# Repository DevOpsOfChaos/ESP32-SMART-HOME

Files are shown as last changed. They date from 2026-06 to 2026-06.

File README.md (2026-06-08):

# ESP32 Smart Home

An open, English-language release of my ESP32-based smart home project.

This repository packages the hardware, firmware, enclosure work, local server stack, and a separate ESPHome track in a way that can be used piece by piece.

What this is not: a polished consumer product or a cloud platform. It is a local-first, technically honest system that can be reused by builders who only want one part of it.

## What is included

- custom ESP32-C3 hardware
- modular PCB designs and production artifacts
- C++ firmware built with PlatformIO
- separate ESPHome device configs for Home Assistant users
- a local MQTT server and Node-RED dashboard
- 3D-printed enclosure designs
- test scripts and verification notes

## System overview

```text
Custom firmware path
  ESP32 devices
    -> ESP-NOW
    -> Master bridge
    -> MQTT
    -> Local server
         -> Mosquitto
         -> Node-RED dashboard and logic
         -> SQLite snapshots

Separate ESPHome path
  ESPHome devices
    -> Home Assistant
    -> Optional local integrations, depending on the device config
```

## Device families

| Family | Purpose | Typical modules |
|---|---|---|
| `net_erl` | mains-powered relay node | hall light, room light, sensor extensions |
| `net_zrl` | shutter / blind controller | two relays, calibration, local buttons |
| `net_sen` | mains-powered sensor node | environmental sensing, rain input |
| `bat_sen` | battery-powered sensor node | reed contact, rain sensor, deep sleep |
| `master` | bridge node | ESP-NOW to MQTT gateway |

## Use each part independently

- Hardware only: build the PCB and enclosure files without using my firmware.
- Firmware only: reuse the PlatformIO project for your own ESP32-C3 builds.
- ESPHome only: flash the Home Assistant-friendly YAMLs and ignore the custom firmware completely.
- Server only: run the local MQTT, Node-RED, and SQLite stack as a standalone dashboard backend.

## Repository map

| Path | Purpose |
|---|---|
| `hardware/` | source boards, shared circuits, enclosures, and manufacturing exports |
| `firmware/` | PlatformIO firmware, device families, shared protocol code |
| `esphome/` | separate Home Assistant-oriented ESPHome configs and migration references |
| `server/` | local Mosquitto, Node-RED, and SQLite stack |
| `docs/` | English overview and legacy reference material |
| `tests/` | smoke tests and contract checks |

Start here if you want the shortest onboarding path:

- [Getting Started](docs/GETTING_STARTED.md)

## Quick start

Run the local dashboard stack:

```powershell
cd server
docker compose up -d
```

Open the dashboard:

```text
http://localhost:1880/ui
```

Build a firmware target:

```powershell
cd firmware
pio run -e <environment-name>
```

Validate the ESPHome configs from the repository root:

```powershell
.\scripts\check_esphome.ps1 -Device <device-name>
```

## ESPHome boundary

The `esphome/` area is not a firmware port of the custom stack. The supported public direction is simpler than that: easy-to-adopt ESPHome devices for people who want straightforward Home Assistant integration without the custom ESP-NOW or master architecture.

Some legacy MQTT-contract ESPHome files still remain in the repository as migration references. They are not the recommended public story.

## Design principle

Every major block is intentionally usable on its own. The full system is the reference implementation, not a mandatory bundle.

## Public release note

This repository is a cleaned public release. Secrets, runtime caches, and internal-only working artifacts are intentionally excluded.

## License

All rights reserved for now. The project is public for review and reuse, but no permissive license has been attached yet.

## Author

Manuel Ries

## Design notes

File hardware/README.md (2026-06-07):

# Hardware

This folder contains the physical side of the project:

- shared reference hardware
- device-specific PCB designs
- manufacturing exports
- enclosure and 3D-print models

## Start here

- [Hardware overview](00_hardwareueberblick.md)

## Main areas

- `shared/` holds reusable circuit blocks and reference components
- `bat_sen/`, `net_sen/`, `net_erl/`, and `net_zrl/` hold device families
- `3d_models/` holds enclosure work, renders, and printable models
- `fabrication/` holds production-ready exports brought in from the final project state

## How to read it

Start with the shared hardware, then move into the relevant device family. Do not assume the whole system is required. Each family is meant to stand on its own.

## Fabrication exports

The `fabrication/` folder is the handoff layer:

- `gerbers/` for PCB production
- `kicad/` for board source files and exports
- `schematics/` for PDFs and schematic handoff material
- `bom/` for bill-of-materials CSV files

## 3D printing

The enclosure work under `3d_models/` is intentionally separate from the PCB source. You can use the boards without the enclosures, or the enclosures without the full software stack.

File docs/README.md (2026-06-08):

# Documentation

This is the English documentation entry point for the public release.

## Start here

1. [Root README](../README.md)
2. [Getting Started](GETTING_STARTED.md)
3. [Hardware overview](../hardware/README.md)
4. [Firmware overview](../firmware/README.md)
5. [Server overview](../server/README.md)
6. [ESPHome overview](../esphome/README.md)

## What is in here

- public overview material
- subsystem reference pages
- a clear split between the custom firmware track and the separate ESPHome track
- an archive area for the original German reference material

## Archive

The old German notes were moved into [`archive/german-reference/`](archive/german-reference/). They are kept for historical reference only. New readers should start with the English landing pages above.

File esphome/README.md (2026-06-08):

# ESPHome

This folder is the separate ESPHome track for people who want simple Home Assistant devices.

The supported public direction is not "the same firmware architecture in YAML." It is the opposite: independent ESPHome devices that do not depend on the custom ESP-NOW transport, the master bridge, or the firmware-side MQTT contract.

## What this folder is for

- straightforward Home Assistant adoption
- device-local logic where it makes sense
- easier reuse of the hardware without adopting the custom firmware stack
- clearer separation from the custom `firmware/` architecture

## What is currently in here

Supported public direction:

- `net_erl_hall_module.yaml`
- `net_erl_hall_module_led_ring.yaml`
- `net_sen_weather_station.yaml`
- `net_zrl_shutter_module.yaml`

These configs are Home Assistant-oriented ESPHome devices using the native ESPHome API.

Legacy migration references still kept in the repo:

- `bat_sen_window_contact.yaml`
- `bat_sen_rain_sensor.yaml`
- `packages/`

Those files still use the older MQTT-contract helper packages. They remain valid, but they are not the simplified public direction anymore.

## Use

Typical workflow:

1. copy the device YAML you actually want into your ESPHome workspace
2. provide your local secrets
3. validate the config
4. flash once by cable, then use OTA
5. adopt the device in Home Assistant

## Validation

Use the Windows helper scripts to validate configuration or compile a device target.

```powershell
.\scripts\check_esphome.ps1
```

Or only validate a specific device:

```powershell
.\scripts\check_esphome.ps1 -Device net_erl_hall_module
```

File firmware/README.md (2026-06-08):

# Firmware

This folder contains the PlatformIO firmware for the custom ESP32-C3 line.

It is the main code path for the project when you want the full custom stack:

- ESP-NOW device communication
- a master bridge to MQTT
- shared protocol and provisioning helpers
- concrete device targets for each hardware family

## Layout

- `src/basetypes/` contains reusable runtime bases for each device family
- `src/devices/` contains concrete device builds
- `include/` contains shared headers and local secret templates
- `lib/` contains protocol, provisioning, and storage helpers
- `scripts/` contains build helpers

## Use this track when

Use `firmware/` if you want full control over timing, provisioning, transport, and the device model.

If you mainly want simpler Home Assistant devices, use the separate `esphome/` folder instead. That is not another variant of this firmware stack. It is its own track.

## Build

Build a target with PlatformIO:

```powershell
cd firmware
pio run -e <environment-name>
```

Upload follows the same pattern once the target is selected.

## Secrets

Do not commit `include/Secrets.h`. Keep the example file as the template and copy it locally when needed.

## What matters here

This is not a generic firmware dump. The useful parts are the reusable protocol layer, the base types, and the concrete device implementations that prove the system works end to end.

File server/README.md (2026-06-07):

# Server

This folder contains the local backend stack for the project.

It is intentionally narrow: MQTT broker, Node-RED logic, and SQLite snapshots. No cloud layer, no remote account system, no unnecessary platform dependencies.

## Role

- Mosquitto as the local MQTT broker
- Node-RED for data ingestion, dashboard logic, and automation flows
- SQLite for lightweight persistence and snapshots

## What the server does

- accepts MQTT traffic from devices and ESPHome nodes
- routes device and master topics
- stores the latest device state
- provides a dashboard for overview and device detail views
- supports limited automations and actuator commands
- keeps the runtime local and inspectable

## What it deliberately does not try to be

- a full home automation platform
- a time-series database
- a generic message archive
- a cloud-controlled remote service
- a giant configuration product

## Start

From the repository root:

```powershell
cd server
Copy-Item .env.example .env
docker compose up -d
```

Open the dashboard:

```text
http://localhost:1880/ui
```

## Local broker warning

If you already use a separate MQTT broker, make sure `server/.env` and the ESPHome secrets point to the same broker. A broker split is the most common reason for a setup that looks correct but appears dead in the dashboard.

## Contract test

Run the smoke test from the repository root:

```powershell
.\tests\server\server_contract_smoke.ps1
```

If the stack is already running:

```powershell
.\tests\server\server_contract_smoke.ps1 -SkipStart
```

The test checks the current server contract, including the latest snapshot fields, ACK-related data, and startup/migration errors.

## Main files

- `docker-compose.yml`
- `.env.example`
- `sqlite/00_schema_phase1.sql`
- `nodered/settings.js`
- `nodered/flows/*.json`
- `nodered/lib/*.js`

## Local-only files

- `.env`
- runtime JSON state under `nodered/`
- local broker authentication data under `config/mosquitto/`
- temporary databases and caches

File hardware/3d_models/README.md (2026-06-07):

# 3D Models

STEP files for the boards and enclosures of the smart home system.

## Overview

| File | Device | Description |
|---|---|---|
| *(to be filled in after import)* | | |

The models can be opened in FreeCAD (free) or Fusion 360.

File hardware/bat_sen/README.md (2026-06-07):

# BAT-SEN Battery Sensor Base Type

> `device_class: bat_sen` | `SH_CLASS_BAT_SEN (0x04)`

## Overview

BAT-SEN is the base type for battery-powered sensor nodes with deep sleep. It is optimized for low standby current.

## KiCad sources

👉 **[kicad/](kicad/)** - full KiCad project

| File | Description |
|---|---|
| `bat_sen.kicad_pro` | project file |
| `bat_sen.kicad_sch` | hierarchical root schematic |
| `Leistungskreis.kicad_sch` | sub-sheet: power gating, battery |
| `Steuerstromkreis.kicad_sch` | sub-sheet: ESP32 + I2C |
| `bat_sen.kicad_pcb` | 2-layer PCB layout |
| `Pinbelegung/Pinbelegung.txt` | GPIO map |
| `Code/SamplecodeBasis.txt` | ESP-NOW deep-sleep example |
| `production/` | BOM, placement, netlist |

### SVG schematics

- [schematics/bat_sen.svg](schematics/bat_sen.svg) - root
- [schematics/bat_sen-Leistungskreis.svg](schematics/bat_sen-Leistungskreis.svg) - power gating
- [schematics/bat_sen-Steuerstromkreis.svg](schematics/bat_sen-Steuerstromkreis.svg) - ESP32

## Power-saving design

- **Power gating:** P-MOSFET (IRF9530, SOT-23) disconnects sensors during deep sleep
- **Zener diode:** BZX55C3V3 (DO-35) - overvoltage protection
- **Voltage divider:** R2+R5 (100k+100k) on GPIO4 - battery monitoring
- **Deep sleep:** about 0.5-0.8 mA board current
- **Wake-up:** timer (RTC) or external interrupt

## Pin map

| GPIO | Function | Note |
|---|---|---|
| GPIO0 | I2C SDA | Optional |
| GPIO1 | I2C SCL | Optional |
| GPIO2 | Setup button | Local bring-up button |
| GPIO4 | Voltage measurement (ADC) | Battery voltage via divider |
| GPIO3-10 | free | header pins |
| GPIO20/21 | UART | debug |

## Battery profiles

| Profile | Type | Voltage | Capacity |
|---|---|---|---|
| `BAT_PROFILE_CR2032` | CR2032 | 3.0V | ~225 mAh |
| `BAT_PROFILE_2X_AA` | 2x AA | 3.0V | ~2500 mAh |
| `BAT_PROFILE_2X_AAA` | 2x AAA | 3.0V | ~1000 mAh |

## Devices

| Device | ID | Sensors | Battery |
|---|---|---|---|
| 👉 [bat_sen_01](devices/bat_sen_01_window_contact/) | window contact | reed switch | 2x AAA in series |
| 👉 [bat_sen_02](devices/bat_sen_02_rain_sensor/) | rain sensor | ADC rain sensor | 2x AA |

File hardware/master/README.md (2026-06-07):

# Master Bridge Base Type

> ESP-NOW ↔ MQTT bridge | `device_class: master` | `SH_CLASS_MASTER (0xFE)`

## Overview

The master is the central bridge between the ESP-NOW mesh network and the MQTT server (Node-RED on a Raspberry Pi).

> **No dedicated PCB design.** The master uses the ESP32-C3 SuperMini Plus V2.0 directly, with no carrier board.

## Hardware

| Property | Value |
|---|---|
| Board | TENSTAR ESP32-C3 SuperMini Plus V2.0 |
| MCU | Espressif ESP32-C3 (RISC-V, 160 MHz) |
| Flash / SRAM | 4 MB / 400 KB |
| Power | 5V DC via USB-C |
| Mode | always on (no sleep) |
| Wi-Fi | 2.4 GHz, connected to the local network |
| MQTT broker | mosquitto on Raspberry Pi |

## Layout

```text
ESP32-C3 SuperMini Plus V2.0
  USB-C -> 5V power
  ESP32-C3 RISC-V MCU
  PCB antenna + U.FL
  WS2812 status LED on GPIO8
  no external circuitry
  no carrier board
  no sensors
```

## Pin usage

| GPIO | Function | Note |
|---|---|---|
| GPIO8 | WS2812 RGB LED | onboard status indicator |
| GPIO20 | UART RX | internal debug |
| GPIO21 | UART TX | internal debug |

All other GPIOs are unused. The master has no sensors, no relays, and no buttons.

## ESP-NOW ↔ MQTT flow

```text
BAT-SEN -> 
NET-SEN -> ESP-NOW -> Master -> MQTT -> Node-RED
NET-ERL ->                 ->           -> SQLite
NET-ZRL ->                             -> Dashboard
```

## Firmware

- **Path:** `firmware/src/basetypes/master_firmware/`
- **main.cpp:** about 2700 lines
- **Platform:** PlatformIO, `espressif32`, Arduino framework

### Core functions

- ESP-NOW peer management and dynamic registry
- MQTT ingest pipeline (`smarthome/device/+/state`)
- JSON serialization of device states
- hello / heartbeat tracking
- diagnostics endpoints

## Device IDs

- **Primary:** `MASTER-001`
- **Fallback:** `MASTER-002`

## Differences vs. other base types

| Property | Master | net_erl / net_zrl | net_sen / bat_sen |
|---|---|---|---|
| Own PCB | no | yes (modular) | yes (single-board) |
| KiCad project | no | yes | yes |
| Sensors | no | optional (I2C) | yes |
| Actuators | no | yes (relays) | no |
| Sleep | no | no | bat_sen: yes |
| Wi-Fi | yes (always on) | no (ESP-NOW only) | no (ESP-NOW only) |
| MQTT | yes | no | no |

## Board reference

👉 [../shared/esp32-c3-supermini.md](../shared/esp32-c3-supermini.md) - technical data for the ESP32-C3 SuperMini Plus

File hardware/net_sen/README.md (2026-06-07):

# NET-SEN - Mains-Powered Sensor Base Type

> `device_class: net_sen` | `SH_CLASS_NET_SEN (0x03)`

## Overview

NET-SEN is the base type for **always-on mains-powered sensor nodes**. No sleep, always online.

## KiCad sources

👉 **[kicad/](kicad/)** - full KiCad project

| File | Description |
|---|---|
| `net_sen.kicad_pro` | project file |
| `net_sen.kicad_sch` | hierarchical root schematic |
| `Leistungskreis.kicad_sch` | sub-sheet: 230V power supply |
| `Steuerstromkreis.kicad_sch` | sub-sheet: ESP32 + I2C |
| `net_sen.kicad_pcb` | 2-layer PCB layout |
| `Bilder/` | layout views (PNG exports) |
| `production/` | BOM, placement, netlist |

### SVG schematics

- [schematics/net_sen.svg](schematics/net_sen.svg) - root
- [schematics/net_sen-Leistungskreis.svg](schematics/net_sen-Leistungskreis.svg) - power supply
- [schematics/net_sen-Steuerstromkreis.svg](schematics/net_sen-Steuerstromkreis.svg) - ESP32

## Board design

Single-board design, not modular:

- **HLK-PM03:** 230V AC -> 3.3V DC
- **Fuse:** 5x20mm
- **I2C:** GPIO0/1 with 4k7 pullups via solder bridges
- **230V input:** Phoenix MKDS 1.5/3

## Pin map

| GPIO | Function |
|---|---|
| GPIO0 | I2C SDA |
| GPIO1 | I2C SCL |
| GPIO2-10 | free (header) |
| GPIO20/21 | UART |

## Versions

1. **Standard version** (active) - in [kicad/](kicad/)
2. **TCA9548APWR version** - with I2C multiplexer (separate KiCad folder)

## Devices

| Device | ID | Sensors |
|---|---|---|
| 👉 [NET-SEN-002](devices/NET-SEN-002_weather_station/) | weather station | BME280, VEML7700, rain sensor |

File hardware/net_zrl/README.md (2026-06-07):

# NET-ZRL - 2-Relay Shutter Base Type

> `device_class: net_zrl` | `SH_CLASS_NET_ZRL (0x02)`

## Overview

NET-ZRL is the base type for **mains-powered two-relay nodes** with shutter / cover control. Safety comes from the serial relay wiring.

## KiCad sources

| Board | Path | Type |
|---|---|---|
| 🔑 Modular control board | [../shared/modularer_steuerkreis/](../shared/modularer_steuerkreis/) | **identical to net_erl** |
| ⚡ Power board (230V) | [leistungskreis/](leistungskreis/) | NET-ZRL specific (2 relays) |

### 2-relay power board

👉 **[leistungskreis_2relais.md](leistungskreis_2relais.md)** - full documentation with BOM

-> KiCad: `Leistungskreis_korrektur.{kicad_pro,sch,pcb}` in [leistungskreis/](leistungskreis/)

-> SVG schematic: [schematics/leistungskreis.svg](schematics/leistungskreis.svg)

-> **Important:** N-channel MOSFETs (IRLZ34N), 2x optocouplers, serial safety circuit

### Control board

👉 **[../shared/modularer_steuerkreis.md](../shared/modularer_steuerkreis.md)** - the same board as net_erl

-> KiCad: [../shared/modularer_steuerkreis/](../shared/modularer_steuerkreis/)

-> SVG: [../shared/schematics/steuerkreis.svg](../shared/schematics/steuerkreis.svg)

## Pin map

| GPIO | Function | Note |
|---|---|---|
| GPIO0 | I2C SDA | Optional |
| GPIO1 | I2C SCL | Optional |
| GPIO5 | Trigger_PIN2 | Relay 2 / Down (via PC817) |
| GPIO10 | Trigger_PIN1 | Relay 1 / Up (via PC817) |
| GPIO20 | RX | UART debug |
| GPIO21 | TX | UART debug |

## Devices

| Device | ID | Special behavior |
|---|---|---|
| 👉 [NET-ZRL-002](devices/NET-ZRL-002_shutter_module/) | shutter control | 2 relays, 3 buttons, calibration |

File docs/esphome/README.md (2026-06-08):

# ESPHome Devices

## Overview

The ESPHome area is the separate Home Assistant-oriented device track in this repository.

The supported public direction is simple:

- Home Assistant-native ESPHome devices
- local device logic where needed
- no dependency on the custom ESP-NOW transport
- no dependency on the master bridge
- no requirement to mirror the firmware-side MQTT contract

That is the whole point. If someone wants simple devices that are easy to adopt in Home Assistant, this is the path.

## Supported current configs

| Device | ESPHome ID | Type | Main role | Notes |
|---|---|---|---|---|
| [NET-ERL-010](devices/NET-ERL-010_hall_module.md) | `net-erl-010` | mains | hall light | local motion + lux automation |
| [NET-ERL-020](devices/NET-ERL-020_hall_module_led_ring.md) | `net-erl-020` | mains | hall light + LED ring | configurable motion hold and ring display |
| [NET-SEN-020](devices/NET-SEN-020_weather_station.md) | `net-sen-020` | mains | weather station | BME280 + VEML7700 + rain input |
| [NET-ZRL-020](devices/NET-ZRL-020_shutter_module.md) | `net-zrl-020` | mains | shutter controller | native HA cover entity with local calibration |

These four files are the public direction that matches the current repo messaging.

## Legacy migration references

| Device | Status | Why it is different |
|---|---|---|
| [bat_sen_010](devices/bat_sen_010_window_contact.md) | legacy / transitional | still uses the older MQTT-contract helper packages |
| [bat_sen_020](devices/bat_sen_020_rain_sensor.md) | legacy / transitional | still uses the older MQTT-contract helper packages |

Those files are still valid ESPHome configs, but they belong to the older migration path. They are not the clean "simple Home Assistant device" story anymore.

## Shared usage pattern

1. Copy the target YAML into your ESPHome workspace.
2. Provide the required secrets.
3. Validate the config.
4. Flash the device once by cable.
5. Use OTA and Home Assistant adoption after that.

## Validation

From the repository root:

```powershell
.\scripts\check_esphome.ps1
```

Or validate one target:

```powershell
.\scripts\check_esphome.ps1 -Device net_zrl_shutter_module
```

## Important boundary

Do not promise more uniformity than the repo actually has.

`firmware/` is the full custom architecture.

`esphome/` is the easier Home Assistant track.

Some legacy MQTT-oriented ESPHome files still exist during the transition, and the docs now call that out explicitly instead of pretending everything is one unified stack.

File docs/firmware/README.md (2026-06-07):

# Firmware Documentation

This folder contains the technical reference for the ESP32-C3 firmware line, the ESP-NOW binary protocol, the MQTT contract, and the device type model.

## Structure

| File | Description |
|---|---|
| `01_espnow_protokoll_referenz.md` | ESP-NOW binary protocol: header, payloads, CRC, event system |
| `02_devicetypes_capabilities.md` | device classes, power types, control modes, profiles, capability bitmask |
| `03_mqtt_contract_referenz.md` | MQTT topics, JSON schemas, ACK mechanism, cover contract |
| `devices/NET-ERL-001_hall_module.md` | hall module (PIR + BME280 + VEML7700 + relay) |
| `devices/NET-ERL-002_hall_module_led_ring.md` | extended hall module (radar + BME680 + ENS160 + NeoPixel + relay) |
| `devices/NET-ZRL-002_shutter_module.md` | shutter module (2 relays, 3 buttons, calibration, position estimate) |
| `devices/NET-SEN-002_weather_station.md` | weather sensor (BME280 + VEML7700 + digital rain input) |
| `devices/bat_sen_01_window_contact.md` | battery window contact (reed, CR2032, GPIO wake) |
| `devices/bat_sen_02_rain_sensor.md` | battery rain sensor (ADC, hysteresis, timer wake) |

## Device comparison

| Feature | NET-ERL-001 | NET-ERL-002 | NET-ZRL-002 | NET-SEN-002 | bat_sen_01 | bat_sen_02 |
|---|---|---|---|---|---|---|
| Class | NET_ERL (0x01) | NET_ERL (0x01) | NET_ZRL (0x02) | NET_SEN (0x03) | BAT_SEN (0x04) | BAT_SEN (0x04) |
| Power | mains | mains | mains | mains | CR2032 | 2x AA |
| Control | relay_light | relay_light | cover | none | none | none |
| Profile | hall_light | hall_module_led_ring | cover_basic | none | none | none |
| Reporting | hybrid | hybrid | hybrid | hybrid | sleep_event | sleep_event |
| Sensors | BME280, VEML7700, PIR | BME680, VEML7700, ENS160, LD2410 | - | BME280, VEML7700, rain | reed (GPIO) | ADC rain |
| Actuators | 1 relay | 1 relay + NeoPixel | 2 relays (cover) | - | - | - |
| Buttons | - | 1 (GPIO6, active-low) | 3 (GPIO20/4/3) | - | - | - |
| Status LEDs | - | - | 2 (up=GPIO7, down=GPIO6, active-high) | - | - | - |
| ESP-NOW payload | 31B (config) | 45B (gas + config) | 25B (config) | 24-36B (ext) | 24B | 24B |
| Wake | n/a | n/a | n/a | n/a | GPIO + timer | timer (900s) |
| Setup portal | yes | yes | yes | yes | yes | yes |

## Design principles

- base type architecture (`NetErlRuntime`, `NetSenRuntime`, `BatSenRuntime`)
- device-specific hooks (`on_config`, `on_sensor`, `on_control`)
- ESP-NOW retry mechanism with 2 retries at 50 ms
- sensor recovery with damped error logging and automatic re-init
- late-lux principle for auto-light behavior after a PIR trigger
- calibration with rollback on write failure

## Quick links

- ESP-NOW protocol: [01_espnow_protokoll_referenz.md](01_espnow_protokoll_referenz.md)
- device types: [02_devicetypes_capabilities.md](02_devicetypes_capabilities.md)
- MQTT contract: [03_mqtt_contract_referenz.md](03_mqtt_contract_referenz.md)
- all devices: [devices/](devices/)

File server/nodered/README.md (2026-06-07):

# Node-RED

This folder contains the Node-RED runtime for the local server and dashboard path.

## Purpose

- `flows/active/` holds the production flow fragments
- `lib/` contains helper modules for routing, handlers, and SQL helpers
- `settings.js` is the base Node-RED settings file
- the real startup path is in `../docker-compose.yml`, where SQLite, schema preparation, `flows.json`, and runtime settings are assembled during container startup

## Active features

- MQTT ingestion
- device and master state storage
- overview and detail dashboard views
- automation persistence and runner logic

## Not part of this layer

- weather aggregation
- charts and historical analytics
- broad command-console features
- large generator or editor tooling

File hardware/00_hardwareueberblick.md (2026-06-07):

# Hardware Overview

> Status: May 2026 | Platform: ESP32-C3 (RISC-V) | Design tool: KiCad 9.0

## Architecture

All devices in this project are based on the **TENSTAR ESP32-C3 SuperMini Plus V2.0** (ESP32-C3, RISC-V 32-bit, 160 MHz, 4 MB flash, 400 KB SRAM, Wi-Fi b/g/n, BLE 5.0). The microcontroller is mounted on the carrier boards through a through-hole adapter board (`ESP32-C3_SUPERMINI_TH`).

Communication uses **ESP-NOW** for node-to-master traffic and **MQTT** for master-to-server traffic.

## Device families

| Family | Type | PCB design | Power | Quantity |
|---|---|---|---|---|
| `net_erl` | 1-relay node | Modular relay board | 230 V AC via HLK-5M05 | 2 devices |
| `net_zrl` | 2-relay blind controller | Modular relay board | 230 V AC via HLK-5M05 | 1 device |
| `net_sen` | Mains-powered sensor node | Mains sensor board | 230 V AC via HLK-PM03 | 1 device |
| `bat_sen` | Battery-powered sensor node | Battery sensor board | Battery / accumulator | 2 devices |
| `master` | Bridge node | ESP-NOW to MQTT bridge | 230 V AC | 1 device |

## Modular relay board design

All relay nodes (`net_erl`, `net_zrl`) use a **two-part modular design**:

1. **Control board** (`mod_Steuerkreis_ESP32`) - identical for all relay variants
   - ESP32-C3 SuperMini on a through-hole adapter
   - I2C pull-ups (4.7 kOhm, switchable by solder bridge)
   - GPIO pin headers for sensors
   - 5 test points for debugging
   - 2x M3 mounting holes

2. **Power board** - varies by relay type
   - `net_erl`: 1x relay (HF46F), 1x P-channel MOSFET (FQP27P06), 1x optocoupler (PC817)
   - `net_zrl`: 2x relays (HF46F), 2x N-channel MOSFETs (IRLZ34N), 2x optocouplers (PC817)
   - Both: Hi-Link AC/DC converter (230 V -> 5 V), resettable fuse (5x20 mm), 230 V terminals

The two boards are connected through a 5-pin JST-PH cable (5 V, GND, GPIO10, GPIO5, 3V3).

## Pin map matrix

| GPIO | BAT-SEN | NET-SEN | NET-ERL | NET-ZRL | Function |
|---|---|---|---|---|---|
| 0 | I2C SDA | I2C SDA | I2C SDA | I2C SDA | I2C data |
| 1 | I2C SCL | I2C SCL | I2C SCL | I2C SCL | I2C clock |
| 2 | Battery voltage sense | free | NC | NC | Battery ADC |
| 3 | free | free | NC | NC | - |
| 4 | free | free | LED ring (NET-ERL-002) | NC | WS2812 data pin for LED-ring module |
| 5 | free | free | Trigger_PIN2 | Trigger_PIN2 (down) | Relay 2 |
| 6 | free | free | free | free | - |
| 7 | free | free | free | free | - |
| 8 | free | free | free | free | Onboard LED |
| 9 | free | free | NC | NC | - |
| 10 | free | free | Trigger_PIN1 | Trigger_PIN1 (up) | Relay 1 |
| 20 | RX | RX | RX | RX | UART RX |
| 21 | TX | TX | TX | TX | UART TX |

## Power designs

| Type | Input | Converter | Output | Special note |
|---|---|---|---|---|
| BAT-SEN | Battery (3.0-4.2 V) | None (P-MOSFET gate, Zener protection) | 3.3 V (LDO on ESP board) | Deep-sleep optimized |
| NET-SEN | 230 V AC | HLK-PM03 | 3.3 V DC | Resettable fuse |
| NET-ERL power board | 230 V AC | HLK-5M05 | 5 V DC | Powers relay coil and ESP |
| NET-ZRL power board | 230 V AC | HLK-5M05 | 5 V DC | Powers 2 relay coils and ESP |

## Core design patterns

1. **I2C solder bridges (JP1/JP2):** the 4.7 kOhm I2C pull-ups can be enabled or disabled on every board by solder bridge
2. **Optocoupler isolation (PC817):** galvanic separation between the ESP GPIOs and the relay MOSFET drivers
3. **Flyback diodes (1N4007):** protection against inductive spikes from relay coils
4. **Test points (TP1-TP5):** debugging access on the modular control board
5. **Sensor pin headers:** all boards break out GPIOs, GND, and VCC on headers for external sensors

## Directory structure

```text
hardware/
├── 00_hardwareueberblick.md              ← this file
│
├── shared/                               ← shared design blocks
│   ├── esp32-c3-supermini.md             ← ESP32-C3 platform reference
│   ├── modularer_steuerkreis.md          ← control-board documentation (BOM, pins)
│   ├── komponenten.md                    ← component catalog
│   ├── esp32-c3-supermini/               ← KiCad: through-hole adapter
│   ├── modularer_steuerkreis/            ← KiCad: control board (shared by all relay nodes)
│   └── schematics/                       ← SVG schematics
│
├── master/                               ← master bridge
│   └── README.md
│
├── net_erl/                              ← base type: 1 relay
│   ├── README.md                         ← overview + pin map
│   ├── leistungskreis_1relais.md         ← power-board documentation
│   ├── leistungskreis/                   ← KiCad: power board
│   ├── simulation/                       ← LTSpice
│   ├── schematics/                       ← SVG schematics
│   └── devices/                          ← concrete device variants
│       ├── NET-ERL-001_hall_module/
│       └── NET-ERL-002_hall_module_led_ring/
│
├── net_zrl/                              ← base type: 2 relay / blind controller
│   ├── README.md
│   ├── leistungskreis_2relais.md
│   ├── leistungskreis/                   ← KiCad: power board (2 relays)
│   ├── schematics/
│   └── devices/
│       └── NET-ZRL-002_shutter_module/
│
├── net_sen/                              ← base type: mains sensor
│   ├── README.md
│   ├── kicad/                            ← KiCad: mains-sensor board
│   ├── schematics/
│   └── devices/
│       └── NET-SEN-002_weather_station/
│
└── bat_sen/                              ← base type: battery sensor
    ├── README.md
    ├── kicad/                            ← KiCad: battery-sensor board
    ├── schematics/
    └── devices/
        ├── bat_sen_01_window_contact/
        └── bat_sen_02_rain_sensor/
```

> **Legend:** `← KiCad:` = original KiCad project files (`.kicad_pro`, `.kicad_sch`, `.kicad_pcb`, BOM, STEP)

## KiCad sources

| Base type | Control board | Power board / board |
|---|---|---|
| **net_erl** | [shared/modularer_steuerkreis/](shared/modularer_steuerkreis/) | [net_erl/leistungskreis/](net_erl/leistungskreis/) |
| **net_zrl** | [shared/modularer_steuerkreis/](shared/modularer_steuerkreis/) | [net_zrl/leistungskreis/](net_zrl/leistungskreis/) |
| **net_sen** | - (single-board) | [net_sen/kicad/](net_sen/kicad/) |
| **bat_sen** | - (single-board) | [bat_sen/kicad/](bat_sen/kicad/) |
| **master** | - (no dedicated PCB) | - |

## Main components

| Component | Type | Used in |
|---|---|---|
| ESP32-C3 SuperMini Plus V2.0 | Microcontroller | All devices |
| ESP32-C3_SUPERMINI_TH | Through-hole adapter | All devices |
| HLK-5M05 | AC/DC converter 230 V -> 5 V | NET-ERL, NET-ZRL |
| HLK-PM03 | AC/DC converter 230 V -> 3.3 V | NET-SEN |
| Hongfa HF46F/5-HS1 | 5 V / 10 A relay | NET-ERL (1x), NET-ZRL (2x) |
| PC817 | Optocoupler | NET-ERL (1x), NET-ZRL (2x) |
| FQP27P06 | P-channel MOSFET, TO-220 | NET-ERL |
| IRLZ34N | N-channel MOSFET, TO-220 | NET-ZRL |
| 1N4007 | Flyback diode | All relay boards |
| BME280 | Temp / humidity / pressure (I2C 0x76) | NET-ERL-001, NET-SEN-002 |
| BME680 | Temp / humidity / pressure / gas (I2C 0x76) | NET-ERL-002 |
| VEML7700 | Lux sensor (I2C 0x10) | NET-ERL-001/002, NET-SEN-002 |
| ENS160 | MOX gas sensor (I2C 0x52) | NET-ERL-002 |
| LD2410 | Radar presence sensor (UART) | NET-ERL-002 |
| NeoPixel ring (12 LEDs) | WS2812 | NET-ERL-002 |
| BZX55C3V3 | 3.3 V Zener diode | BAT-SEN |
| IRF9530 | P-channel MOSFET, SOT-23 | BAT-SEN |

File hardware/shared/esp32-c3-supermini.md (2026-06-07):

# ESP32-C3 SuperMini Plus V2.0 - Platform Reference

> All devices in this project use the TENSTAR ESP32-C3 SuperMini Plus V2.0.

## Technical data

| Property | Value |
|---|---|
| Microcontroller | Espressif ESP32-C3 (RISC-V, 32-bit) |
| CPU clock | up to 160 MHz |
| Flash | 4 MB |
| SRAM | 400 KB |
| Wi-Fi | 802.11 b/g/n (2.4 GHz) |
| Bluetooth | BLE 5.0 |
| USB | Native USB-CDC + JTAG |
| ADC | 12-bit, up to 6 usable channels |
| PWM | Available on almost all GPIOs |
| Supply voltage | 5 V (USB / VIN) |
| Logic voltage | 3.3 V |
| Onboard LDO | ME6211 / XC6206 / AMS1117 clone |
| Max. output current (3.3 V) | approx. 500 mA |

## Current draw

| Mode | Current |
|---|---|
| Wi-Fi TX peak | approx. 300 mA |
| Idle (Wi-Fi connected) | 70-80 mA |
| Light sleep | approx. 5 mA |
| Deep sleep (chip only) | approx. 40 uA |
| Deep sleep (whole board) | approx. 0.5-0.8 mA |

## Onboard peripherals

| Component | Pin / detail |
|---|---|
| Power LED | Red (hard-wired) |
| User LED | Blue (GPIO8) |
| RGB LED | WS2812 (GPIO8) |
| Reset button | EN |
| Boot button | GPIO9 |
| Antenna | PCB antenna + U.FL connector |

> **Note:** The blue LED and the RGB LED share GPIO8. They cannot be used at the same time.

## Through-hole adapter (`ESP32-C3_SUPERMINI_TH`)

For use on the project boards, the SuperMini board is mounted on a **through-hole adapter board**:

- KiCad symbol: `ESP32-C3_SUPERMINI_TH.kicad_sym`
- Footprint: `MODULE_ESP32-C3_SUPERMINI_TH.kicad_mod`
- 3D model: `ESP32-C3_SUPERMINI_TH.step`
- Makes the module easy to insert and replace on 2x10 pin headers

## Available GPIOs on the adapter

| Pin | Function | Analog | Special note |
|---|---|---|---|
| GPIO0 | I2C SDA / free | yes | ADC1_CH0 |
| GPIO1 | I2C SCL / free | yes | ADC1_CH1 |
| GPIO2 | free | yes | ADC1_CH2 |
| GPIO3 | free | yes | ADC1_CH3 |
| GPIO4 | free | yes | ADC1_CH4 |
| GPIO5 | free | yes | ADC2_CH0 |
| GPIO6 | free | no | - |
| GPIO7 | free | no | - |
| GPIO8 | free (LED) | no | Onboard WS2812 |
| GPIO9 | Boot button | no | Not usable as regular I/O |
| GPIO10 | free | no | - |
| GPIO20 | RX / free | no | UART |
| GPIO21 | TX / free | no | UART |

> **Strapping pins:** GPIO2, GPIO8, and GPIO9 affect boot behavior. GPIO9 is not usable during normal operation.

## Interfaces

- **UART:** 2x (RX/TX on GPIO20/21)
- **I2C:** 1x (SDA/SCL on GPIO0/1)
- **SPI:** Available on GPIO4-7
- **ADC:** 12-bit, up to 6 channels (GPIO0-5)
- **PWM:** On almost all GPIOs
- **USB-CDC:** Native USB serial for programming and debug
- **USB-JTAG:** On-chip debugger

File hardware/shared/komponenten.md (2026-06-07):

# Shared Component Reference

This page lists the component families that appear across the hardware designs in this repository.

## Related KiCad sources

| Component | KiCad files |
|---|---|
| ESP32-C3 SuperMini Plus V2.0 | `esp32-c3-supermini/` |
| ESP32-C3_SUPERMINI_TH | `esp32-c3-supermini/` |
| Modular control board | `modularer_steuerkreis/` |
| Relay boards | `net_erl/leistungskreis/`, `net_zrl/leistungskreis/` |

## Microcontrollers and adapters

### ESP32-C3 SuperMini Plus V2.0

The main MCU module used throughout the project. It is documented separately in [`esp32-c3-supermini.md`](esp32-c3-supermini.md).

### ESP32-C3_SUPERMINI_TH

Through-hole adapter board for mounting the SuperMini module on the project PCBs. It is used wherever the module needs to be socketed or replaced easily.

## Power supplies

### HLK-5M05

Hi-Link AC/DC converter used for 230 V AC to 5 V DC conversion on relay boards.

### HLK-PM03

Hi-Link AC/DC converter used for 230 V AC to 3.3 V DC conversion on the mains-powered sensor board.

## Relays

### Hongfa HF46F/5-HS1

5 V relay used on the relay boards. The design supports one relay on `net_erl` and two relays on `net_zrl`.

## Optocouplers

### PC817

Optocoupler used for galvanic isolation between the control side and the relay driver side.

## MOSFETs

### FQP27P06

P-channel MOSFET in TO-220 package, used on the single-relay board.

### IRLZ34N

N-channel MOSFET in TO-220 package, used on the dual-relay board.

### IRF9530

P-channel MOSFET in SOT-23 package, used on the battery-powered sensor designs.

## Diodes

### 1N4007

Flyback diode used on relay boards to protect against inductive spikes.

### BZX55C3V3

3.3 V Zener diode used in the battery-powered supply path.

## Sensors

### BME280

Temperature, humidity, and pressure sensor used on selected devices.

### BME680

Temperature, humidity, pressure, and gas sensor used on the LED-ring relay module.

### VEML7700

Lux sensor used on the relay and mains-sensor devices.

### ENS160

MOX gas sensor used on the LED-ring relay module.

### AHT21

Temperature and humidity sensor used on some legacy or alternate sensor layouts.

### LD2410

Radar presence sensor used on the LED-ring relay module.

### HC-SR501

PIR motion sensor used in some experimental or supporting setups.

## Passive parts

Common passive parts are used project-wide where necessary:

- resistors for pull-ups, dividers, and LEDs
- capacitors for decoupling and smoothing
- connectors and headers for board interconnects
- fuses and protection parts where mains voltage is involved

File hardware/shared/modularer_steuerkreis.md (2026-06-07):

# Modular Control Board (`mod_Steuerkreis_ESP32`)

## KiCad sources

The full KiCad project files are stored under:

[`shared/modularer_steuerkreis/`](modularer_steuerkreis/)

## Overview

The modular control board is the shared controller board for all relay-based devices in this project. It hosts the ESP32-C3 module and the reusable support circuitry that is common to `net_erl` and `net_zrl`.

## Bill of materials

| Component | Value / type | Quantity | Notes |
|---|---|---:|---|
| `IC1` | ESP32-C3 SuperMini Plus V2.0 | 1 | MCU module |
| `AD1` | ESP32-C3_SUPERMINI_TH | 1 | Through-hole adapter |
| `R1`, `R2` | 4.7 kOhm | 2 | I2C pull-ups, switchable by solder bridge |
| `R3` | 100 Ohm | 1 | LED / signal resistor |
| `R4` | 10 kOhm | 1 | Reset / pull-up support |
| `C1` | 100 nF | 1 | Decoupling |
| `C2` | 10 uF | 1 | Local supply buffer |
| `J1` | JST-PH 5-pin | 1 | Cable to the power board |
| `J2` | Header | 1 | Sensor breakout |
| `TP1-TP5` | Test points | 5 | Debug access |

## Pin mapping

### Control board to power board

| Signal | ESP32-C3 pin | Power board use |
|---|---|---|
| `5V` | VIN | Board supply |
| `GND` | GND | Common ground |
| `GPIO10` | GPIO10 | Relay control / trigger |
| `GPIO5` | GPIO5 | Second relay control / trigger |
| `3V3` | 3.3 V rail | Logic reference / sensors |

### GPIO breakouts

| GPIO | Breakout usage |
|---|---|
| GPIO0 | I2C SDA |
| GPIO1 | I2C SCL |
| GPIO2 | Sensor input / ADC |
| GPIO3 | Free |
| GPIO4 | LED ring data on `NET-ERL-002` |
| GPIO5 | Relay 2 / trigger |
| GPIO6 | Free |
| GPIO7 | Free |
| GPIO8 | Onboard LED |
| GPIO9 | Boot strap, not a normal I/O |
| GPIO10 | Relay 1 / trigger |
| GPIO20 | UART RX |
| GPIO21 | UART TX |

## SVG schematic

The board schematic is exported as SVG for quick inspection and documentation.

## Compatibility

| Item | Status |
|---|---|
| KiCad sources | [`shared/modularer_steuerkreis/`](modularer_steuerkreis/) |
| Relay families | `net_erl`, `net_zrl` |
| Sensor breakouts | Shared GPIO headers |
| Power board link | 5-pin JST-PH cable |

## Design features

- Shared control board for both relay families
- Switchable I2C pull-ups
- Sensor and debug breakouts
- Simple board-to-board cabling
- Designed for replacement without redesigning the whole device

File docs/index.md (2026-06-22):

---
layout: default
title: ESP32 Smart Home (legacy)
permalink: /legacy-index/
---

# ESP32 Smart Home

This is the public landing page for the repository.

The project has two separate technical tracks:

| Track | Purpose | Core path |
|---|---|---|
| Custom firmware | Full project architecture | ESP-NOW -> Master -> MQTT -> local server |
| ESPHome | Simple Home Assistant adoption | ESPHome API -> Home Assistant |

That separation matters. ESPHome is not the same runtime stack rewritten in YAML. It is the simpler path for people who want devices that fit naturally into Home Assistant.

## What the repository contains

- custom ESP32-C3 hardware
- a custom firmware stack with ESP-NOW and a master bridge
- a local server stack with Mosquitto, Node-RED, and SQLite
- a separate ESPHome track for Home Assistant users
- enclosure and fabrication assets
- validation scripts and notes

## Current ESPHome direction

The supported public ESPHome direction is Home Assistant-native and intentionally independent from the custom firmware architecture.

Supported current configs:

- `NET-ERL-010` hall module
- `NET-ERL-020` hall module with LED ring
- `NET-SEN-020` weather station
- `NET-ZRL-020` shutter module

Some older ESPHome MQTT-contract files still remain in the repository as migration references. They are transitional material, not the main public story.

## Current custom firmware direction

The custom firmware remains the core architecture for the full project:

- ESP-NOW between devices and the master
- MQTT between the master and the server
- Node-RED as the current dashboard and automation layer
- hardware-specific device firmware built on shared base types

## Read the right thing

- [Documentation](../docs/README.md)
- [Firmware](../firmware/README.md)
- [ESPHome](../esphome/README.md)
- [Server](../server/README.md)
- [Hardware](../hardware/README.md)
- [Tests](../tests/README.md)
- [Archive](../docs/archive/README.md)

## Reality check

This repository is a documented engineering project, not a polished product platform.

If you want the full original architecture, use `firmware/`.

If you want the easier Home Assistant path, use `esphome/`.

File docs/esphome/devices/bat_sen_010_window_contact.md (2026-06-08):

# bat_sen_010 Window Contact

## Status

This file is a legacy ESPHome migration reference.

It is still valid, but it does not match the newer Home Assistant-native direction used by the current `net_*` ESPHome configs. It still uses the older MQTT-contract helper packages and deep-sleep reporting model.

## Overview

`bat_sen_010` is a battery-powered window contact with:

- reed contact input
- battery voltage reporting
- deep sleep
- MQTT-based state publishing

## Hardware Mapping

| Component | Pin | Notes |
|---|---|---|
| Reed contact | `GPIO3` | wake source and window state input |
| Setup button | `GPIO2` | manual setup / wake handling |
| Battery ADC | `GPIO4` | voltage measurement |

## Runtime Model

Typical wake cycle:

1. Wake by timer or contact change.
2. Read reed contact and battery voltage.
3. Connect to Wi-Fi and MQTT.
4. Publish availability, meta, state, and any event.
5. Keep a short receive window open for commands.
6. Return to deep sleep.

## Current Behavior

- sleep interval default: `900 s`
- receive window default: `5000 ms`
- contact changes can wake the device
- battery percentage is derived from the measured voltage

## Current ESPHome File

- [bat_sen_window_contact.yaml](D:/LocalRepos/esp32-smart-home/esphome/devices/bat_sen_window_contact.yaml)

## Important Note

This device is kept in the repo as a migration reference. If you want the current simpler public ESPHome direction, start with the `net_*` configs instead.

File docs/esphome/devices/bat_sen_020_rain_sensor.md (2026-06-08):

# bat_sen_020 Rain Sensor

## Status

This file is a legacy ESPHome migration reference.

It is still valid, but it belongs to the older MQTT-contract ESPHome path rather than the newer Home Assistant-native direction used by the current `net_*` configs.

## Overview

`bat_sen_020` is a battery-powered rain sensor with:

- analog rain input
- battery voltage reporting
- hysteresis-based wet/dry detection
- deep sleep
- MQTT-based reporting

## Hardware Mapping

| Component | Pin | Notes |
|---|---|---|
| Rain ADC | `GPIO3` | analog rain measurement |
| Setup button | `GPIO2` | manual setup / wake handling |
| Battery ADC | `GPIO4` | voltage measurement |

## Runtime Model

Typical wake cycle:

1. Wake by timer.
2. Read rain ADC and battery voltage.
3. Apply wet/dry hysteresis.
4. Connect to Wi-Fi and MQTT.
5. Publish availability, meta, state, and any event.
6. Keep a short receive window open for commands.
7. Return to deep sleep.

## Current Behavior

- sleep interval default: `900 s`
- receive window default: `5000 ms`
- wet threshold: `2200`
- clear threshold: `2050`

## Current ESPHome File

- [bat_sen_rain_sensor.yaml](D:/LocalRepos/esp32-smart-home/esphome/devices/bat_sen_rain_sensor.yaml)

## Important Note

This device remains in the repository because it still compiles and documents useful hardware behavior, but it is not the lead public ESPHome story anymore.

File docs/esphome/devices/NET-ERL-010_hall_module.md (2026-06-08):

# NET-ERL-010 Hall Module

## Overview

`NET-ERL-010` is a plain ESPHome hall-light controller for Home Assistant.

The device keeps the actual motion-light logic locally on the ESP, so it still works even if Home Assistant is temporarily unavailable. Home Assistant is used to view the entities and change the configuration values.

## Current Features

- One relay exposed as a light
- One PIR motion sensor
- One VEML7700 illuminance sensor
- Local automatic switch-on when motion is detected and the lux value is below the configured threshold
- Local automatic switch-off after the configured delay once motion ends
- Home Assistant entities for changing the automation settings
- Lux polling only while the light is off, to avoid pointless self-illumination readings

Temperature and humidity are intentionally not part of this device anymore.

## Exposed Entities

After flashing and adopting the device, Home Assistant should show entities similar to these:

- `light.net_erl_hall_module_light`
- `binary_sensor.net_erl_hall_module_motion`
- `sensor.net_erl_hall_module_illuminance`
- `switch.net_erl_hall_module_auto_light`
- `number.net_erl_hall_module_lux_threshold`
- `number.net_erl_hall_module_auto_off_delay`

Entity IDs can differ slightly depending on your naming conventions in Home Assistant.

## Hardware Mapping

| Component | Pin / Bus | Notes |
| --- | --- | --- |
| Relay | `GPIO10` | Exposed as a light |
| PIR motion sensor | `GPIO7` | Exposed as a motion binary sensor |
| VEML7700 | `I2C`, `SDA=GPIO0`, `SCL=GPIO1`, `0x10` | Exposed as illuminance, polled only while light is off |

## Automation Behavior

The local device logic works like this:

1. Motion goes `on`
2. The device checks whether auto-light is enabled
3. The device checks whether the VEML7700 has a valid lux reading
4. The device compares the current lux value against the configured threshold
5. If the measured lux is at or below the threshold and the light is currently off, the relay turns on
6. When motion goes `off`, the device starts an internal off-timer
7. If motion is detected again before the timer expires, the timer is cancelled
8. If the timer expires and motion is still off, the light turns off

The VEML7700 is not continuously polled. It is updated once per minute and only while the light is off. That avoids wasting reads and avoids using obviously contaminated lux values caused by the lamp itself.

This means the basic automation does not depend on a live Home Assistant connection.

## Configurable Values

These settings are exposed to Home Assistant as normal entities:

### Auto Light

- Entity: `switch.net_erl_hall_module_auto_light`
- Type: on/off
- Purpose: enables or disables the local automation

If disabled, the device stops doing automatic on/off control. The light can still be switched manually from Home Assistant.

### Lux Threshold

- Entity: `number.net_erl_hall_module_lux_threshold`
- Unit: `lx`
- Default: `80`
- Range: `0` to `1000`

The light only turns on automatically if the measured illuminance is less than or equal to this value.

### Auto Off Delay

- Entity: `number.net_erl_hall_module_auto_off_delay`
- Unit: `s`
- Default: `120`
- Range: `10` to `1800`

This is the run-on time after motion ends.

## Important Behavior Details

### Manual Light Control

If the light is turned on manually while auto-light is enabled, the device does not automatically assume that this was an automation-triggered light cycle. Auto-off is only applied to light cycles that were started automatically by the device.

That is intentional. Otherwise the automation would interfere with manual control too aggressively.

### No Fallback Access Point

The current configuration does not use an ESPHome fallback AP or `captive_portal`.

That keeps the device simpler, but it also means:

- if Wi-Fi credentials are wrong
- or the WLAN environment changes badly

you do not have a built-in wireless recovery path. In that case you need to reflash or recover the device another way.

## Current ESPHome File

The live device configuration is:

- [net_erl_hall_module.yaml](D:/LocalRepos/esp32-smart-home/esphome/devices/net_erl_hall_module.yaml)

## Verification Checklist

Do not trust assumptions. Verify the real behavior:

1. Confirm the device appears online in Home Assistant.
2. Confirm the motion entity switches between `off` and `on`.
3. Confirm the illuminance sensor reports plausible values.
4. Set the lux threshold high enough to force an automatic switch-on test.
5. Trigger motion and confirm the light turns on locally.
6. Stop moving and confirm the light turns off after the configured delay.
7. Trigger motion again during the delay and confirm the timer is cancelled.
8. Turn the light on manually and confirm that manual control is not unexpectedly forced back off by an unrelated old timer.

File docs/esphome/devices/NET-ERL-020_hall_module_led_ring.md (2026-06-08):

# NET-ERL-020 Hall Module LED Ring

## Overview

`NET-ERL-020` is a Home Assistant-oriented ESPHome hall-light device with a local relay, a PIR motion input, a VEML7700 lux sensor, and a configurable 17-pixel LED ring.

This is no longer an ESPHome version of the old firmware feature stack. The current config is simpler and more honest:

- one local hall light
- one local motion state with hold time
- one local lux-based auto-light rule
- one configurable LED ring display

The old BME680, ENS160, and firmware-contract story does not describe the current YAML anymore.

## Exposed Entities

Typical Home Assistant entities from the current config:

- `light.hall_light`
- `binary_sensor.motion_detected`
- `sensor.ambient_illuminance`
- `switch.automatic_light_control`
- `switch.led_ring_motion_display`
- `number.motion_hold_time`
- `number.auto_light_lux_threshold`
- `number.led_ring_brightness_percent`
- `number.led_ring_color_red`
- `number.led_ring_color_green`
- `number.led_ring_color_blue`
- `number.led_ring_source_value`
- `number.led_ring_scale_minimum`
- `number.led_ring_scale_maximum`
- `number.led_ring_animation_speed`
- `select.led_ring_animation_mode`

Exact entity IDs can vary after adoption.

## Hardware Mapping

| Component | Pin / Bus | Notes |
|---|---|---|
| Relay | `GPIO10` | exposed as `Hall Light` |
| PIR | `GPIO7` | raw motion input |
| Local button | `GPIO6` | toggles the relay |
| VEML7700 | `I2C`, `SDA=GPIO0`, `SCL=GPIO1`, `0x10` | ambient lux input |
| LED ring | `GPIO4` | 17x WS2812B, `GRB` order |

## Local Motion Logic

The PIR does not map directly to the public motion entity.

Instead, the config keeps a held motion state:

1. Raw PIR goes high.
2. Motion becomes active immediately.
3. `Motion Hold Time` starts extending the active state.
4. After the raw PIR goes low, the held motion state remains on until the hold timer expires.

That makes the visible motion state less twitchy and gives the light logic a usable persistence window.

## Auto-Light Logic

The light logic is local to the ESP:

1. `Automatic Light Control` must be enabled.
2. Held motion must be active.
3. The lux value must be valid.
4. Lux must be at or below `Auto Light Lux Threshold`.
5. The relay turns on and the device marks the light as automation-owned.
6. When motion ends, the automation-owned light turns back off.

If the light was turned on manually, the config does not blindly treat it as automation-owned.

## LED Ring Logic

The LED ring is a local display, not a server contract feature.

It only lights while both of these are true:

- `LED Ring Motion Display` is enabled
- the held motion state is active

The visible bar is driven by `LED Ring Source Value`, mapped between the configured minimum and maximum scale values.

Available animation modes:

- `Static Bar`
- `Pulse Bar`
- `Comet Bar`
- `Scanner Bar`

Color and brightness are fully user-configurable from Home Assistant.

## Connectivity and Recovery

This device uses:

- ESPHome native API
- OTA password
- fallback AP with captive portal

Fallback AP:

- SSID: `net-erl-020-setup`
- password: `net-erl-setup`

## Current ESPHome File

- [net_erl_hall_module_led_ring.yaml](D:/LocalRepos/esp32-smart-home/esphome/devices/net_erl_hall_module_led_ring.yaml)

## Verification Checklist

1. Confirm the relay can be toggled from Home Assistant.
2. Confirm the local button toggles the relay.
3. Confirm `Motion Detected` stays on for the configured hold time.
4. Confirm the light only auto-turns on when lux is below the configured threshold.
5. Confirm the light turns back off when motion has ended.
6. Confirm the LED ring only lights while motion display is enabled and motion is active.
7. Confirm animation, color, brightness, and scale changes are reflected on the ring.

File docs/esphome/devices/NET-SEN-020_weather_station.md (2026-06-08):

# NET-SEN-020 Weather Station

## Overview

`NET-SEN-020` is a Home Assistant-oriented ESPHome weather station built around:

- BME280 for temperature, humidity, and pressure
- VEML7700 for ambient light
- one digital rain input

This config is a direct ESPHome/Home Assistant device. It is not part of the custom firmware architecture.

## Exposed Entities

Typical Home Assistant entities from the current config:

- `sensor.net_sen_weather_station_temperature`
- `sensor.net_sen_weather_station_humidity`
- `sensor.net_sen_weather_station_pressure`
- `sensor.net_sen_weather_station_illuminance`
- `binary_sensor.net_sen_weather_station_rain`
- `number.net_sen_weather_station_sensor_interval`
- `button.net_sen_weather_station_restart`
- `button.net_sen_weather_station_restart_in_safe_mode`
- `binary_sensor.net_sen_weather_station_status`
- `text_sensor.net_sen_weather_station_ip_address`
- `text_sensor.net_sen_weather_station_connected_ssid`
- `text_sensor.net_sen_weather_station_connected_bssid`

Exact entity IDs can vary after adoption.

## Hardware Mapping

| Component | Pin / Bus | Notes |
|---|---|---|
| BME280 | `I2C`, `SDA=GPIO0`, `SCL=GPIO1`, `0x76` | temperature, humidity, pressure |
| VEML7700 | `I2C`, `SDA=GPIO0`, `SCL=GPIO1`, `0x10` | ambient illuminance |
| Rain input | `GPIO3` | inverted, pull-up |
| Setup button | `GPIO2` | diagnostic entity, also a strapping pin |

## Sampling Model

The sensor polling interval is configurable from Home Assistant through `Sensor Interval`.

Current defaults:

- default: `10 s`
- range: `5 s` to `600 s`

That interval is applied to both the BME280 component and the VEML7700 component.

## Calibration Inputs

The YAML currently supports fixed substitution-based offsets for:

- temperature: `temp_offset_c`
- humidity: `hum_offset_pct`

Those are compile-time values in the current config, not runtime entities.

## Connectivity and Recovery

This device uses:

- ESPHome native API
- OTA password
- fallback AP with captive portal
- local ESPHome web server on port `81`

Fallback AP:

- SSID: `net-sen-020-setup`
- password: `net-sen-setup`

## Current ESPHome File

- [net_sen_weather_station.yaml](D:/LocalRepos/esp32-smart-home/esphome/devices/net_sen_weather_station.yaml)

## Validation Note

`GPIO2` is used for the setup button. ESPHome validates the config, but it also warns that `GPIO2` is a strapping pin. That is acceptable only if the hardware behavior is already understood and verified on the real board.

## Verification Checklist

1. Confirm temperature, humidity, pressure, and illuminance values appear in Home Assistant.
2. Confirm the rain entity changes when the rain input is toggled.
3. Change `Sensor Interval` and confirm the update cadence actually changes.
4. Confirm the fallback AP and captive portal work when Wi-Fi credentials are wrong.
5. Confirm the web server is reachable on port `81` on the local network.

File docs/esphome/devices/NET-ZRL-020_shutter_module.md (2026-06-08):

# NET-ZRL-020 Shutter Module

## Overview

`NET-ZRL-020` is a Home Assistant-oriented ESPHome shutter controller with:

- two relay outputs
- three local buttons
- two local status LEDs
- native Home Assistant cover control
- local travel-time calibration and position estimation

This is not the old MQTT contract device anymore. The current config is a native ESPHome cover implementation.

## Exposed Entities

Typical Home Assistant entities from the current config:

- `cover.net_zrl_shutter`
- `number.net_zrl_shutter_default_travel_time`
- `number.net_zrl_shutter_travel_up_time`
- `number.net_zrl_shutter_travel_down_time`
- `select.net_zrl_shutter_relay_up_mapping`
- `button.net_zrl_shutter_start_calibration`
- `button.net_zrl_shutter_clear_calibration`
- `button.net_zrl_shutter_restart`
- `text_sensor.net_zrl_shutter_status`
- `text_sensor.net_zrl_shutter_ip_address`

Exact entity IDs can vary after adoption.

## Hardware Mapping

| Component | Pin | Notes |
|---|---|---|
| Relay up | `GPIO10` | interlocked with relay down |
| Relay down | `GPIO5` | interlocked with relay up |
| Button up | `GPIO20` | local open control |
| Button down | `GPIO4` | local close control, long hold restarts the device |
| Button stop | `GPIO3` | stop action, long hold starts calibration |
| LED up | `GPIO7` | movement / calibration indicator |
| LED down | `GPIO6` | movement / calibration indicator |

## Cover Behavior

The device exposes a template cover and manages relay movement locally.

Supported local behaviors:

- open
- close
- stop
- target position after calibration

Intermediate positions are only meaningful once travel times are known. Before calibration, full open and full close are still allowed, but partial positioning is intentionally blocked.

## Calibration Model

The calibration flow is fully local:

1. Start calibration.
2. Move to the top end.
3. Wait for the down phase to begin.
4. Measure the full down run.
5. Wait for the up phase to begin.
6. Measure the full up run.
7. Store both travel times.

Current persistence:

- travel up time is stored
- travel down time is stored
- calibration state is restored across reboot

If calibration is cleared, the device forgets the travel times and partial position accuracy is gone.

## Local Button Logic

The button behavior is more opinionated than a generic cover module:

- `UP`: opens the cover, or advances the calibration flow when waiting for the up phase
- `DOWN`: closes the cover on short press, restarts the device on a 5-second hold, or advances calibration when waiting for the down phase
- `STOP`: stops motion immediately; holding for 5 seconds while idle starts calibration

That behavior is efficient once learned, but it is not self-explanatory. Anyone using this hardware needs to know it up front.

## Relay Mapping

`Relay Up Mapping` lets you swap which relay direction counts as "up."

Options:

- `relay_a`
- `relay_b`

That exists because real shutter wiring is messy and pretending otherwise is naive.

## Status Text

The current status text can report:

- `open`
- `closed`
- `opening`
- `closing`
- `stopped`
- one of several calibration states

## Connectivity and Recovery

This device uses:

- ESPHome native API
- OTA password
- fallback AP with captive portal
- local web server

Fallback AP:

- SSID: `net-zrl-020-setup`
- password: `net-zrl-setup`

## Current ESPHome File

- [net_zrl_shutter_module.yaml](D:/LocalRepos/esp32-smart-home/esphome/devices/net_zrl_shutter_module.yaml)

## Verification Checklist

1. Confirm open, close, and stop work from Home Assistant.
2. Confirm the relays never energize both directions at once.
3. Confirm long-hold and short-press button actions match the documented behavior.
4. Run a full calibration and confirm travel times are stored.
5. Confirm intermediate positioning works only after calibration.
6. Power-cycle the device and confirm the stored travel times persist.

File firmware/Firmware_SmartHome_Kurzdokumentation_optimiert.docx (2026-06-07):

Firmware Smart-Home-Grundsystem

Kurzdokumentation für Aufbau, Geräteklassen und Kommunikationsweg

Worum es geht: Die Firmware bildet die gemeinsame Basis für mehrere ESP32-C3-Smart-Home-Module. Sensoren und Aktoren senden ihre Daten per ESP-NOW an einen Master. Der Master übernimmt Registrierung, Statusführung und die Weitergabe an MQTT beziehungsweise Node-RED.

# 1. Technischer Rahmen

Punkt | Festlegung im Projekt
Zielhardware | ESP32-C3 SuperMini Plus Boards
Framework | PlatformIO mit Arduino-Framework
Funkstrecke | ESP-NOW für die direkte Kommunikation zwischen Gerät und Master
Server-Anbindung | MQTT über einen Mosquitto-Broker; Visualisierung und Bedienung über Node-RED
Lokale Speicherung | NVS für Gerätetabelle und persistente Informationen im Master

# 2. Projektaufbau

Die Firmware ist nach gemeinsamen Bausteinen und konkreten Geräte-Instanzen getrennt. Dadurch bleiben Pin-Standards, Protokoll, Provisioning und Speicherlogik wiederverwendbar.

Pfad | Inhalt
include/ | Gemeinsame Header, zum Beispiel Secrets, Debug-Konfiguration, Pin-Standard und Sensor-Hilfsfunktionen.
lib/ | Projektinterne Bibliotheken für ESP-NOW-Protokoll, Geräte-Provisioning und NVS-Speicherung.
src/basetypes/ | Basis-Firmwaretypen für Master, Batteriesensoren, netzbetriebene Module und Rollladensteuerung.
src/devices/ | Konkrete Geräte wie Fensterkontakt, Regensensor, Hall-Modul, LED-Ring-Modul, Wetterstation und Rollladensteuerung.

# 3. Geräteklassen

Typ | Versorgung | Aufgabe | Beispiele
Master | ESP32-C3 | Bridge zwischen ESP-NOW und MQTT; Registrierung und Statusführung. | Master-Controller
bat_sen | CR2032 / 2x AA | Deep-Sleep-Sensoren: aufwachen, messen, senden, wieder schlafen. | Fensterkontakt, Regensensor
net_erl | 230 V Netzteil | Relais-/Sensormodule mit Licht, Umweltmessung, PIR/Radar und optionalem LED-Ring. | Hall-Light, Kitchen LED-Ring
net_sen | 230 V Netzteil | Außensensorik für Wetter, Licht und Regen; optional Luftqualität. | Wetterstation
net_zrl | 230 V Netzteil | Rollladensteuerung mit Auf/Ab-Relais, Touch-Tastern, Kalibrierung und Verriegelung. | Rollladenmodul

# 4. Kommunikationsweg

Schritt | Weg | Inhalt
1 | Gerät → Master | ESP-NOW-Pakete: HELLO, STATE, ACK und EVENT.
2 | Master → Server | MQTT-Topics für state, ack, event und availability.
3 | Server → Master | MQTT-Commands auf smarthome/{device_id}/command.
4 | Dashboard | Node-RED zeigt Zustände an und stellt Aktorbedienung bereit.

# 5. Build und wichtige Voraussetzungen

- Secrets.h: muss lokal vorhanden sein und enthält WLAN-SSID, MQTT-Broker-IP und ESP-NOW-PMK. Die Datei gehört nicht ins Repository.
- Device-ID: jedes Modul erhält eine feste Kennung, zum Beispiel NET-ERL-001.
- Capabilities: eine Bitmask beschreibt, welche Sensoren und Aktoren ein Gerät tatsächlich besitzt.
- Build-Umgebungen: PlatformIO baut einzelne Geräte über eigene Environments; ein Gesamtbuild ist ebenfalls möglich.

Typische PlatformIO-Befehle

pio run -e net_erl_hall_module --target upload

pio run

Quelle: Projekt-README.md

Kurzdokumentation · Firmware-Grundsystem Seite

Smart-Home-Firmware

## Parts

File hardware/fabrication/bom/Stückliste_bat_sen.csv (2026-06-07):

Reference | Qty | Value | DNP | Exclude from BOM | Exclude from Board | Footprint | Datasheet
B1 | 1 | ~ |  |  | Von Platine ausgeschlossen
C1 | 1 | 100uF |  |  |  | Capacitor_SMD:C_0603_1608Metric_Pad1.08x0.95mm_HandSolder | ~
D1 | 1 | LED |  |  | Von Platine ausgeschlossen |  | ~
J1 | 1 | Co_x6_GND |  |  |  | Connector_PinHeader_2.54mm:PinHeader_1x06_P2.54mm_Vertical | ~
J2 | 1 | Co_x6_3V0 |  |  |  | Connector_PinHeader_2.54mm:PinHeader_1x06_P2.54mm_Vertical | ~
J3 | 1 | Co_GPIOx1 |  |  |  | Connector_PinHeader_2.54mm:PinHeader_1x05_P2.54mm_Vertical | ~
J4 | 1 | Co_GPIOx2 |  |  |  | Connector_PinHeader_2.54mm:PinHeader_1x05_P2.54mm_Vertical | ~
J5 | 1 | Co_x2_battery |  |  |  | Connector_JST:JST_PH_B2B-PH-K_1x02_P2.00mm_Vertical | ~
J6,J8 | 2 | Co_x1_5V0 |  |  |  | Connector_PinHeader_2.54mm:PinHeader_1x01_P2.54mm_Vertical | ~
J7 | 1 | Co_GPIOx3 |  |  |  | Connector_PinHeader_2.54mm:PinHeader_1x03_P2.54mm_Vertical | ~
JP1,JP2 | 2 | Bridge_I2C |  |  |  | Jumper:SolderJumper-2_P1.3mm_Open_Pad1.0x1.5mm | ~
R2,R5 | 2 | 100K |  |  |  | Resistor_SMD:R_0603_1608Metric_Pad0.98x0.95mm_HandSolder | ~
R3,R4 | 2 | 4K7 |  |  |  | Resistor_SMD:R_0805_2012Metric_Pad1.20x1.40mm_HandSolder | ~
RV? | 1 | 1000R |  |  | Von Platine ausgeschlossen |  | ~
SW1 | 1 | SW_Reed |  |  | Von Platine ausgeschlossen |  | ~
SW2 | 1 | SW_Push |  |  | Von Platine ausgeschlossen |  | ~
U1 | 1 | ESP32-C3_SUPERMINI_TH |  |  |  | ESP32-C3_SUPERMINI_TH:MODULE_ESP32-C3_SUPERMINI_TH

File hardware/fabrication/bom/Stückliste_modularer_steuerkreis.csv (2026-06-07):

Reference | Qty | Value | DNP | Exclude from BOM | Exclude from Board | Footprint | Datasheet
J? | 1 | Conn_Vx1 |  |  |  | Connector_PinHeader_2.54mm:PinHeader_1x06_P2.54mm_Vertical | ~
J? | 1 | Wire_5 |  |  |  | Connector_Wire:SolderWire-0.25sqmm_1x05_P4.2mm_D0.65mm_OD1.7mm | ~
J? | 1 | Co_GPIOx1 |  |  |  | Connector_PinHeader_2.54mm:PinHeader_1x05_P2.54mm_Vertical | ~
J? | 1 | Co_GPIOx3 |  |  |  | Connector_PinHeader_2.54mm:PinHeader_1x03_P2.54mm_Vertical | ~
JP? | 1 | Bridge_I2C_SDA |  |  |  | Jumper:SolderJumper-2_P1.3mm_Open_Pad1.0x1.5mm | ~
JP? | 1 | Bridge_I2C_SCL |  |  |  | Jumper:SolderJumper-2_P1.3mm_Open_Pad1.0x1.5mm | ~
R?,R? | 2 | 10K |  |  |  | Resistor_SMD:R_0805_2012Metric_Pad1.20x1.40mm_HandSolder | ~
TP1_GND?,TP2_5V?,TP3_3V?,TP4_TRIG?,TP5_TRIG? | 5 | TestPoint |  |  |  | TestPoint:TestPoint_Pad_D1.0mm | ~
U? | 1 | ESP32-C3_SUPERMINI_TH |  |  |  | ESP32-C3_SUPERMINI_TH:MODULE_ESP32-C3_SUPERMINI_TH

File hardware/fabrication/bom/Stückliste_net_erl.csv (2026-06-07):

Reference | Qty | Value | DNP | Exclude from BOM | Exclude from Board | Footprint | Datasheet
D1 | 1 | LED |  |  | Von Platine ausgeschlossen |  | ~
J? | 1 | Conn_Vx1 |  |  |  | Connector_PinHeader_2.54mm:PinHeader_1x06_P2.54mm_Vertical | ~
J? | 1 | Co_GPIOx1 |  |  |  | Connector_PinHeader_2.54mm:PinHeader_1x05_P2.54mm_Vertical | ~
J? | 1 | Co_GPIOx3 |  |  |  | Connector_PinHeader_2.54mm:PinHeader_1x03_P2.54mm_Vertical | ~
J? | 1 | Wire_5 |  |  |  | Connector_Wire:SolderWire-0.25sqmm_1x05_P4.2mm_D0.65mm_OD1.7mm | ~
JP1 | 1 | Bridge_I2C_SDA |  |  |  | Jumper:SolderJumper-2_P1.3mm_Open_Pad1.0x1.5mm | ~
JP2 | 1 | Bridge_I2C_SCL |  |  |  | Jumper:SolderJumper-2_P1.3mm_Open_Pad1.0x1.5mm | ~
R1,R2 | 2 | 10K |  |  |  | Resistor_SMD:R_0805_2012Metric_Pad1.20x1.40mm_HandSolder | ~
RV? | 1 | 1000R |  |  | Von Platine ausgeschlossen |  | ~
S1,S2,U1 | 3 | ~ |  |  | Von Platine ausgeschlossen
SW1 | 1 | SW_Push |  |  | Von Platine ausgeschlossen |  | ~
TP1_GND?,TP2_5V?,TP3_3V?,TP4_TRIG?,TP5_TRIG? | 5 | TestPoint |  |  |  | TestPoint:TestPoint_Pad_D1.0mm | ~
U? | 1 | ESP32-C3_SUPERMINI_TH |  |  |  | ESP32-C3_SUPERMINI_TH:MODULE_ESP32-C3_SUPERMINI_TH

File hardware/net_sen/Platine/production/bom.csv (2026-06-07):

Designator | Footprint | Quantity | Value | LCSC Part #
C1 | CP_Elec_6.3x5.8 | 1 | 100uF
C2 | 0805 | 1 | 100nF
ESP32-C3_SUPERMINI_TH | MODULE_ESP32-C3_SUPERMINI_TH | 1 | ESP32-C3_SUPERMINI_TH
F1 | Fuseholder_Clip-5x20mm_Bel_FC-203-22_Lateral_P17.80x5.00mm_D1.17mm_Horizontal | 1 | Fuse
J1 | PinHeader_1x06_P2.54mm_Vertical | 1 | Co_x6_GND
J2 | PinHeader_1x06_P2.54mm_Vertical | 1 | Co_x6_3V3
J3 | PinHeader_1x05_P2.54mm_Vertical | 1 | Co_GPIOx1
J4 | PinHeader_1x05_P2.54mm_Vertical | 1 | Co_GPIOx2
J5 | TerminalBlock_Phoenix_MKDS-1,5-3_1x03_P5.00mm_Horizontal | 1 | Input_x3
J6 | PinHeader_1x01_P2.54mm_Vertical | 1 | Co_x1_5V0
J7 | PinHeader_1x03_P2.54mm_Vertical | 1 | Co_GPIOx3
JP1, JP2 | SolderJumper-2_P1.3mm_Open_Pad1.0x1.5mm | 2 | Bridge_I2C
PS1 | Converter_ACDC_Hi-Link_HLK-PMxx | 1 | HLK-PM03
R3, R4 | 0805 | 2 | 4K7

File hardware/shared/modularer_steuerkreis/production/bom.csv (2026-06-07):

Designator | Footprint | Quantity | Value | LCSC Part #
J1 | SolderWire-0.25sqmm_1x05_P4.2mm_D0.65mm_OD1.7mm | 1 | Wire_5
J3 | PinHeader_1x05_P2.54mm_Vertical | 1 | Co_GPIOx1
J6 | PinHeader_1x06_P2.54mm_Vertical | 1 | Conn_Vx1
J7 | PinHeader_1x03_P2.54mm_Vertical | 1 | Co_GPIOx3
JP1, JP2 | SolderJumper-2_P1.3mm_Open_Pad1.0x1.5mm | 2 | Bridge_I2C
MH_2, MH | Mounting_Hole_M3 | 2 | Mounting_Hole_M3
R3, R4 | 0805 | 2 | 4K7
TP1, TP2, TP3, TP4, TP5 | TestPoint_Pad_D1.0mm | 5 | TestPoint
U3 | MODULE_ESP32-C3_SUPERMINI_TH | 1 | ESP32-C3_SUPERMINI_TH

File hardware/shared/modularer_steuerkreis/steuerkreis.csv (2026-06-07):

ID | Bezeichner | Footprint | Stückzahl | Bezeichnung | Anbieter und Referenz
1 | U3 | MODULE_ESP32-C3_SUPERMINI_TH | 1 | ESP32-C3_SUPERMINI_TH
2 | TP1,TP4,TP2,TP3,TP5 | TestPoint_Pad_D1.0mm | 5 | TestPoint
3 | J3 | PinHeader_1x05_P2.54mm_Vertical | 1 | Co_GPIOx1
4 | J1 | SolderWire-0.25sqmm_1x05_P4.2mm_D0.65mm_OD1.7mm | 1 | Wire_5
5 | R4,R3 | R_0805_2012Metric_Pad1.20x1.40mm_HandSolder | 2 | 4K7
6 | JP2,JP1 | SolderJumper-2_P1.3mm_Open_Pad1.0x1.5mm | 2 | Bridge_I2C
7 | MH,MH | Mounting_Hole_M3 | 2 | Mounting_Hole_M3
8 | J6 | PinHeader_1x06_P2.54mm_Vertical | 1 | Conn_Vx1
9 | J7 | PinHeader_1x03_P2.54mm_Vertical | 1 | Co_GPIOx3

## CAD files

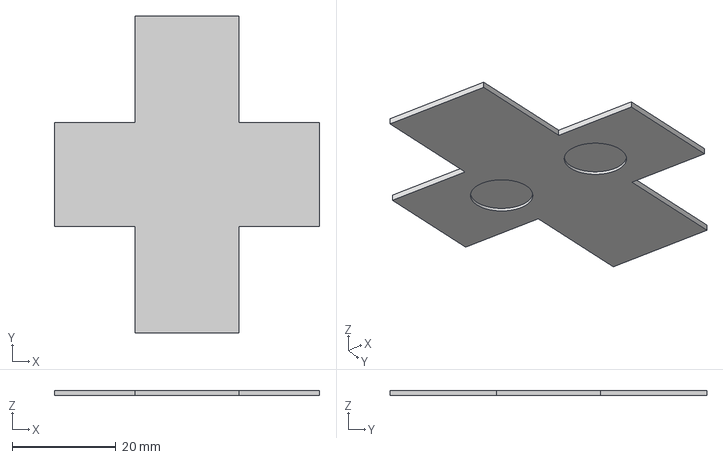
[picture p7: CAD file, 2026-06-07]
hardware/3d_models/bat_sen/V2/Wandhalterung_V2.3mf
51.0 x 61.0 x 1.00 mm

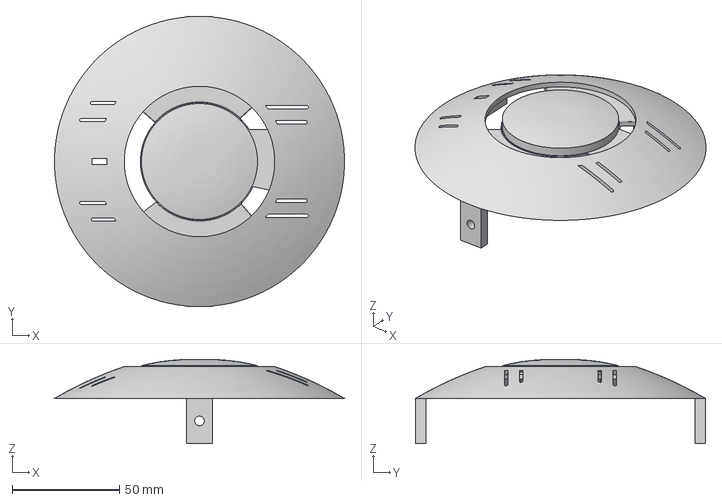
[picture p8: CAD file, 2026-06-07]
hardware/3d_models/net_erl/Deckel_LED_Ring.3mf
134.9 x 135.0 x 39.1 mm

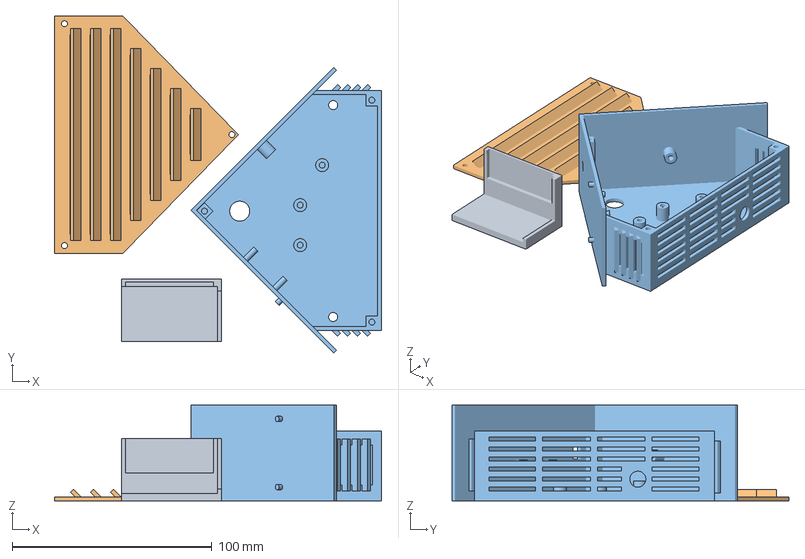
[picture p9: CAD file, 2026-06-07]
hardware/3d_models/net_sen/Arduino+Weather+Center.3mf
163.6 x 168.5 x 48.0 mm
Arduino Weather Center Roof Guard.stl
Arduino Weather Center Front.stl
Arduino Weather Center Main Unit.stl

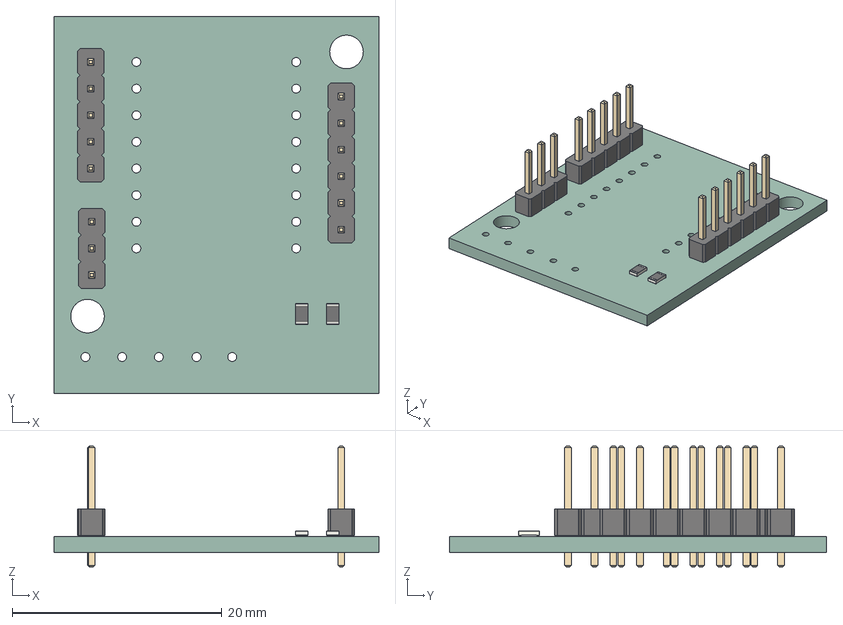
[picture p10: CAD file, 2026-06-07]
hardware/fabrication/kicad/modularer_steuerkreis/Schaltplaene_und_Bilder/steuerkreis.step
31.0 x 36.0 x 11.5 mm
PinHeader_1x05_P2.54mm_Vertical
R_0805_2012Metric x 2
PinHeader_1x06_P2.54mm_Vertical
PinHeader_1x03_P2.54mm_Vertical
mod_Steuerkreis_ESP32_PCB

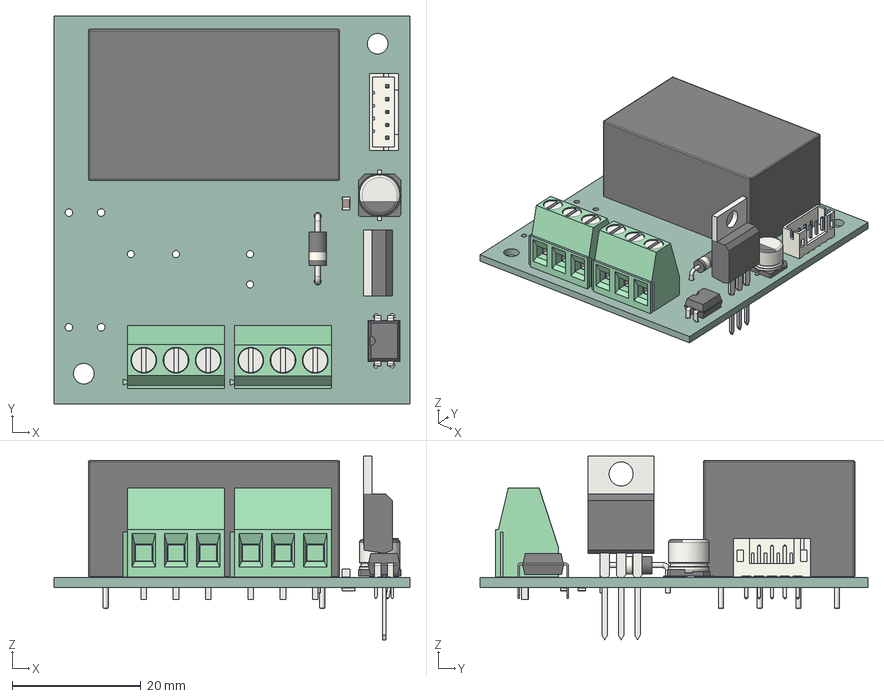
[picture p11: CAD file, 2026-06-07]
hardware/fabrication/kicad/net_erl/Schaltplaene_und_Bilder/leistungskreis.step
55.2 x 60.2 x 28.5 mm
JST_PH_B5B-PH-K_1x05_P2.00mm_Vertical
TO-220-3_Vertical
TerminalBlock_Phoenix_MKDS-1,5-3_1x03_P5.00mm_Horizontal x 2
C_0805_2012Metric
DIP-4_W7.62mm
D_DO-41_SOD81_P10.16mm_Horizontal
CP_Elec_6.3x5.8
Converter_ACDC_Hi-Link_HLK-5Mxx
R_0805_2012Metric x 2
Leistungskreis_1Relai_korrektur_PCB

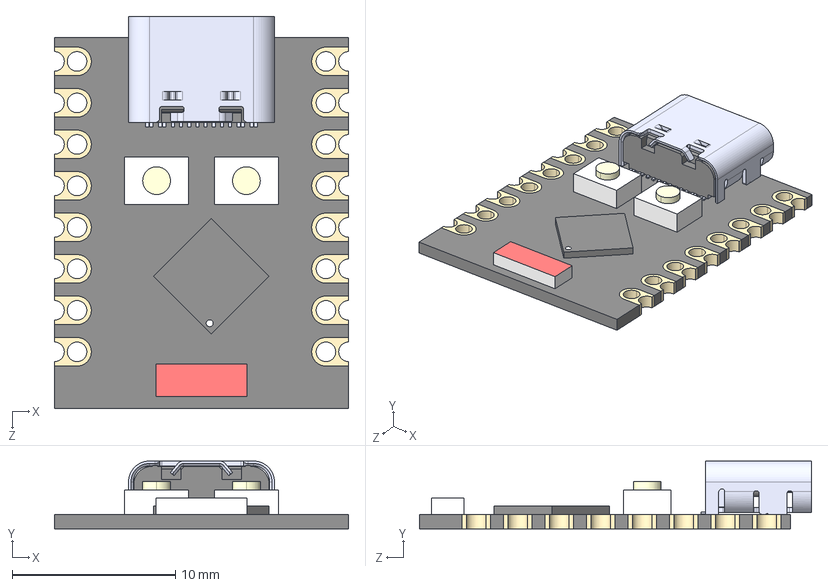
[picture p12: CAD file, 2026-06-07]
hardware/shared/esp32-c3-supermini/ESP32-C3_SUPERMINI_TH.step
18.0 x 4.16 x 24.0 mm
Board c3mini
USB C
components (other)^ESP32-C3 SuperMini

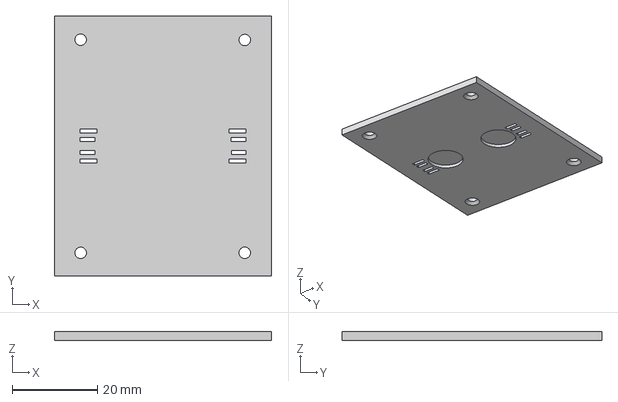
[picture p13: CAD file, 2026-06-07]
hardware/3d_models/bat_sen/V2/Abdeckung_unten_V2.3mf
51.0 x 61.0 x 2.00 mm

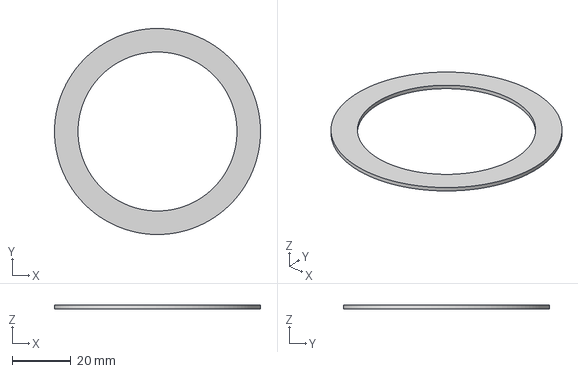
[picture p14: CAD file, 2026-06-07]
hardware/3d_models/net_erl/Diffusor_PTEG.3mf
70.0 x 70.0 x 1.20 mm

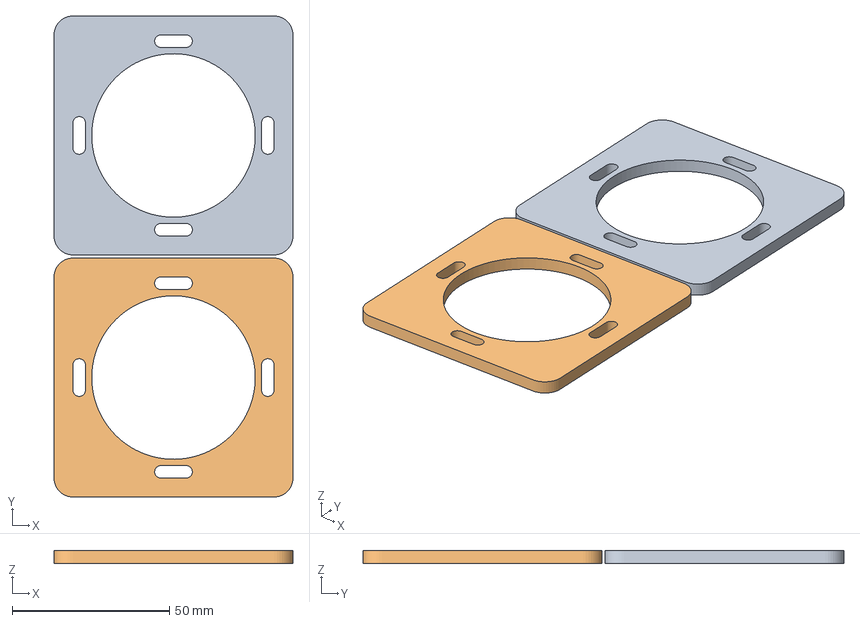
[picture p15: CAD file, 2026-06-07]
hardware/3d_models/net_zrl/Abstandshalter.3mf
76.0 x 153.0 x 4.00 mm
Abstandshalter x 2

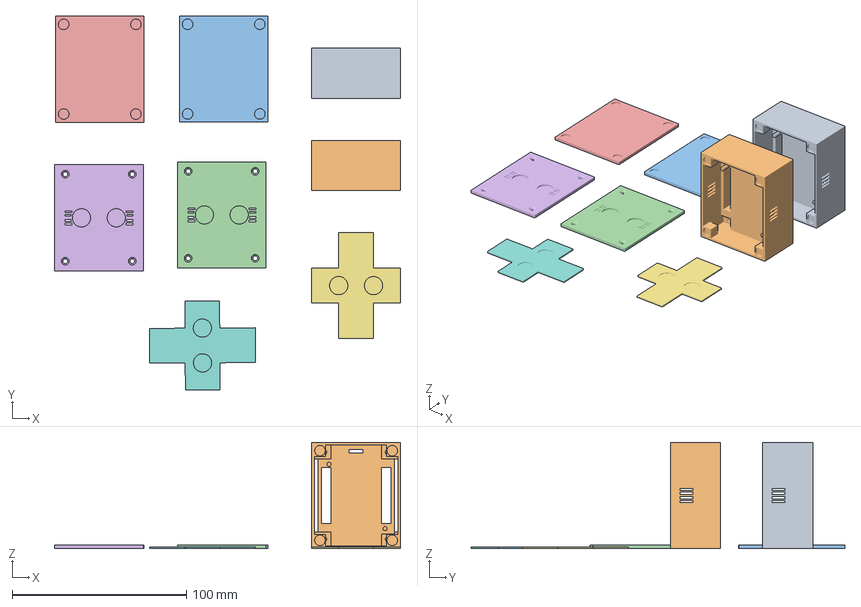
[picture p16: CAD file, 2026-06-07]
hardware/3d_models/bat_sen/V2/Abdeckung_oben_V2.3mf
198.7 x 214.8 x 61.0 mm
Hauptkörper x 2
Abdeckung_oben x 2
Abdeckung_unten x 2
Wandhalterung x 2

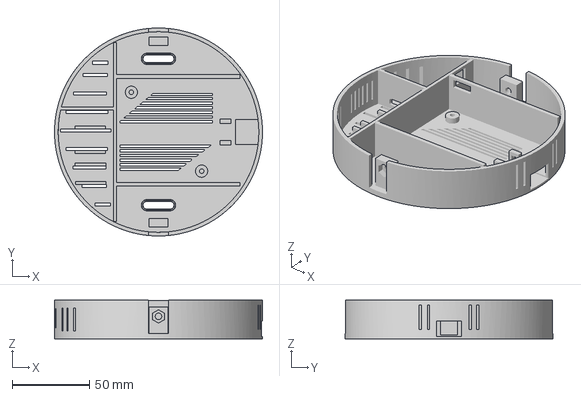
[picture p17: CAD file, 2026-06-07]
hardware/3d_models/net_erl/Basis.3mf
135.0 x 135.0 x 25.0 mm

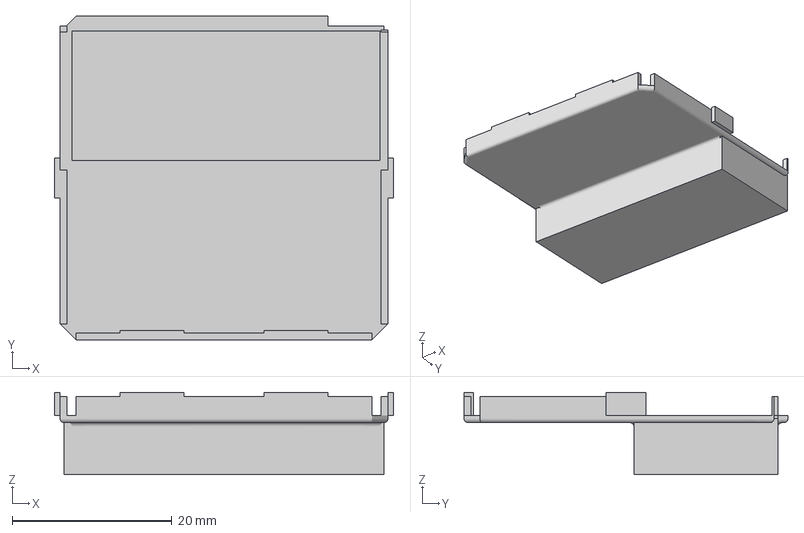
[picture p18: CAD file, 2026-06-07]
hardware/3d_models/net_zrl/PCB_Protection.3mf
42.4 x 40.5 x 10.3 mm

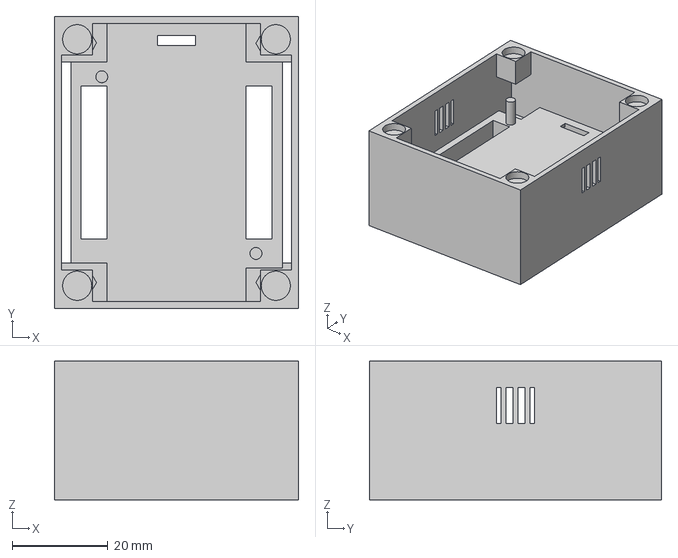
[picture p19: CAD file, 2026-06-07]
hardware/3d_models/bat_sen/V2/Hauptkörper_V2.3mf
51.0 x 61.0 x 29.0 mm

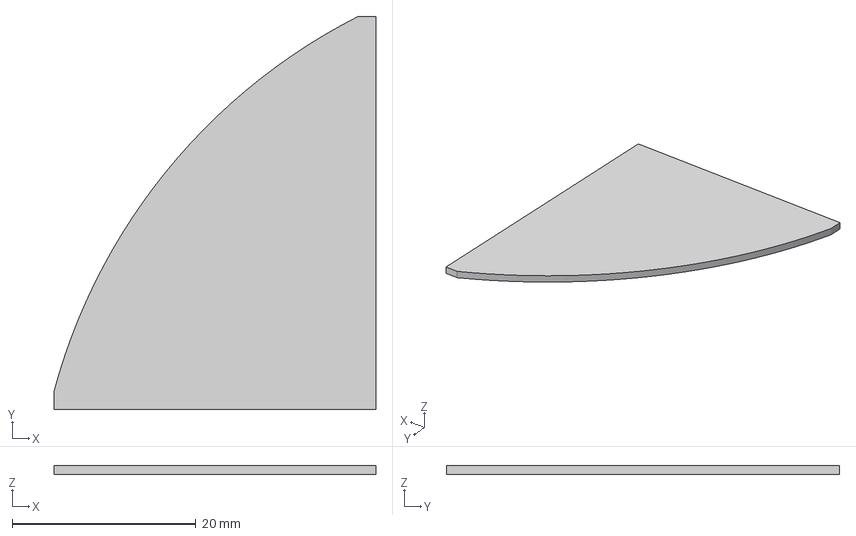
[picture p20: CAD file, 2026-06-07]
hardware/3d_models/net_erl/Abdeckung.3mf
35.0 x 42.8 x 1.00 mm

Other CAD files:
hardware/3d_models/net_zrl/zeichen.3mf
hardware/3d_models/net_erl/Trennwand.3mf
hardware/3d_models/bat_sen/V1/Alle_Teile.3mf
hardware/3d_models/net_erl/Deckel_PIR.3mf
hardware/3d_models/net_zrl/BODY_FRONT_CONTROL_BASE_V2.3mf
hardware/3d_models/net_zrl/PCB_Protection_old.3mf
hardware/3d_models/net_zrl/WALL_ADAPTER_COPY_V2.3mf
hardware/3d_models/net_zrl/buttons.3mf

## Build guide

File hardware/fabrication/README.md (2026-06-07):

# Fabrication

This folder contains production-oriented outputs for the hardware designs.

Do not edit these files as if they were source code. Treat them as release artifacts derived from the board designs.

## Contents

- `gerbers/` - PCB manufacturing data
- `kicad/` - board project files and exports
- `schematics/` - schematic PDFs and handoff files
- `bom/` - bill of materials CSV exports

## Purpose

These files exist so someone can manufacture or review the boards without digging through the entire design history.

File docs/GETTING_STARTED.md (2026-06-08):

# Getting Started

This is the shortest useful path for a first-time user.

## 1. Pick your entry point

- `firmware/` if you want the custom ESP-NOW + MQTT line
- `esphome/` if you want the separate Home Assistant-oriented ESPHome line
- `server/` if you want the local MQTT / Node-RED / SQLite stack
- `hardware/` if you want the PCB and enclosure work

## 2. Start the local server

```powershell
cd server
Copy-Item .env.example .env
docker compose up -d
```

Open the dashboard:

```text
http://localhost:1880/ui
```

## 3. Choose a device family

- `net_erl` for relay and hall-light style devices
- `net_zrl` for shutter / blind control
- `net_sen` for mains-powered sensors
- `bat_sen` for battery-powered sensors

## 4. Decide whether you want custom firmware or ESPHome

Use the custom firmware if you want the original project architecture with ESP-NOW, a master bridge, and the local server contract.

Use ESPHome if you want simpler Home Assistant-native devices and do not want to adopt the custom firmware architecture.

Do not blur the two. They share hardware ideas, not one runtime stack.

## 5. Read only what you need

- [Root README](../README.md)
- [Hardware overview](../hardware/README.md)
- [Firmware overview](../firmware/README.md)
- [Server overview](../server/README.md)
- [ESPHome overview](../esphome/README.md)

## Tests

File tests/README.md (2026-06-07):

# Tests

This folder contains the repository's smoke checks and contract checks.

## What is covered

- server startup checks
- MQTT / SQLite contract validation
- device-flow regression checks
- ESPHome configuration validation helpers

## Where to start

- `tests\server\server_contract_smoke.ps1` for the main server contract check
- `tests\server\phase1_ingest_checkliste.md` for the manual ingest path
- `tests\server\minimalserver_smoke_checkliste_2026-04-24.md` for the minimal server checklist

## Scope

These tests are meant to catch broken setup states early. They are not a full hardware validation suite.

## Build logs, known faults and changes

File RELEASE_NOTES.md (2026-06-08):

# Release Notes

## Public English release preparation

This release converts the project into a cleaner public-facing repository.

### What changed

- root documentation rewritten in English
- hardware, firmware, server, and ESPHome entry points cleaned up
- ESPHome presentation rebuilt around a separate Home Assistant-oriented track instead of a firmware-coupled story
- device-specific readmes translated where they matter for reuse
- legacy German reference material moved into `docs/archive/`
- public repo structure clarified around independently usable modules
- runtime secrets, caches, and generated state excluded from the main tree

### What is included

- custom ESP32-C3 firmware
- ESPHome alternative line for Home Assistant users
- local MQTT, Node-RED, and SQLite server stack
- hardware designs, fabrication exports, and enclosures
- verification scripts and contract checks

### What is deliberately excluded

- private school hand-in documents
- runtime-only Node-RED state
- local secrets
- build caches
- older working backups and draft material

### Suggested first commit message

`chore: prepare public English release of ESP32 smart home project`

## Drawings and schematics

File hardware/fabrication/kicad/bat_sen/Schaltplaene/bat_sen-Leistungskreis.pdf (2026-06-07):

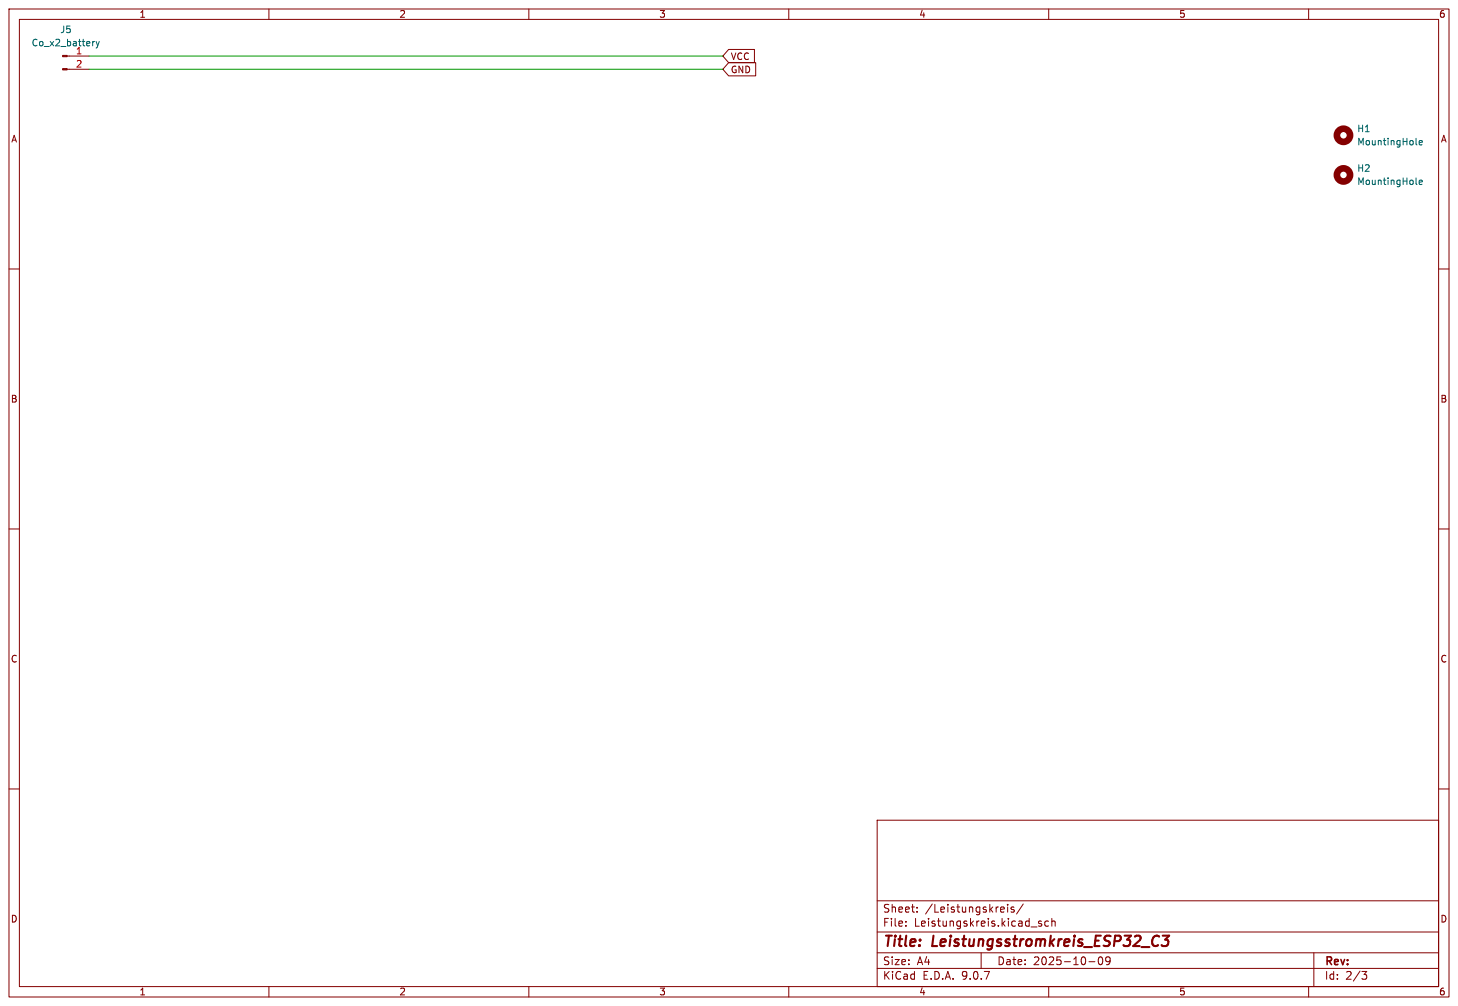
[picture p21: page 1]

File: Leistungskreis.kicad_sch Sheet: /Leistungskreis/
Id: 2/3 Title: Leistungsstromkreis_ESP32_C3

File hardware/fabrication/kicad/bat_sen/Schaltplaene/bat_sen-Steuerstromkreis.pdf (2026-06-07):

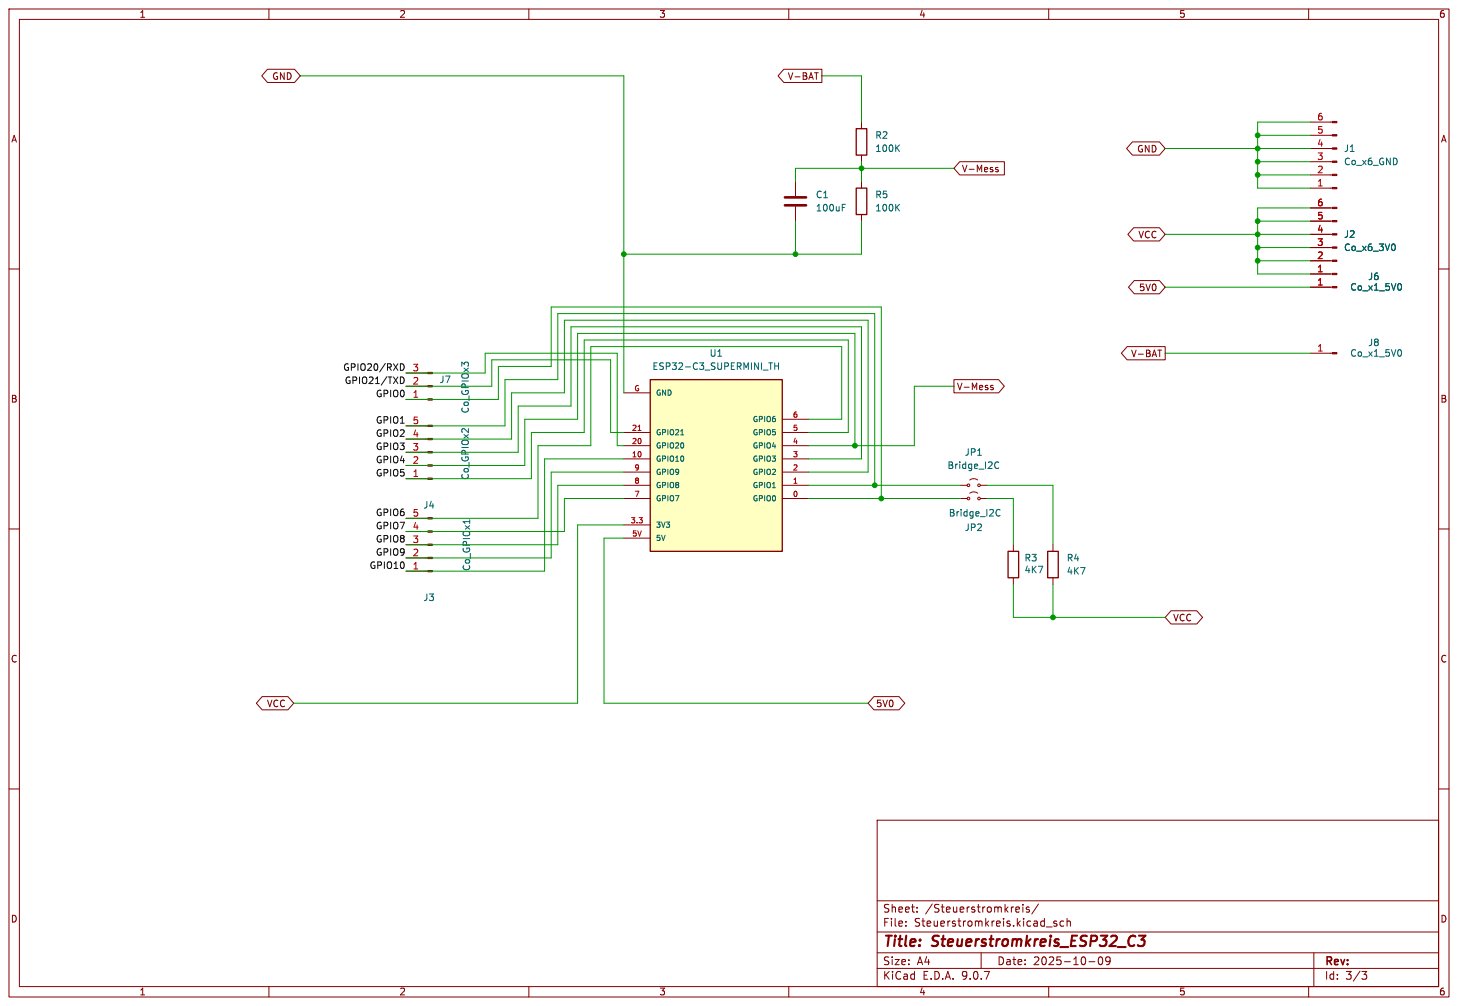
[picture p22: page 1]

File: Steuerstromkreis.kicad_sch Sheet: /Steuerstromkreis/
Id: 3/3 Title: Steuerstromkreis_ESP32_C3

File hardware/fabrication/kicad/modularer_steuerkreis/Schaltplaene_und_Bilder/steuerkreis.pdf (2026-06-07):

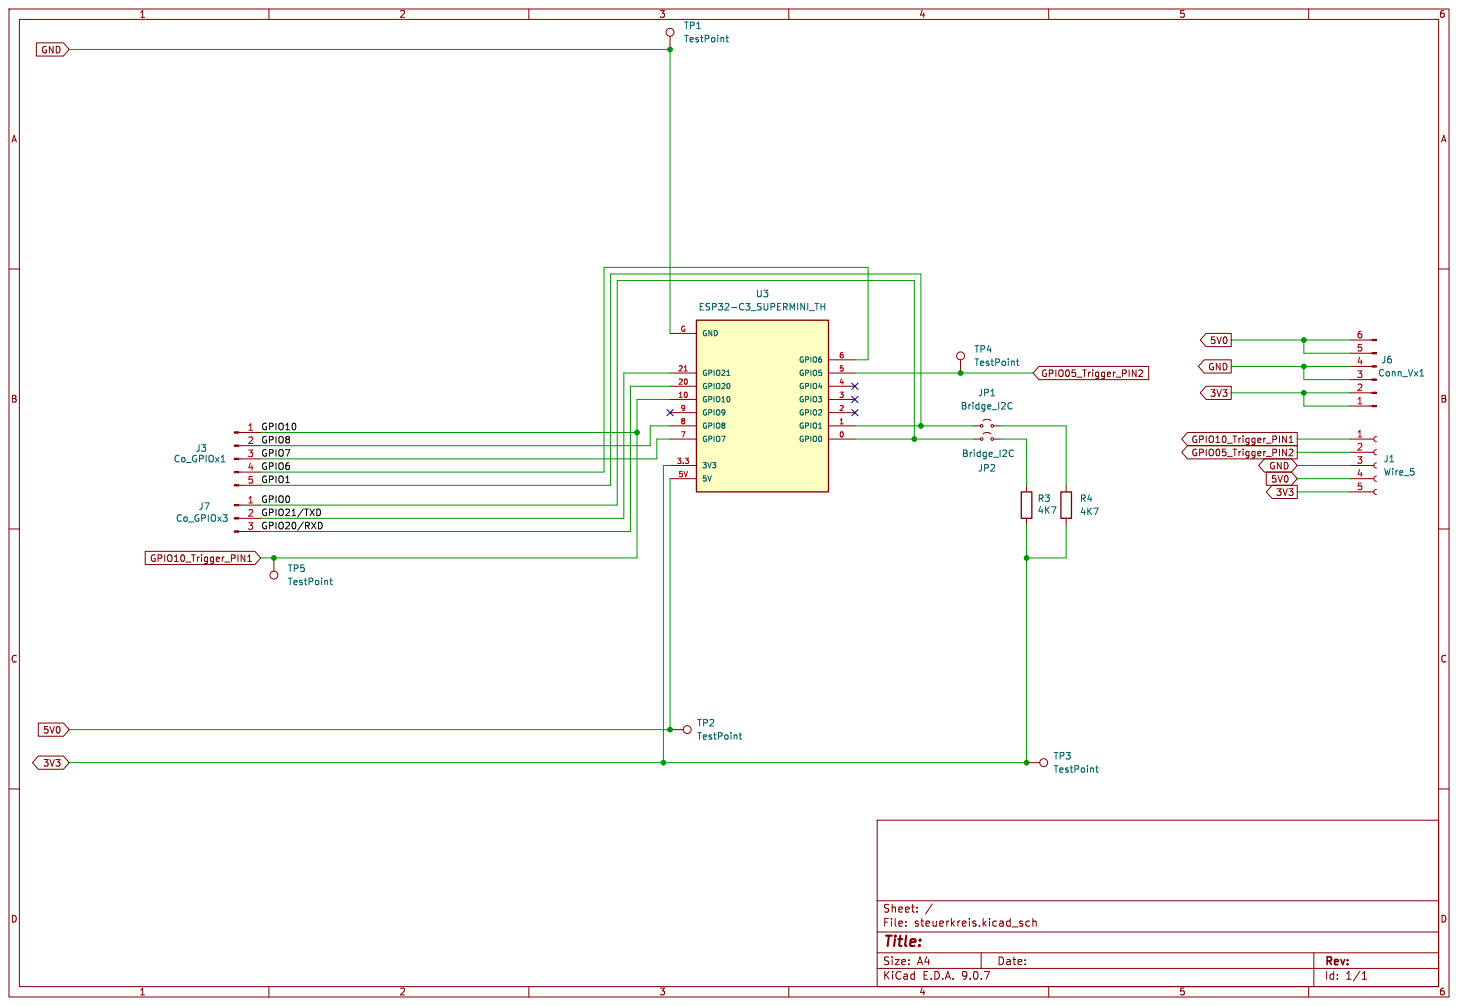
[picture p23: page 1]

Id: 1/1 Title: File: steuerkreis.kicad_sch Sheet: /

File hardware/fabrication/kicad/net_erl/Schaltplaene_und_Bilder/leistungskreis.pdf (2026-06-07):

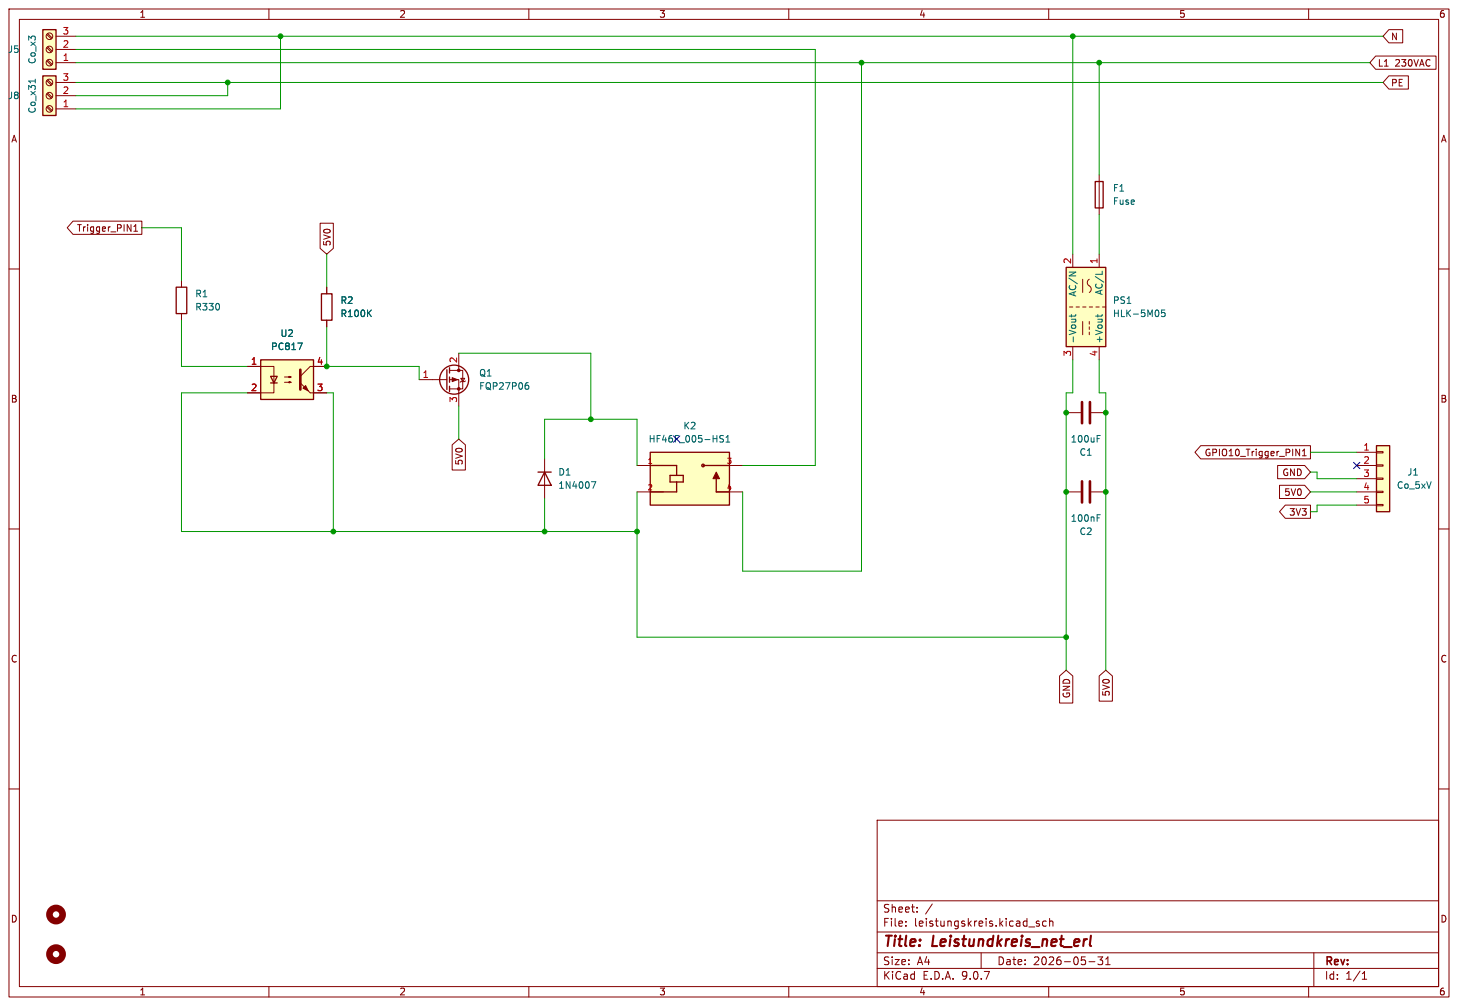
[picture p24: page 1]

Id: 1/1 Title: Leistundkreis_net_erl File: leistungskreis.kicad_sch Sheet: /

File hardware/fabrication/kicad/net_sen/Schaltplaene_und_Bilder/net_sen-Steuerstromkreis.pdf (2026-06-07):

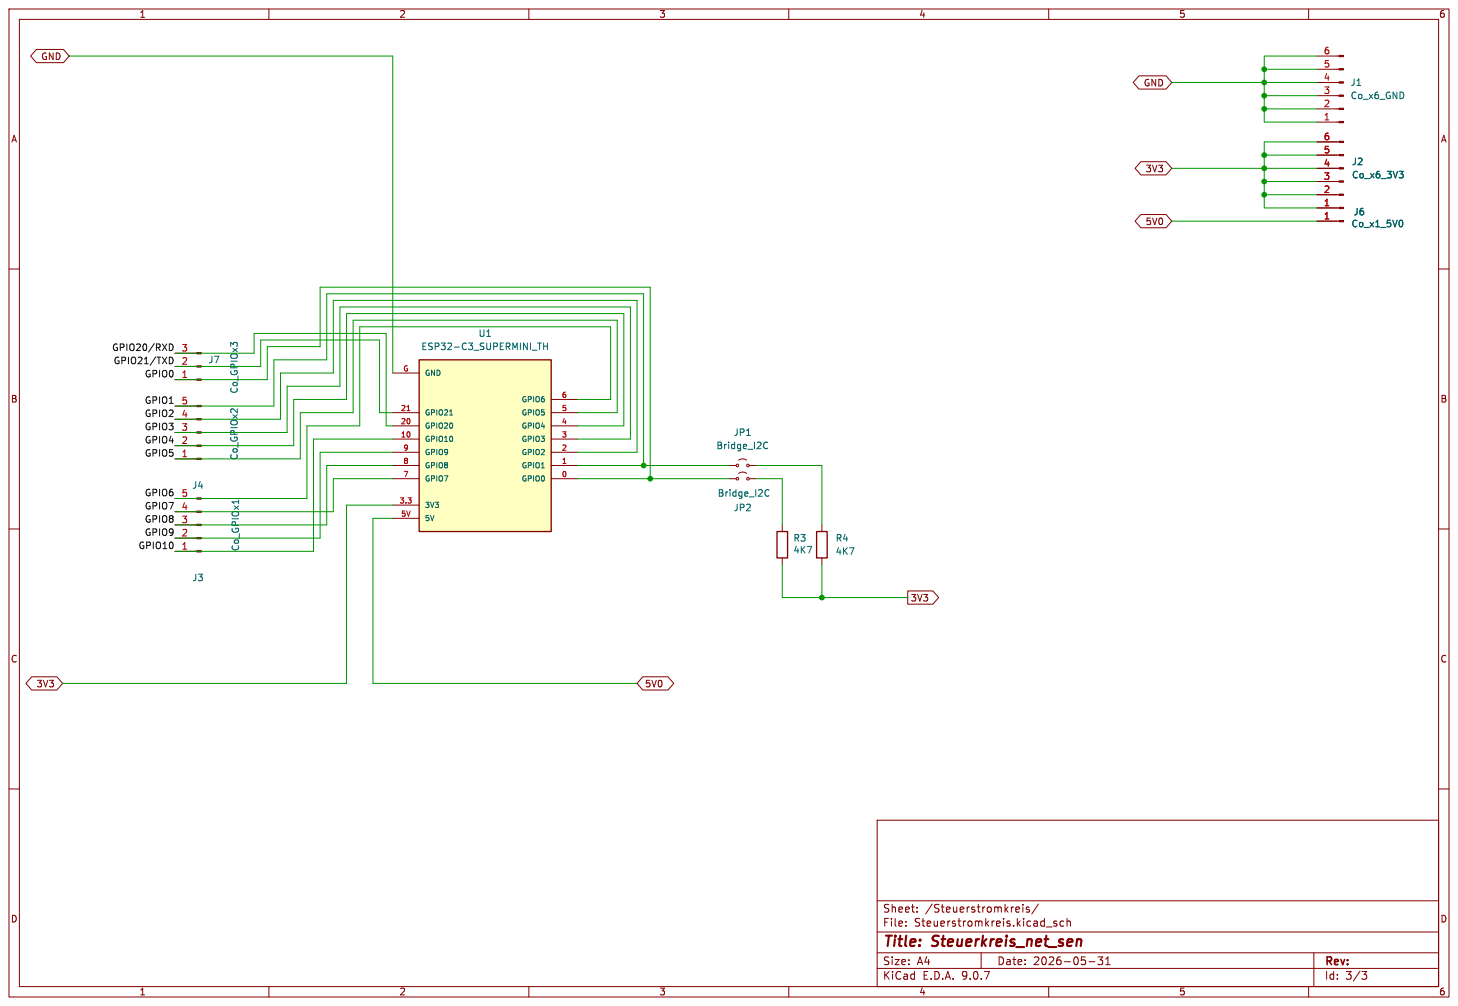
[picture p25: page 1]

File: Steuerstromkreis.kicad_sch Sheet: /Steuerstromkreis/
Id: 3/3 Title: Steuerkreis_net_sen

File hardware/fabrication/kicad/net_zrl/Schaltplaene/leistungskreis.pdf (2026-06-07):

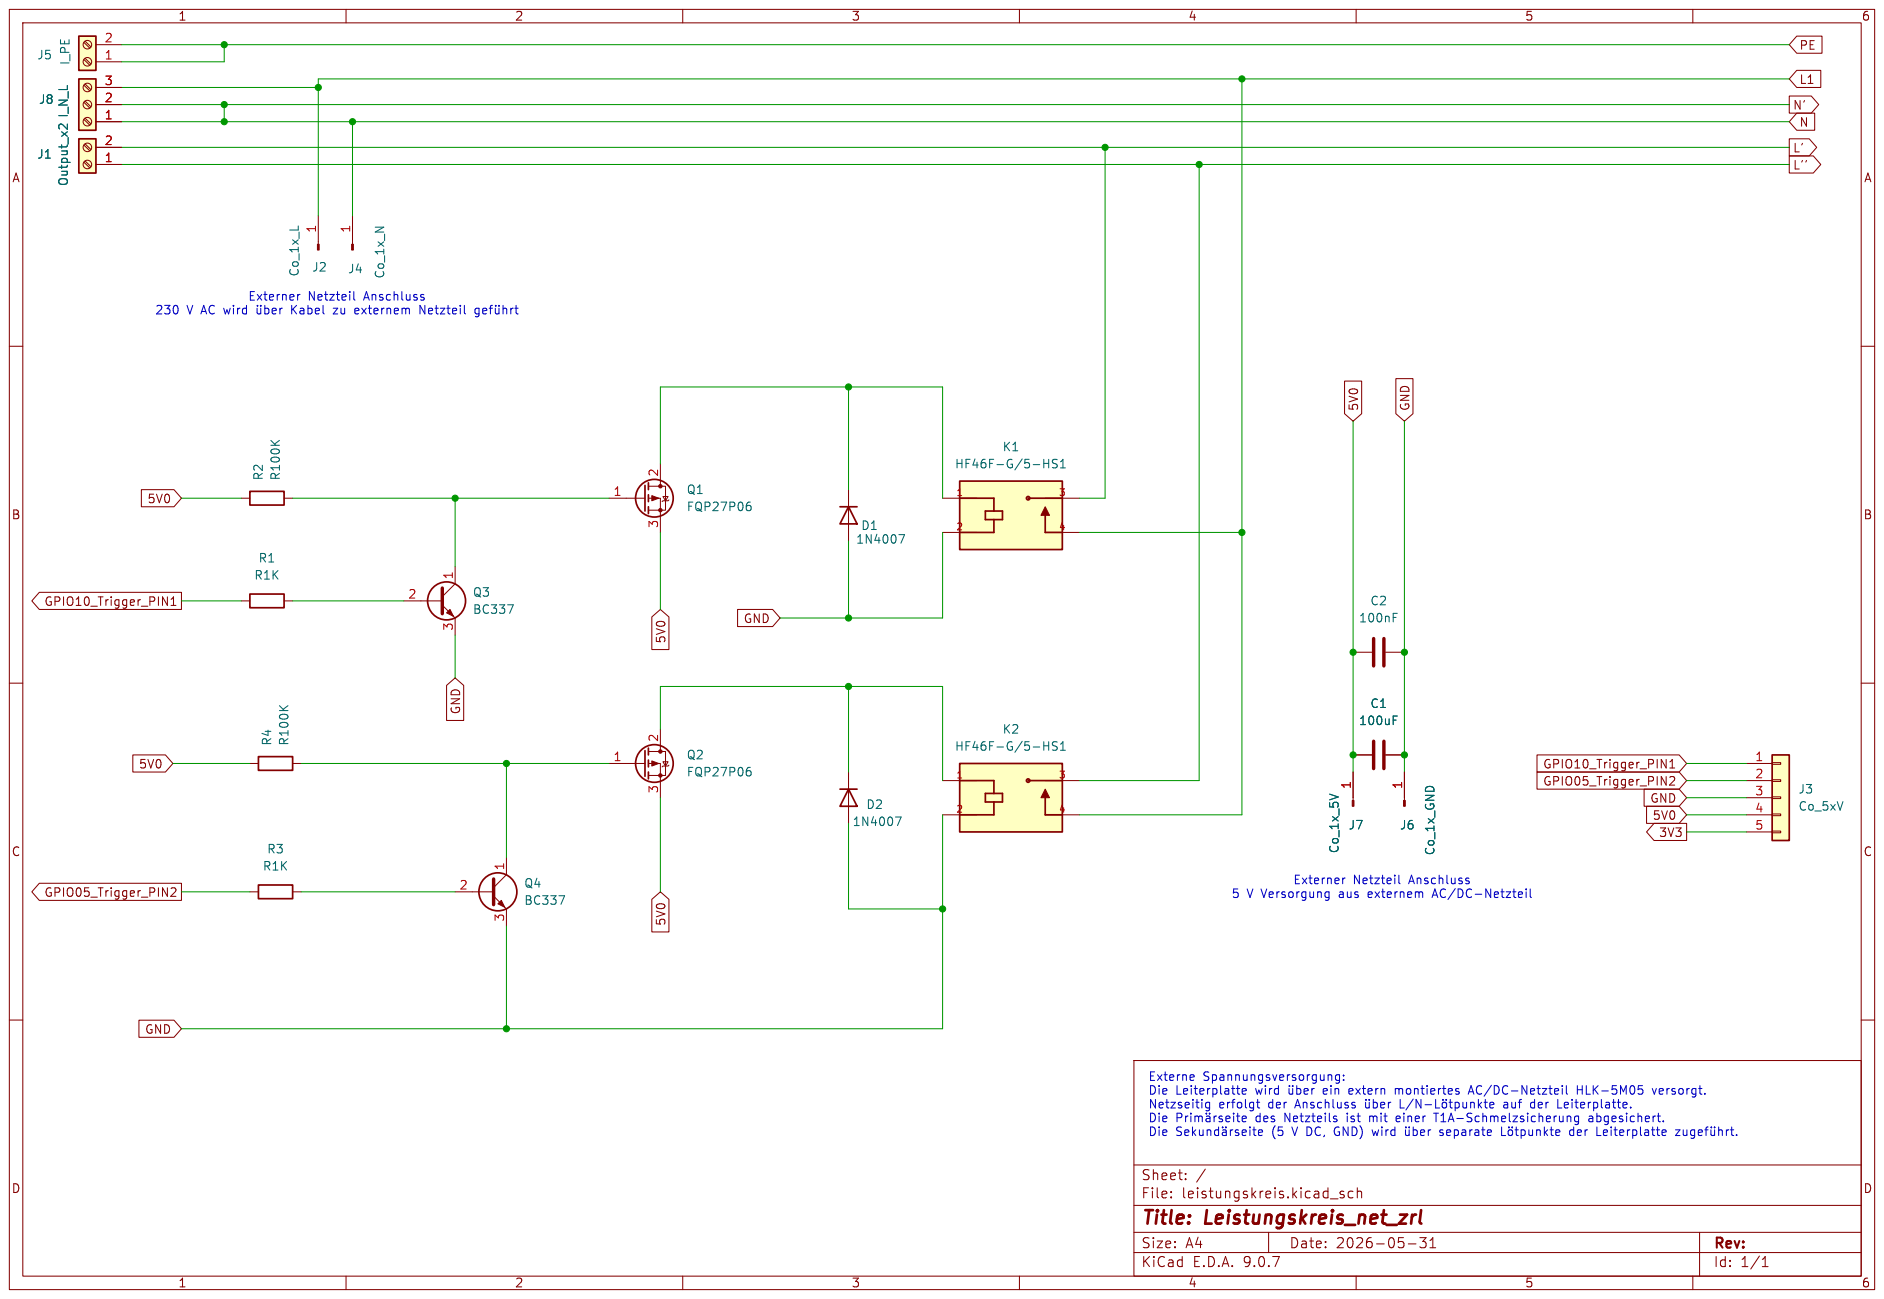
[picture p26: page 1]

Id: 1/1 Title: Leistungskreis_net_zrl File: leistungskreis.kicad_sch Sheet: / 2

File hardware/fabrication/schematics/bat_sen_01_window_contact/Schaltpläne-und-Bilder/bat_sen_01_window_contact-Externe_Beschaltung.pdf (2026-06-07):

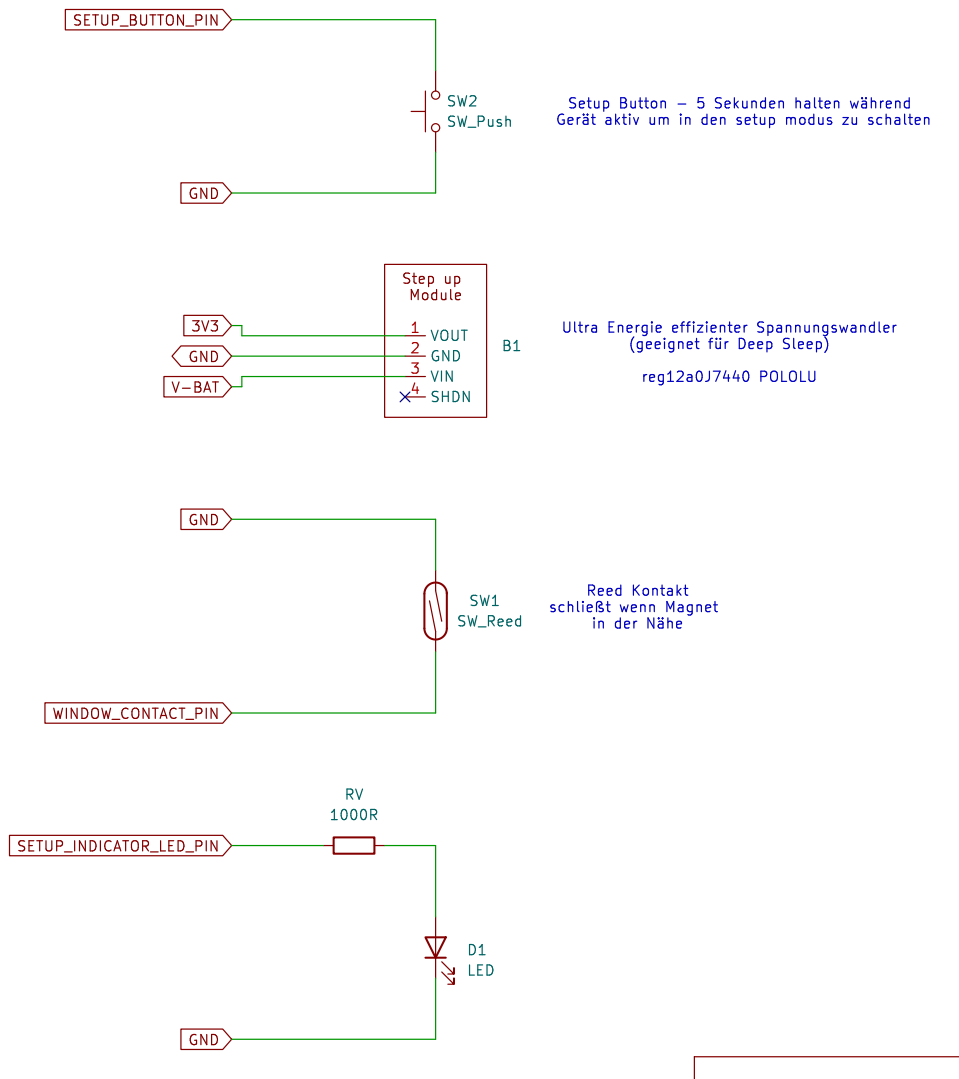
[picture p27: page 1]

Setup Button - 5 Sekunden halten þÿwährend
þÿGerät aktiv um in den setup modus zu schalten

Reed Kontakt þÿschließt wenn Magnet

Id: 3/3 Title: Externe Beschaltung

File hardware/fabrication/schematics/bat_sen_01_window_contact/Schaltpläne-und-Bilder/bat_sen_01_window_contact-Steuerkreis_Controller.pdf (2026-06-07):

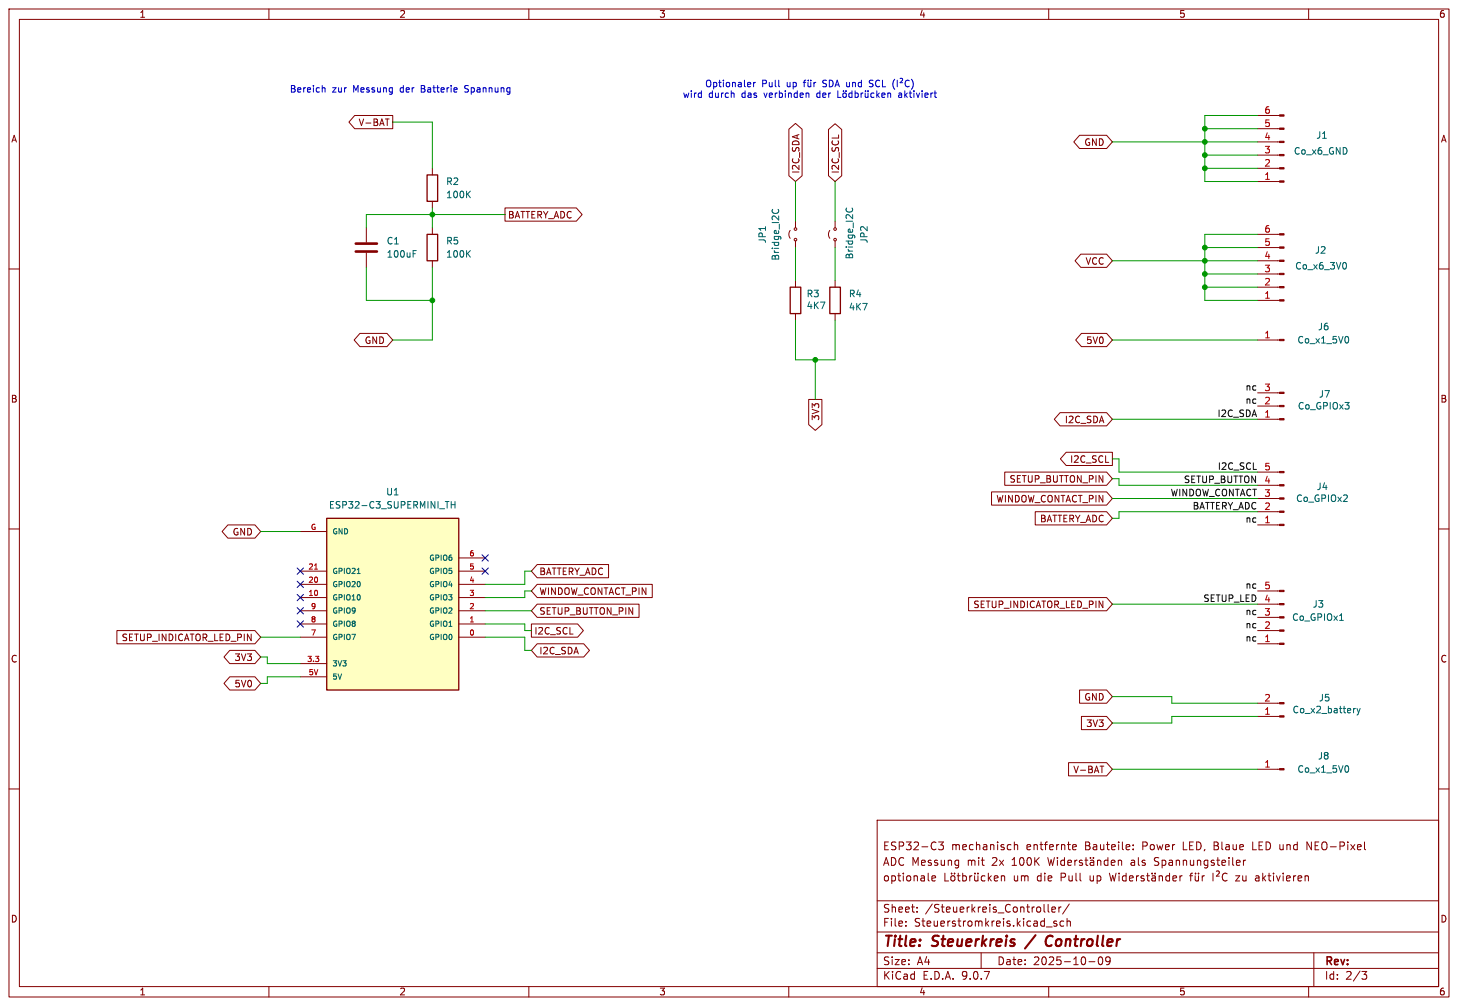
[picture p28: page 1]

Id: 2/3 Title: Steuerkreis / Controller File: Steuerstromkreis.kicad_sch Sheet: /Steuerkreis_Controller/

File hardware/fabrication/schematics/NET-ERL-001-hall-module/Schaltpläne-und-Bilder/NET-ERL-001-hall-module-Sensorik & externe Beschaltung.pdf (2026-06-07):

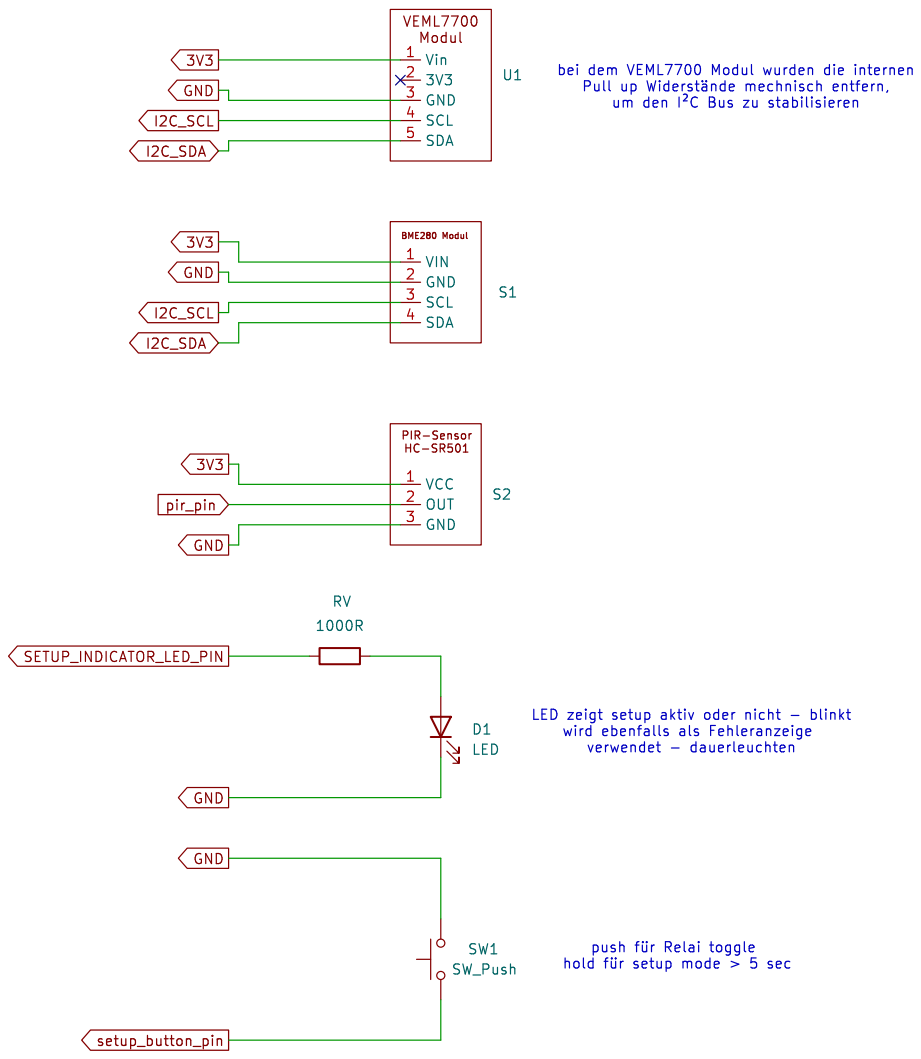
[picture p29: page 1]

push þÿfür Relai toggle

Id: 3/3 Title: Sensorik und externe Beschaltung

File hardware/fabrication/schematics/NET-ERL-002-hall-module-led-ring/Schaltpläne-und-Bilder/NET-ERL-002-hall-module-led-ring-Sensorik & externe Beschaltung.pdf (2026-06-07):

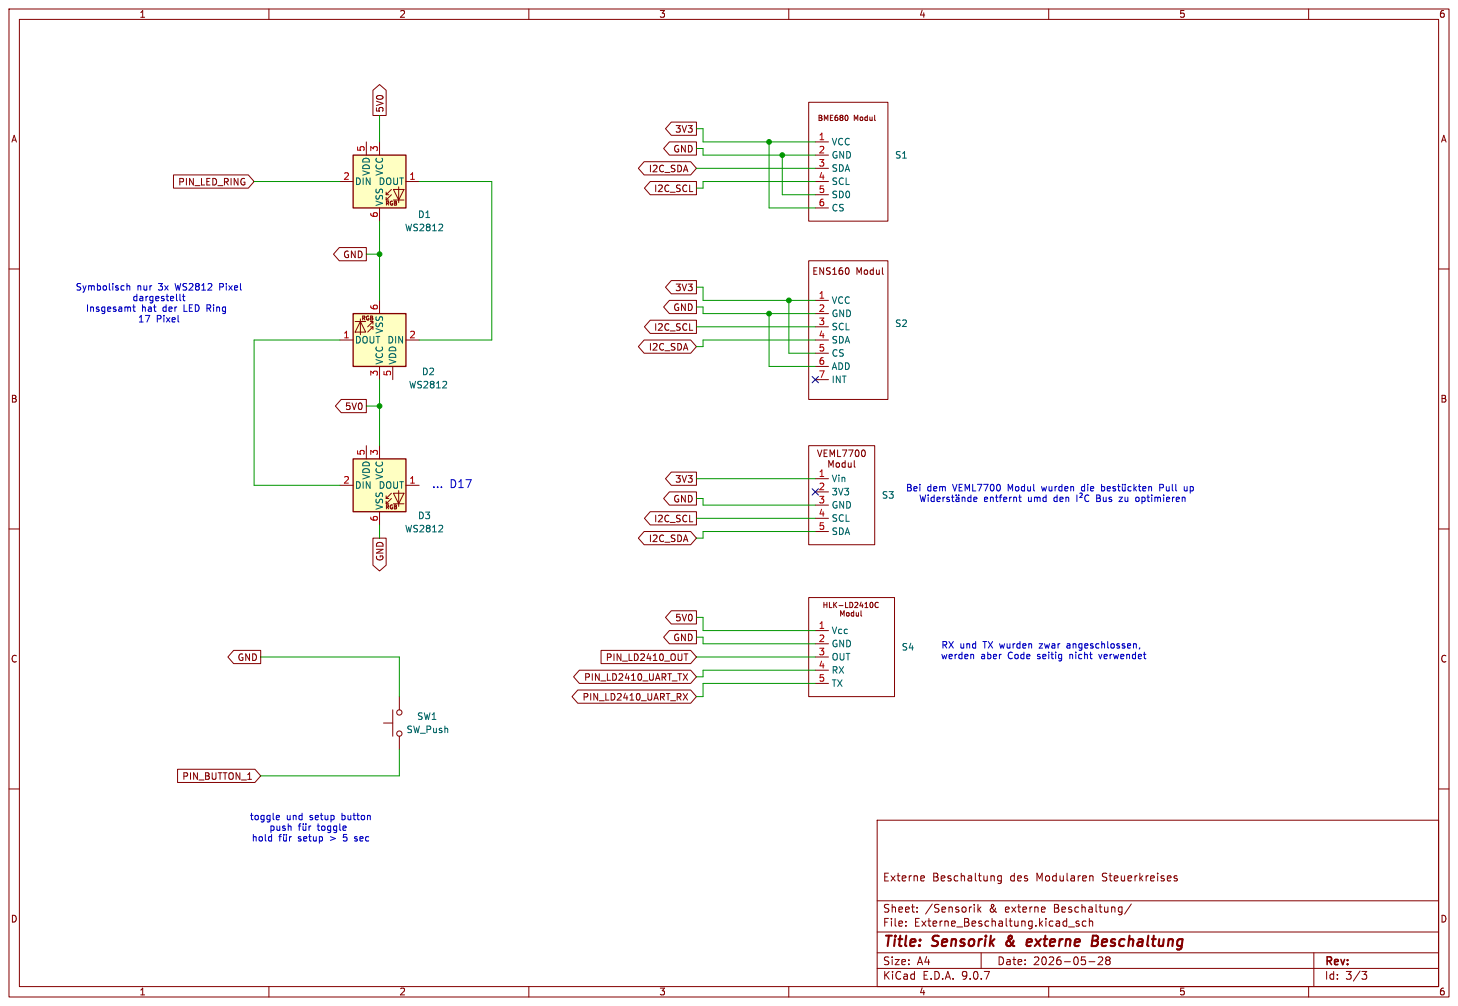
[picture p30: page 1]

Bei dem VEML7700 Modul wurden die þÿbestückten Pull up

toggle und setup button
push þÿfür toggle

Id: 3/3 Title: Sensorik & externe Beschaltung

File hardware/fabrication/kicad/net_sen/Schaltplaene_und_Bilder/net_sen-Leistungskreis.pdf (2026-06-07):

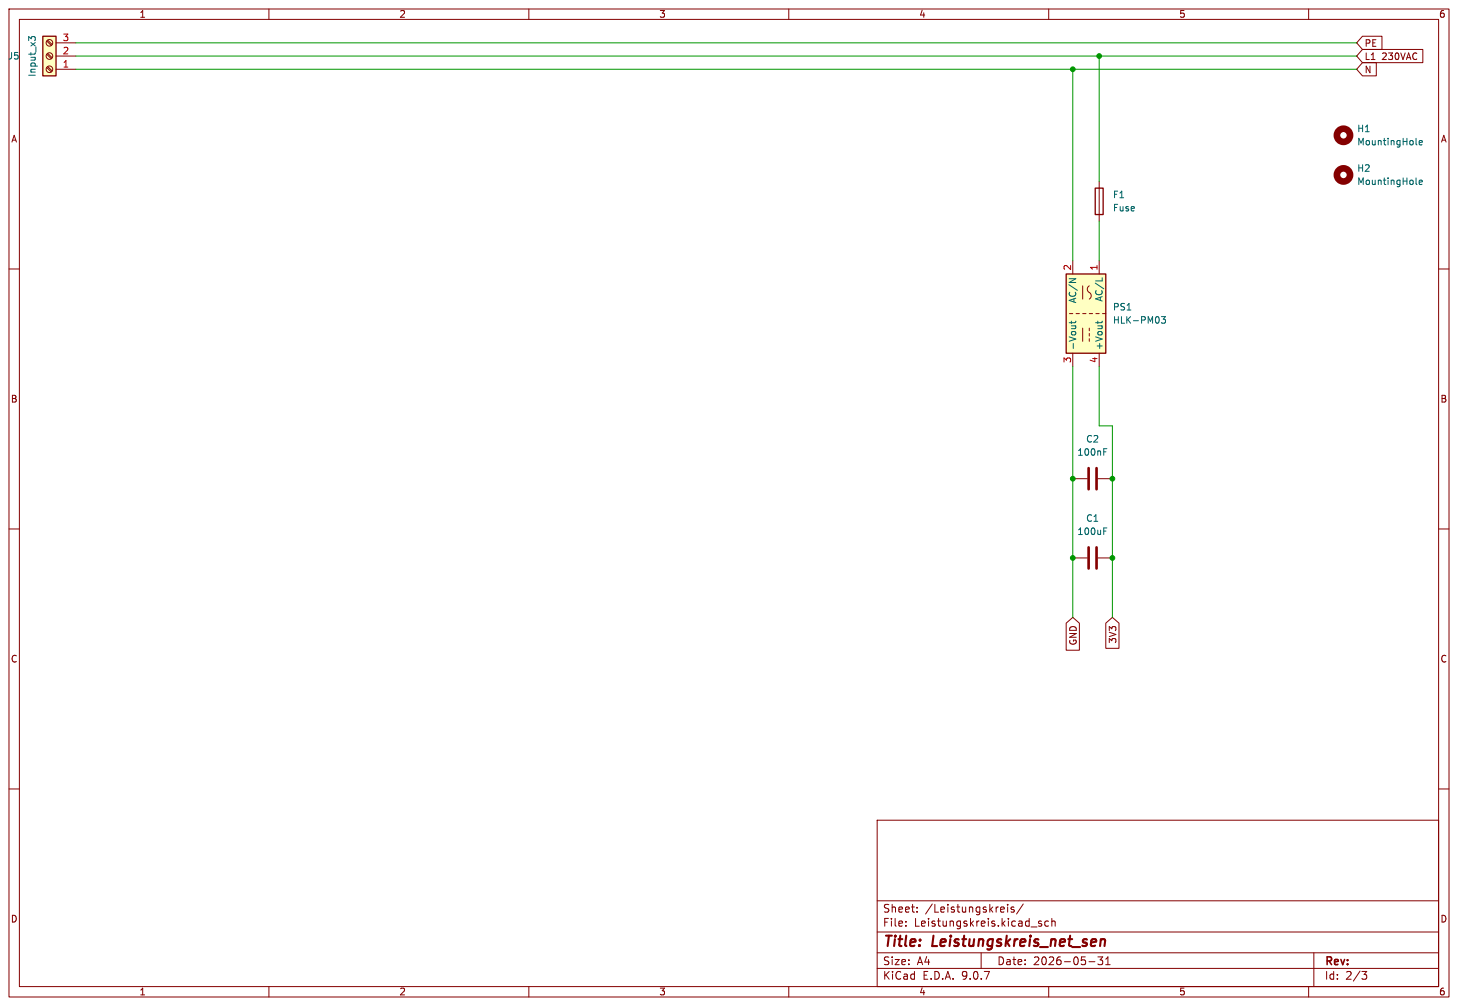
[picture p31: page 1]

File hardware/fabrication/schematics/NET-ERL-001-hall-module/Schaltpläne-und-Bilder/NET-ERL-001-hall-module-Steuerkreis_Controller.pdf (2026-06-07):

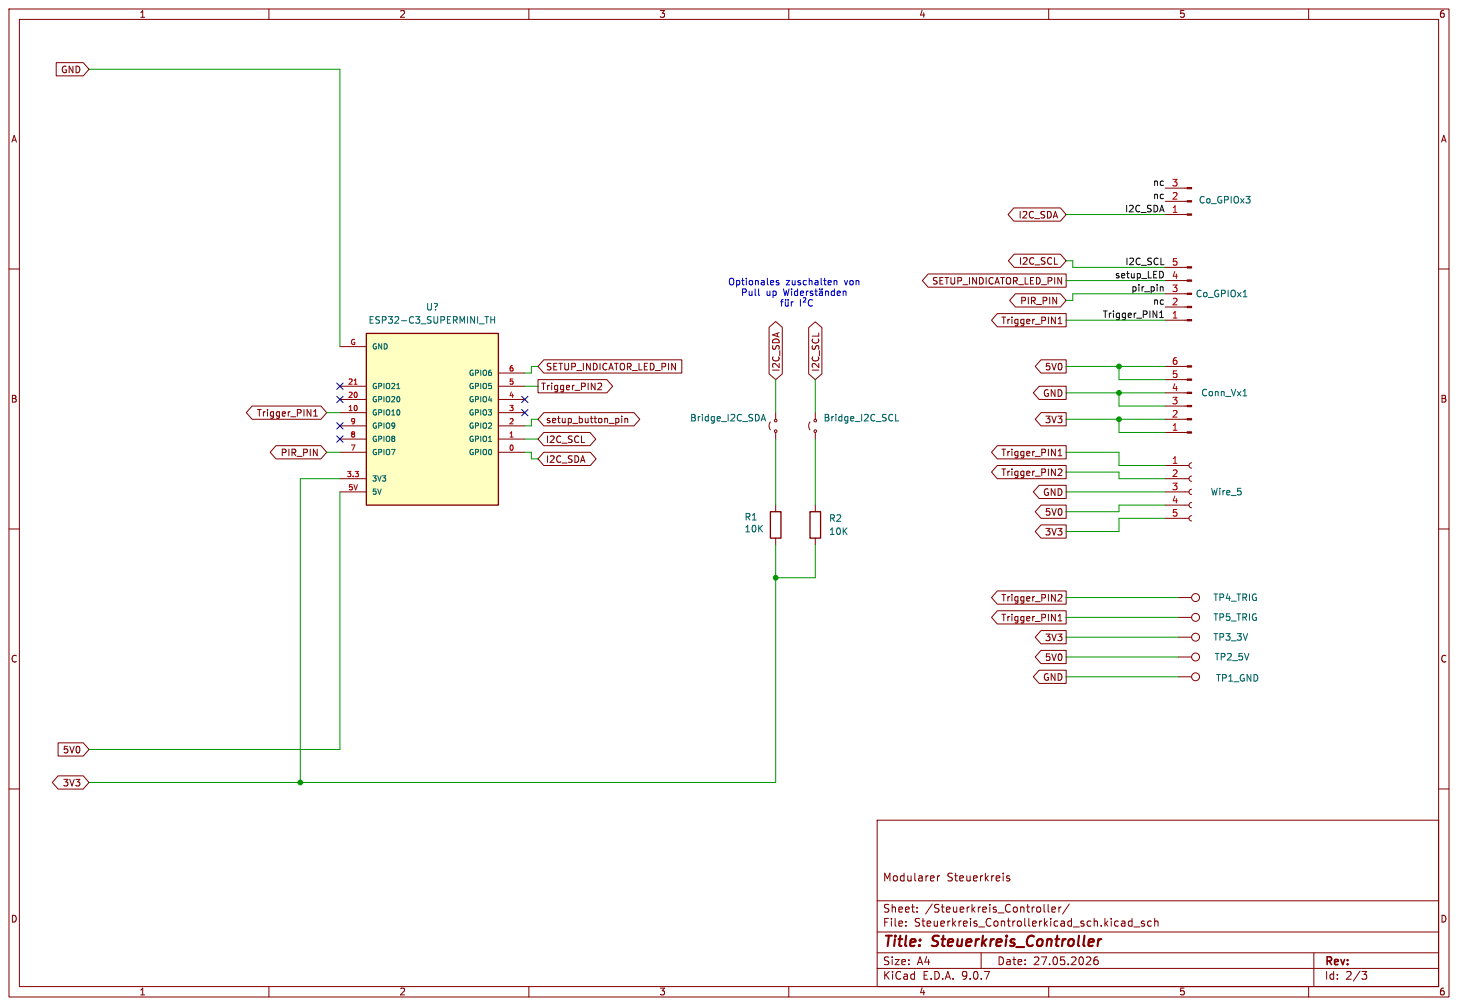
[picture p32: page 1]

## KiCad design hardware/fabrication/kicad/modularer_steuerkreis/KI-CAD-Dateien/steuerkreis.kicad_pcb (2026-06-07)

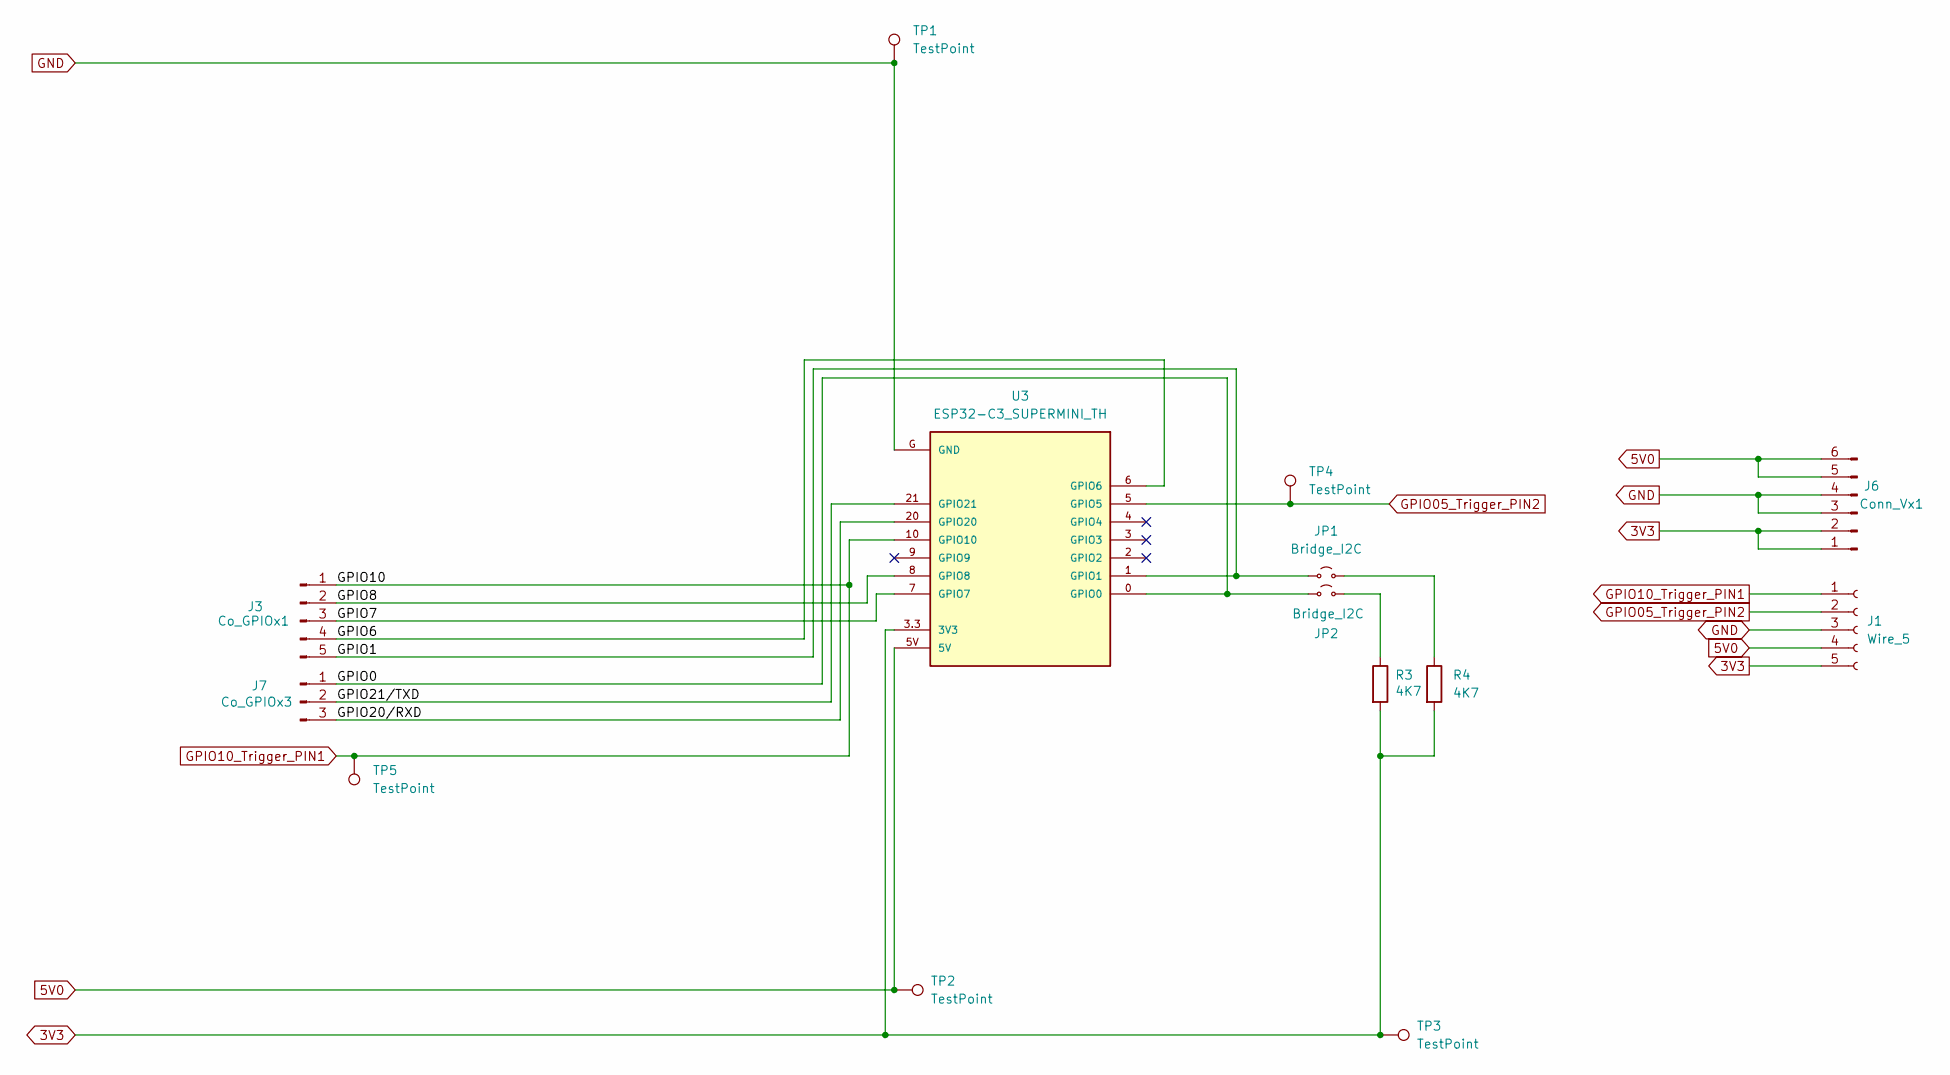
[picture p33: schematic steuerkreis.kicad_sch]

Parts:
J1: Wire_5; SolderWire-0.25sqmm_1x05_P4.2mm_D0.65mm_OD1.7mm
J3: Co_GPIOx1; PinHeader_1x05_P2.54mm_Vertical
J6: Conn_Vx1; PinHeader_1x06_P2.54mm_Vertical
J7: Co_GPIOx3; PinHeader_1x03_P2.54mm_Vertical
JP1, JP2: Bridge_I2C; SolderJumper-2_P1.3mm_Open_Pad1.0x1.5mm
R3, R4: 4K7; R_0805_2012Metric_Pad1.20x1.40mm_HandSolder
TP1, TP2, TP3, TP4, TP5: TestPoint; TestPoint_Pad_D1.0mm
U3: ESP32-C3_SUPERMINI_TH; MODULE_ESP32-C3_SUPERMINI_TH

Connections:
3V3: J1.5, J6.1, J6.2, R3.2, R4.2, TP3.1, U3.3.3 (3V3)
5V0: J1.4, J6.5, J6.6, TP2.1, U3.5V
/GPIO0: J7.1, JP2.1 (A), U3.0 (GPIO0)
/GPIO1: J3.5, JP1.1 (A), U3.1 (GPIO1)
/GPIO6: J3.4, U3.6 (GPIO6)
/GPIO7: J3.3, U3.7 (GPIO7)
/GPIO8: J3.2, U3.8 (GPIO8)
/GPIO20/RXD: J7.3, U3.20 (GPIO20)
/GPIO21/TXD: J7.2, U3.21 (GPIO21)
GND: J1.3, J6.3, J6.4, TP1.1, U3.G (GND)
GPIO05_Trigger_PIN2: J1.2, TP4.1, U3.5 (GPIO5)
GPIO10_Trigger_PIN1: J1.1, J3.1, TP5.1, U3.10 (GPIO10)
unnamed: JP1.2 (B), R4.1
unnamed: JP2.2 (B), R3.1

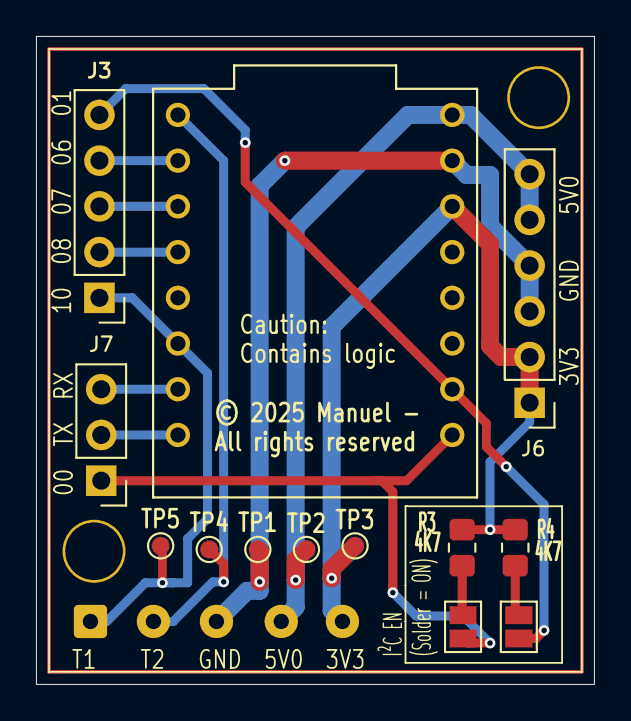
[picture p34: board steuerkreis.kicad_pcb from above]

Board: 2 copper layers, 31.0 x 36.0 mm, 16 parts (0 on the bottom side), 14 nets.

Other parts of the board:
MH: Mounting_Hole_M3
MH#2: Mounting_Hole_M3

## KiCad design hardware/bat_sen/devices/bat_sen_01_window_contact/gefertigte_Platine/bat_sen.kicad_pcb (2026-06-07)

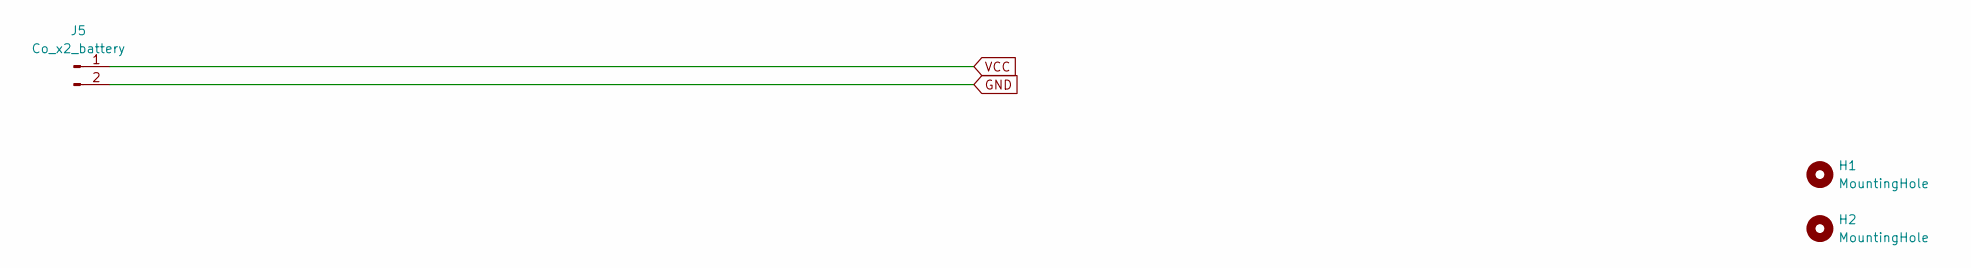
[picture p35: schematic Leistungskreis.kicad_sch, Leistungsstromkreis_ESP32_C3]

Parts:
H1, H2: MountingHole; MountingHole_3.2mm_M3_Pad
J5: Co_x2_battery; JST_PH_B2B-PH-K_1x02_P2.00mm_Vertical

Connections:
GND: J5.2; also elsewhere on the board
VCC: J5.1; also elsewhere on the board

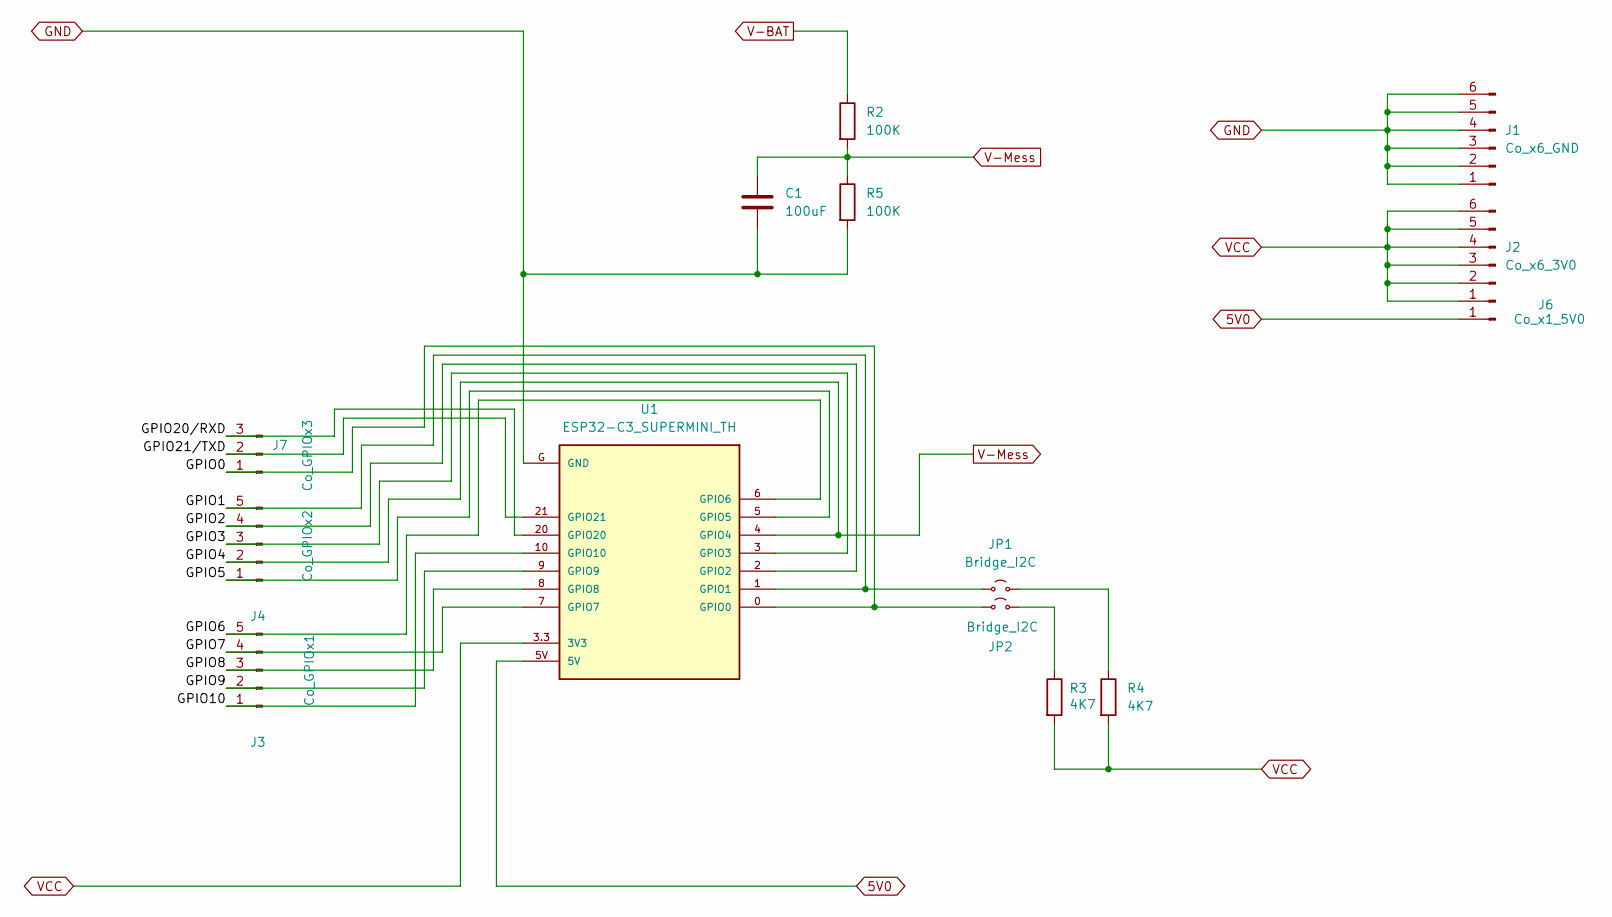
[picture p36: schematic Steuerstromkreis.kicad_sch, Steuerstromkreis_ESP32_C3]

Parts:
C1: 100uF; C_0603_1608Metric_Pad1.08x0.95mm_HandSolder
J1: Co_x6_GND; PinHeader_1x06_P2.54mm_Vertical
J2: Co_x6_3V0; PinHeader_1x06_P2.54mm_Vertical
J3: Co_GPIOx1; PinHeader_1x05_P2.54mm_Vertical
J4: Co_GPIOx2; PinHeader_1x05_P2.54mm_Vertical
J6: Co_x1_5V0; PinHeader_1x01_P2.54mm_Vertical
J7: Co_GPIOx3; PinHeader_1x03_P2.54mm_Vertical
JP1, JP2: Bridge_I2C; SolderJumper-2_P1.3mm_Open_Pad1.0x1.5mm
R2, R5: 100K; R_0603_1608Metric_Pad0.98x0.95mm_HandSolder
R3, R4: 4K7; R_0805_2012Metric_Pad1.20x1.40mm_HandSolder
U1: ESP32-C3_SUPERMINI_TH; MODULE_ESP32-C3_SUPERMINI_TH

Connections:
5V0: J6.1, U1.5V
/Steuerstromkreis/GPIO0: J7.1, JP2.1 (A), U1.0 (GPIO0)
/Steuerstromkreis/GPIO1: J4.5, JP1.1 (A), U1.1 (GPIO1)
/Steuerstromkreis/GPIO2: J4.4, U1.2 (GPIO2)
/Steuerstromkreis/GPIO3: J4.3, U1.3 (GPIO3)
/Steuerstromkreis/GPIO5: J4.1, U1.5 (GPIO5)
/Steuerstromkreis/GPIO6: J3.5, U1.6 (GPIO6)
/Steuerstromkreis/GPIO7: J3.4, U1.7 (GPIO7)
/Steuerstromkreis/GPIO8: J3.3, U1.8 (GPIO8)
/Steuerstromkreis/GPIO9: J3.2, U1.9 (GPIO9)
/Steuerstromkreis/GPIO10: J3.1, U1.10 (GPIO10)
/Steuerstromkreis/GPIO20/RXD: J7.3, U1.20 (GPIO20)
/Steuerstromkreis/GPIO21/TXD: J7.2, U1.21 (GPIO21)
GND: C1.1, J1.1, J1.2, J1.3, J1.4, J1.5, J1.6, R5.2, U1.G (GND); also elsewhere on the board
unnamed: JP1.2 (B), R4.1
unnamed: JP2.2 (B), R3.1
V-BAT: R2.1
V-Mess: C1.2, J4.2, R2.2, R5.1, U1.4 (GPIO4)
VCC: J2.1, J2.2, J2.3, J2.4, J2.5, J2.6, R3.2, R4.2, U1.3.3 (3V3); also elsewhere on the board

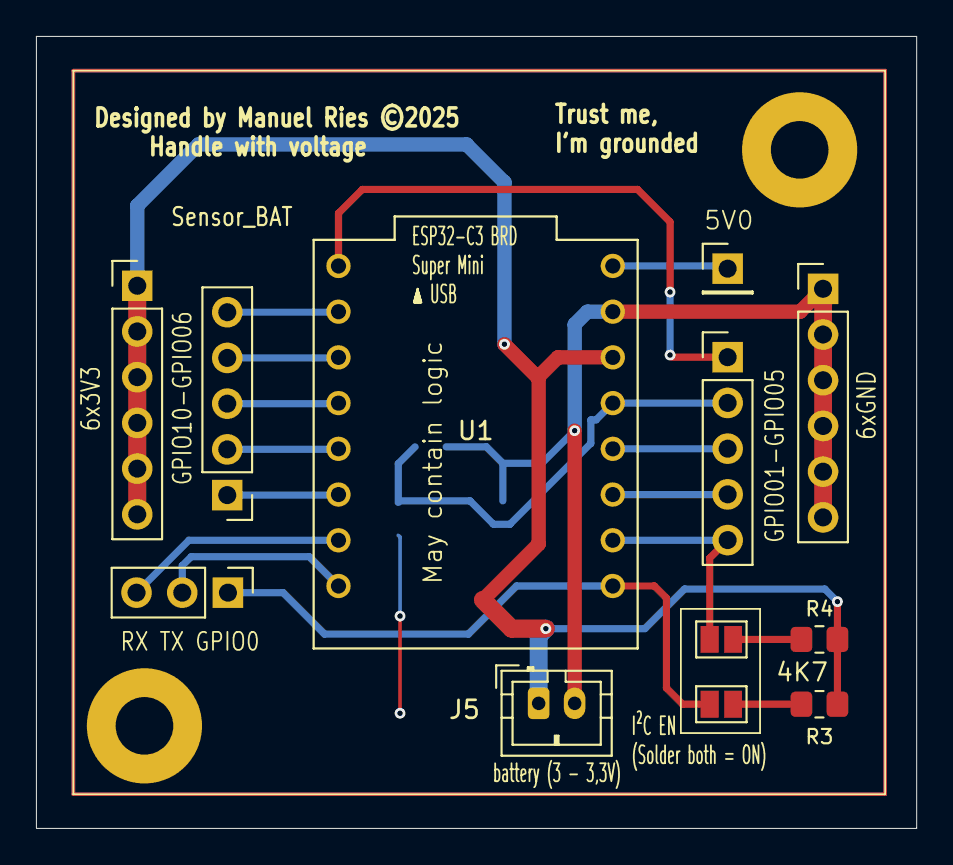
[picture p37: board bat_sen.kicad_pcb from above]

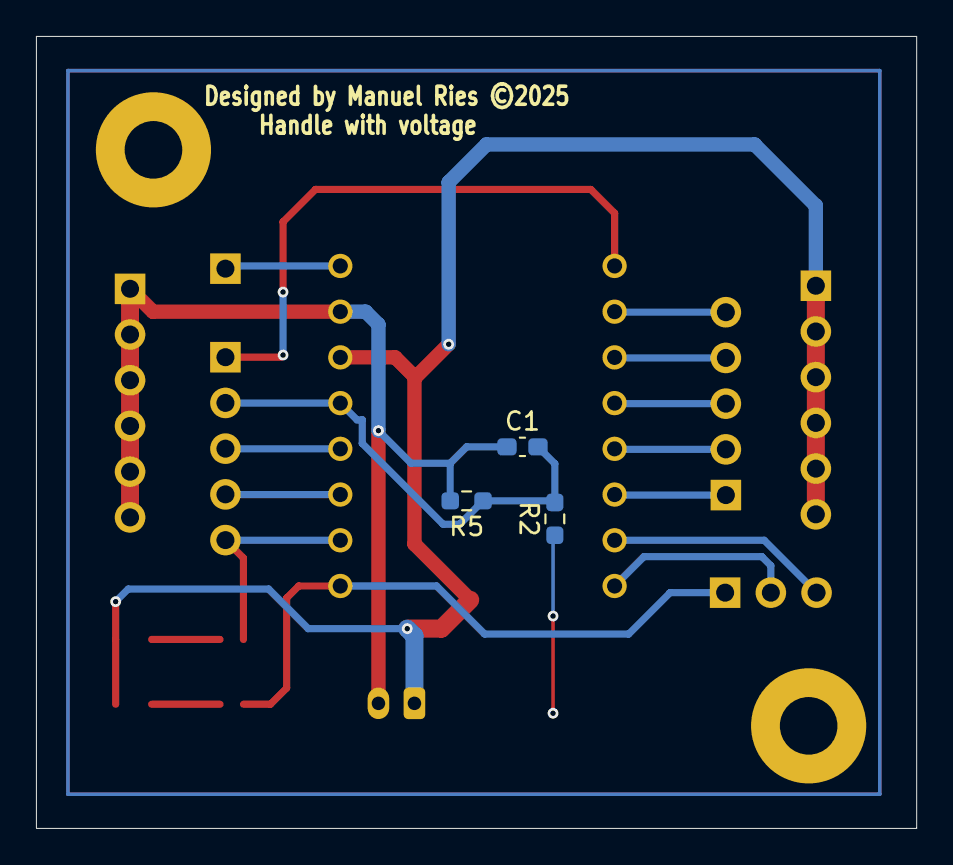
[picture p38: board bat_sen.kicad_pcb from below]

Board: 2 copper layers, 48.9 x 44.0 mm, 17 parts (3 on the bottom side), 18 nets.

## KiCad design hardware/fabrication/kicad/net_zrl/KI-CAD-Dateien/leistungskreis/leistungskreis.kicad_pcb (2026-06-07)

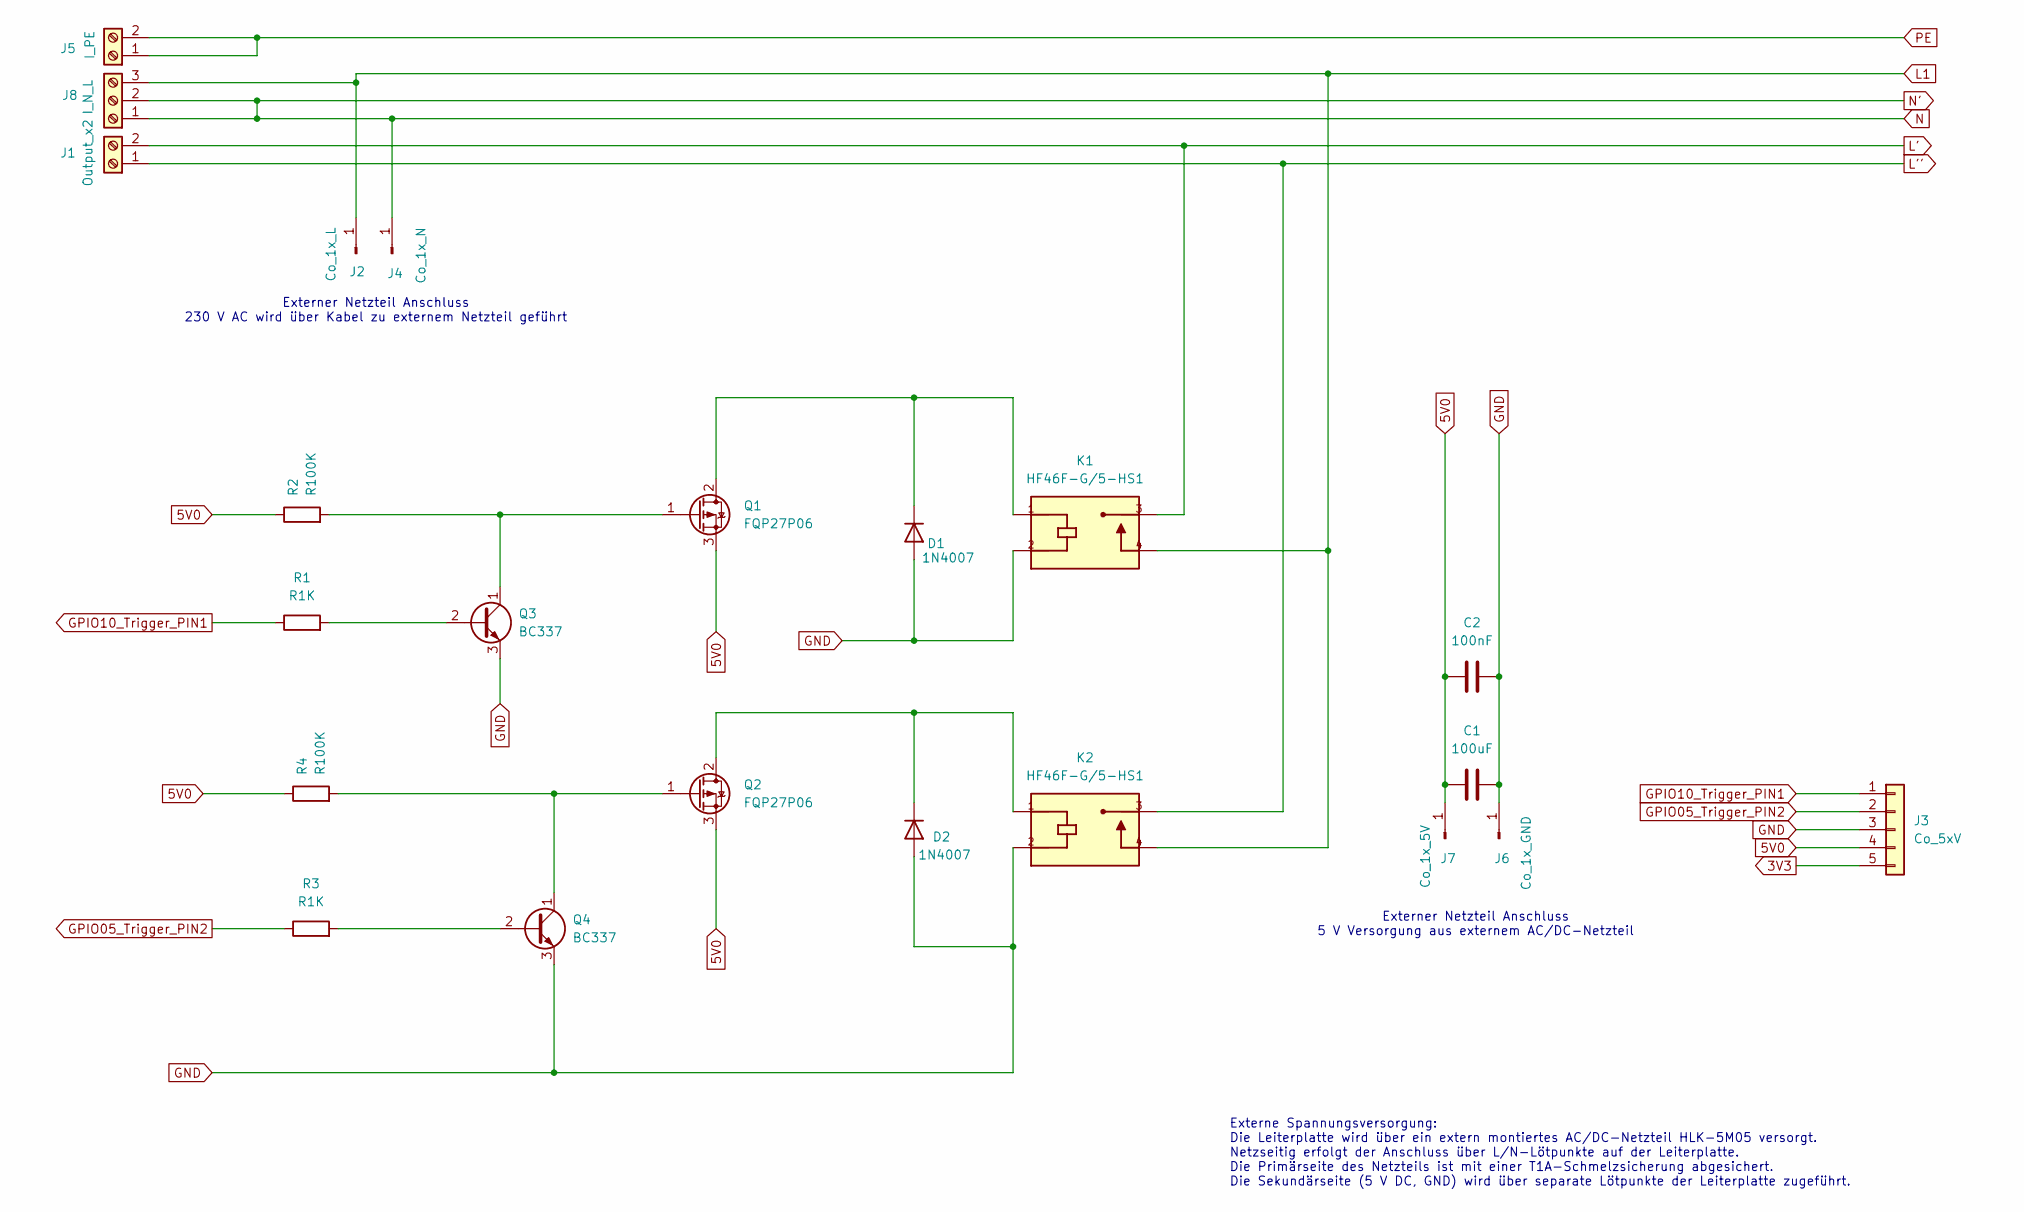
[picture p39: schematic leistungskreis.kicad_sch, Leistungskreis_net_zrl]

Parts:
C1: 100uF; CP_Elec_6.3x5.8
C2: 100nF; C_0805_2012Metric_Pad1.18x1.45mm_HandSolder
D1, D2: 1N4007; D_SOD-123
J1: Output_x2; TerminalBlock_Phoenix_MKDS-1,5-2_1x02_P5.00mm_Horizontal
J2: Co_1x_L; SolderWire-0.75sqmm_1x01_D1.25mm_OD2.3mm
J3: Co_5xV; JST_PH_B5B-PH-K_1x05_P2.00mm_Vertical
J4: Co_1x_N; SolderWire-0.75sqmm_1x01_D1.25mm_OD2.3mm
J5: I_PE; TerminalBlock_Phoenix_MKDS-1,5-2_1x02_P5.00mm_Horizontal
J6: Co_1x_GND; SolderWire-0.75sqmm_1x01_D1.25mm_OD2.3mm
J7: Co_1x_5V; SolderWire-0.75sqmm_1x01_D1.25mm_OD2.3mm
J8: I_N_L; TerminalBlock_Phoenix_MKDS-1,5-3_1x03_P5.00mm_Horizontal
K1, K2: HF46F-G/5-HS1; RELAY_HF46F_005-HS1; PARTREV 1.00
Q1, Q2: FQP27P06; TO-220-3_Vertical
Q3, Q4: BC337; TO-92_Inline
R1, R3: R1K; R_0805_2012Metric_Pad1.20x1.40mm_HandSolder
R2, R4: R100K; R_0805_2012Metric_Pad1.20x1.40mm_HandSolder

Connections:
3V3: J3.5
5V0: C1.1, C2.1, J3.4, J7.1, Q1.3 (S), Q2.3 (S), R2.1, R4.1
GND: C1.2, C2.2, D1.2 (A), D2.2 (A), J3.3, J6.1, K1.2, K2.2, Q3.3 (E), Q4.3 (E)
GPIO05_Trigger_PIN2: J3.2, R3.1
GPIO10_Trigger_PIN1: J3.1, R1.1
L1: J2.1, J8.3, K1.4, K2.4
L': J1.2, K1.3
L'': J1.1, K2.3
N: J4.1, J8.1, J8.2
unnamed: D1.1 (K), K1.1, Q1.2 (D)
unnamed: D2.1 (K), K2.1, Q2.2 (D)
unnamed: Q1.1 (G), Q3.1 (C), R2.2
unnamed: Q2.1 (G), Q4.1 (C), R4.2
unnamed: Q3.2 (B), R1.2
unnamed: Q4.2 (B), R3.2
PE: J5.1, J5.2

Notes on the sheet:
Externer Netzteil Anschluss 230 V AC wird über Kabel zu externem Netzteil geführt
Externer Netzteil Anschluss 5 V Versorgung aus externem AC/DC-Netzteil
Externe Spannungsversorgung: Die Leiterplatte wird über ein extern montiertes AC/DC-Netzteil HLK-5M05 versorgt. Netzseitig erfolgt der Anschluss über L/N-Lötpunkte auf der Leiterplatte. Die Primärseite des Netzteils ist mit einer T1A-Schmelzsicherung abgesichert. Die Sekundärseite (5 V DC, GND) wir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

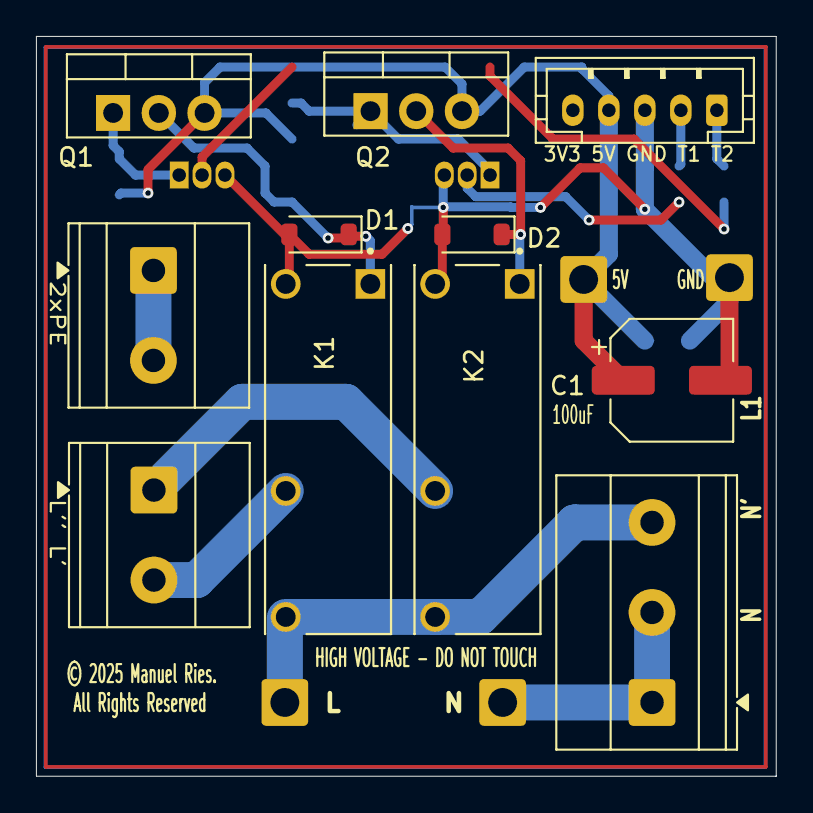
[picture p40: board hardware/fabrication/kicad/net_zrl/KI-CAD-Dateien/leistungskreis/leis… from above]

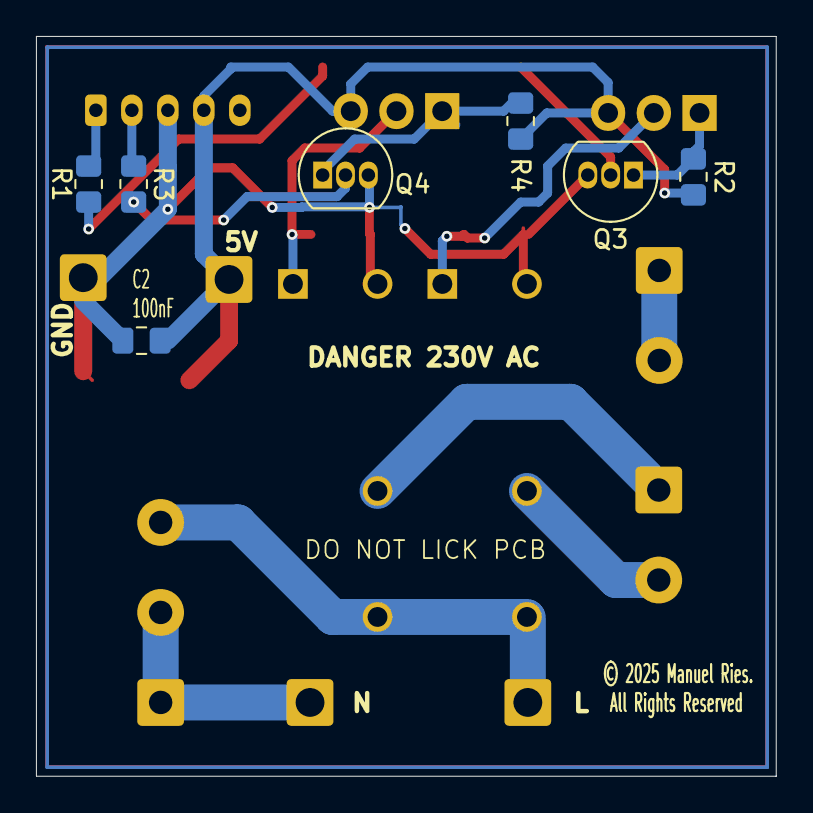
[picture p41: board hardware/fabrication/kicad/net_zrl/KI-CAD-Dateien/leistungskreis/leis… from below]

Board: 2 copper layers, 41.1 x 41.1 mm, 22 parts (7 on the bottom side), 15 nets.

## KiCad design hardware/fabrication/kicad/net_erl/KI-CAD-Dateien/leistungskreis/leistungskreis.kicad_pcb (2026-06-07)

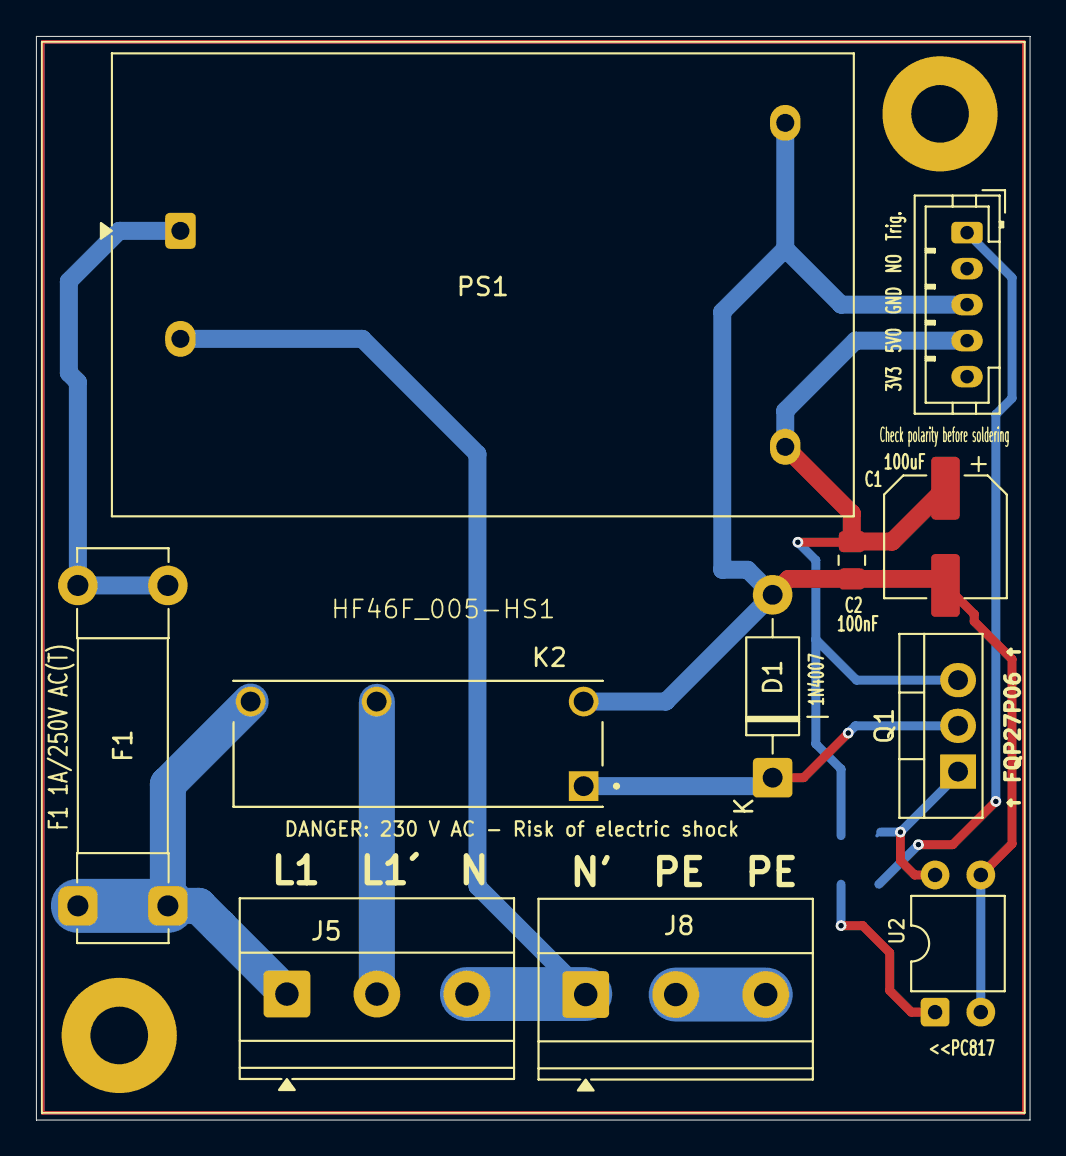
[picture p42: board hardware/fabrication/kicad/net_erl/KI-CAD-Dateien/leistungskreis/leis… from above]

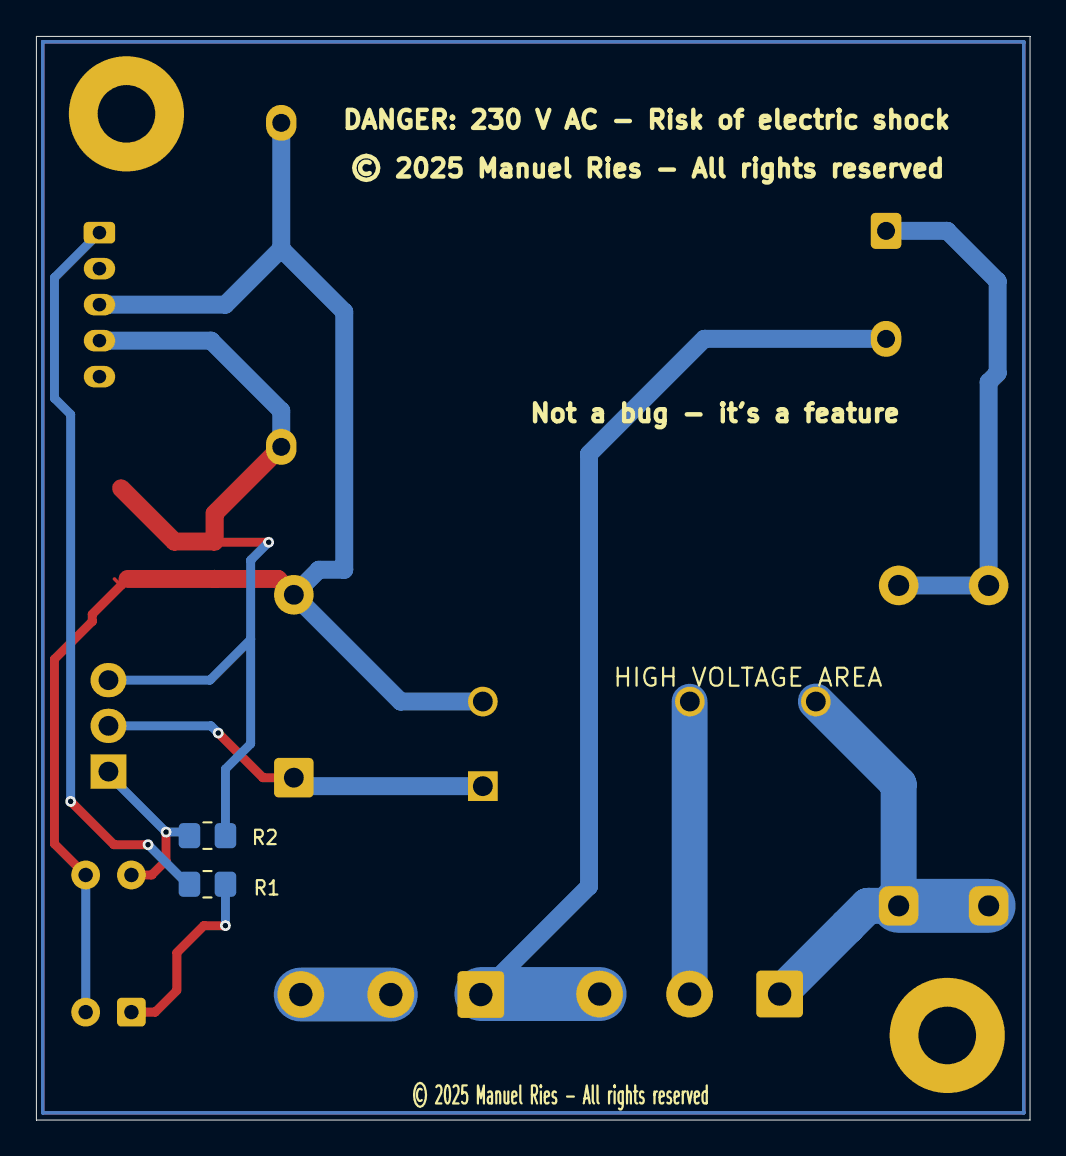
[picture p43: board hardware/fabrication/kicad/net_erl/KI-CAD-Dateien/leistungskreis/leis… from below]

Board: 2 copper layers, 55.2 x 60.2 mm, 15 parts (2 on the bottom side), 11 nets.

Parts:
C1: 100uF; CP_Elec_6.3x5.8
C2: 100nF; C_0805_2012Metric_Pad1.18x1.45mm_HandSolder
D1: 1N4007; D_DO-41_SOD81_P10.16mm_Horizontal
F1: Fuse; Fuseholder_Clip-5x20mm_Bel_FC-203-22_Lateral_P17.80x5.00mm_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
H1, H2: MountingHole; MountingHole_3.2mm_M3_Pad
J1: Co_5xV; JST_PH_B5B-PH-K_1x05_P2.00mm_Vertical
J5: Co_x3; TerminalBlock_Phoenix_MKDS-1,5-3_1x03_P5.00mm_Horizontal
J8: Co_x31; TerminalBlock_Phoenix_MKDS-1,5-3_1x03_P5.00mm_Horizontal
K2: HF46F_005-HS1; RELAY_HF46F_005-HS1
PS1: HLK-5M05; Converter_ACDC_Hi-Link_HLK-5Mxx
Q1: FQP27P06; TO-220-3_Vertical
R1: R330; R_0805_2012Metric_Pad1.20x1.40mm_HandSolder
R2: R100K; R_0805_2012Metric_Pad1.20x1.40mm_HandSolder
U2: PC817; DIP-4_W7.62mm

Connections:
5V0: C1.1, C2.1, J1.4, PS1.4 (+Vout), Q1.3 (S), R2.1
GND: C1.2, C2.2, D1.2 (A), J1.3, K2.2, PS1.3 (-Vout), U2.2, U2.3
GPIO10_Trigger_PIN1: J1.1, R1.1
L1 230VAC: F1.1, J5.1, K2.4
N: J5.3, J8.1, PS1.2 (AC/N)
unnamed: D1.1 (K), K2.1, Q1.2 (D)
unnamed: J5.2, K2.3
unnamed: F1.2, PS1.1 (AC/L)
unnamed: Q1.1 (G), R2.2, U2.4
unnamed: R1.2, U2.1
PE: J8.2, J8.3

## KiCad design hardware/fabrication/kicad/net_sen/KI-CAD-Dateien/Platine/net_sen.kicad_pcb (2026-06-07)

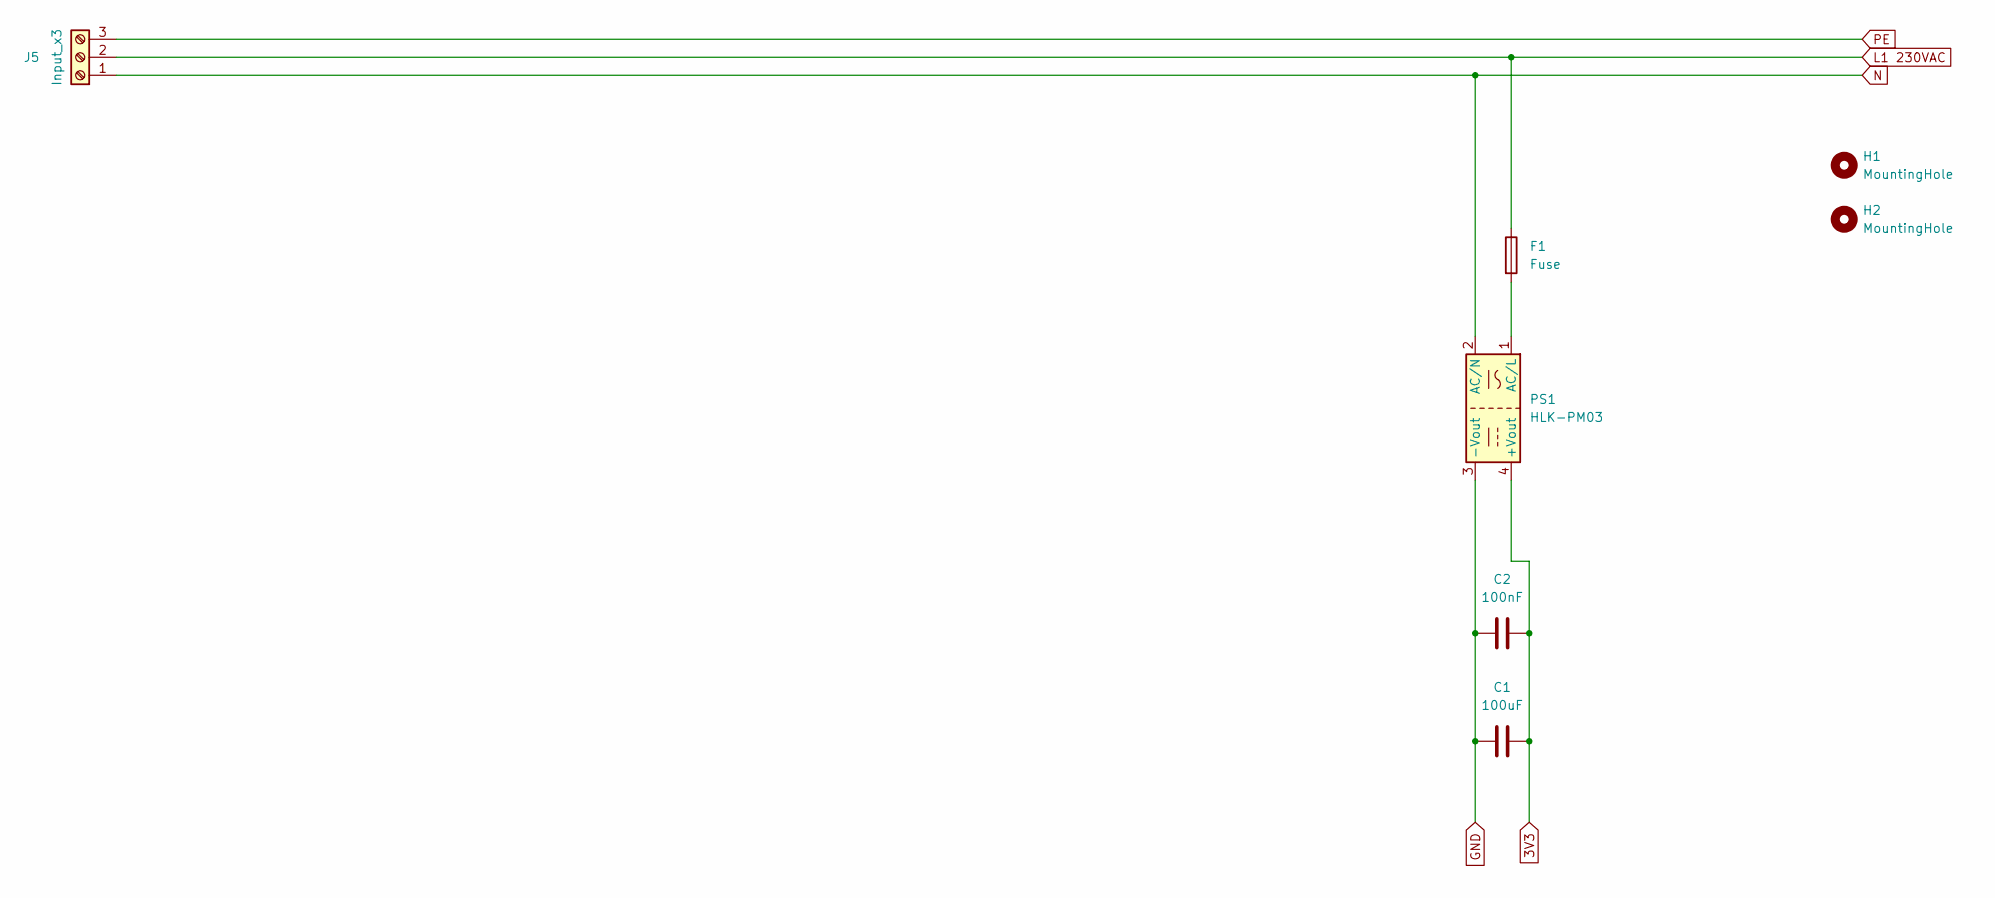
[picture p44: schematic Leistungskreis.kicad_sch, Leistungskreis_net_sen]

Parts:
C1: 100uF; CP_Elec_6.3x5.8
C2: 100nF; C_0805_2012Metric_Pad1.18x1.45mm_HandSolder
F1: Fuse; Fuseholder_Clip-5x20mm_Bel_FC-203-22_Lateral_P17.80x5.00mm_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
H1, H2: MountingHole; Mounting_Hole_M3
J5: Input_x3; TerminalBlock_Phoenix_MKDS-1,5-3_1x03_P5.00mm_Horizontal
PS1: HLK-PM03; Converter_ACDC_Hi-Link_HLK-PMxx

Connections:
3V3: C1.1, C2.2, PS1.4 (+Vout); also elsewhere on the board
GND: C1.2, C2.1, PS1.3 (-Vout); also elsewhere on the board
L1 230VAC: F1.1, J5.2
N: J5.1, PS1.2 (AC/N)
unnamed: F1.2, PS1.1 (AC/L)
PE: J5.3


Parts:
J1: Co_x6_GND; PinHeader_1x06_P2.54mm_Vertical
J2: Co_x6_3V3; PinHeader_1x06_P2.54mm_Vertical
J3: Co_GPIOx1; PinHeader_1x05_P2.54mm_Vertical
J4: Co_GPIOx2; PinHeader_1x05_P2.54mm_Vertical
J6: Co_x1_5V0; PinHeader_1x01_P2.54mm_Vertical
J7: Co_GPIOx3; PinHeader_1x03_P2.54mm_Vertical
JP1, JP2: Bridge_I2C; SolderJumper-2_P1.3mm_Open_Pad1.0x1.5mm
R3, R4: 4K7; R_0805_2012Metric_Pad1.20x1.40mm_HandSolder
U1: ESP32-C3_SUPERMINI_TH; MODULE_ESP32-C3_SUPERMINI_TH

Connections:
3V3: J2.1, J2.2, J2.3, J2.4, J2.5, J2.6, R3.2, R4.2, U1.3.3 (3V3); also elsewhere on the board
5V0: J6.1, U1.5V; also elsewhere on the board
/Steuerstromkreis/GPIO0: J7.1, JP2.1 (A), U1.0 (GPIO0); also elsewhere on the board
/Steuerstromkreis/GPIO1: J4.5, JP1.1 (A), U1.1 (GPIO1); also elsewhere on the board
/Steuerstromkreis/GPIO2: J4.4, U1.2 (GPIO2); also elsewhere on the board
/Steuerstromkreis/GPIO3: J4.3, U1.3 (GPIO3); also elsewhere on the board
/Steuerstromkreis/GPIO4: J4.2, U1.4 (GPIO4); also elsewhere on the board
/Steuerstromkreis/GPIO5: J4.1, U1.5 (GPIO5); also elsewhere on the board
/Steuerstromkreis/GPIO6: J3.5, U1.6 (GPIO6); also elsewhere on the board
/Steuerstromkreis/GPIO7: J3.4, U1.7 (GPIO7); also elsewhere on the board
/Steuerstromkreis/GPIO8: J3.3, U1.8 (GPIO8); also elsewhere on the board
/Steuerstromkreis/GPIO9: J3.2, U1.9 (GPIO9); also elsewhere on the board
/Steuerstromkreis/GPIO10: J3.1, U1.10 (GPIO10); also elsewhere on the board
/Steuerstromkreis/GPIO20/RXD: J7.3, U1.20 (GPIO20); also elsewhere on the board
/Steuerstromkreis/GPIO21/TXD: J7.2, U1.21 (GPIO21); also elsewhere on the board
GND: J1.1, J1.2, J1.3, J1.4, J1.5, J1.6, U1.G (GND); also elsewhere on the board
unnamed: JP1.2 (B), R4.1
unnamed: JP2.2 (B), R3.1

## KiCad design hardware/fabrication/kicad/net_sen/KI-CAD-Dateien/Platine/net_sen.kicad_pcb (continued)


Board: 2 copper layers, 70.3 x 55.1 mm, 18 parts (0 on the bottom side), 21 nets.

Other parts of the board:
ESP32-C3_SUPERMINI_TH: ESP32-C3_SUPERMINI_TH; MODULE_ESP32-C3_SUPERMINI_TH

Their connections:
3V3: ESP32-C3_SUPERMINI_TH.3.3 (3V3); also elsewhere on the board
5V0: ESP32-C3_SUPERMINI_TH.5V; also elsewhere on the board
/Steuerstromkreis/GPIO0: ESP32-C3_SUPERMINI_TH.0 (GPIO0); also elsewhere on the board
/Steuerstromkreis/GPIO1: ESP32-C3_SUPERMINI_TH.1 (GPIO1); also elsewhere on the board
/Steuerstromkreis/GPIO2: ESP32-C3_SUPERMINI_TH.2 (GPIO2); also elsewhere on the board
/Steuerstromkreis/GPIO3: ESP32-C3_SUPERMINI_TH.3 (GPIO3); also elsewhere on the board
/Steuerstromkreis/GPIO4: ESP32-C3_SUPERMINI_TH.4 (GPIO4); also elsewhere on the board
/Steuerstromkreis/GPIO5: ESP32-C3_SUPERMINI_TH.5 (GPIO5); also elsewhere on the board
/Steuerstromkreis/GPIO6: ESP32-C3_SUPERMINI_TH.6 (GPIO6); also elsewhere on the board
/Steuerstromkreis/GPIO7: ESP32-C3_SUPERMINI_TH.7 (GPIO7); also elsewhere on the board
/Steuerstromkreis/GPIO8: ESP32-C3_SUPERMINI_TH.8 (GPIO8); also elsewhere on the board
/Steuerstromkreis/GPIO9: ESP32-C3_SUPERMINI_TH.9 (GPIO9); also elsewhere on the board
/Steuerstromkreis/GPIO10: ESP32-C3_SUPERMINI_TH.10 (GPIO10); also elsewhere on the board
/Steuerstromkreis/GPIO20/RXD: ESP32-C3_SUPERMINI_TH.20 (GPIO20); also elsewhere on the board
/Steuerstromkreis/GPIO21/TXD: ESP32-C3_SUPERMINI_TH.21 (GPIO21); also elsewhere on the board
GND: ESP32-C3_SUPERMINI_TH.G (GND); also elsewhere on the board

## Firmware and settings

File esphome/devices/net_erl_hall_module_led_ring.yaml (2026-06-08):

substitutions:
  node_name: net-erl-020
  device_name: NET-ERL Hall Module LED Ring
  setup_ap_password: net-erl-setup
  relay_pin: GPIO10
  button_pin: GPIO6
  pir_pin: GPIO7
  i2c_sda_pin: GPIO0
  i2c_scl_pin: GPIO1
  veml7700_address: "0x10"
  led_ring_pin: GPIO4
  led_ring_count: "17"

esphome:
  name: ${node_name}
  friendly_name: ${device_name}

esp32:
  board: esp32-c3-devkitm-1
  framework:
    type: arduino

logger:

api:

ota:
  - platform: esphome
    password: !secret ota_password

wifi:
  ssid: !secret wifi_ssid
  password: !secret wifi_password
  ap:
    ssid: "${node_name}-setup"
    password: ${setup_ap_password}

captive_portal:

i2c:
  sda: ${i2c_sda_pin}
  scl: ${i2c_scl_pin}
  scan: true

globals:
  - id: led_ring_red
    type: float
    restore_value: yes
    initial_value: "1.0"
  - id: led_ring_green
    type: float
    restore_value: yes
    initial_value: "0.0"
  - id: led_ring_blue
    type: float
    restore_value: yes
    initial_value: "0.0"
  - id: animation_mode_id
    type: int
    restore_value: yes
    initial_value: "1"
  - id: motion_hold_until_ms
    type: uint32_t
    restore_value: no
    initial_value: "0"
  - id: motion_active
    type: bool
    restore_value: no
    initial_value: "false"
  - id: auto_light_owned
    type: bool
    restore_value: no
    initial_value: "false"

output:
  - platform: gpio
    id: relay_output
    pin: ${relay_pin}

light:
  - platform: binary
    id: hall_light
    name: "Hall Light"
    output: relay_output
    restore_mode: RESTORE_DEFAULT_OFF

  - platform: fastled_clockless
    id: led_ring_light
    internal: true
    pin: ${led_ring_pin}
    num_leds: ${led_ring_count}
    chipset: WS2812B
    rgb_order: GRB
    restore_mode: ALWAYS_OFF

switch:
  - platform: template
    id: auto_light_enabled
    name: "Automatic Light Control"
    icon: mdi:lightbulb-auto
    entity_category: config
    optimistic: true
    restore_mode: RESTORE_DEFAULT_ON
    turn_on_action:
      - script.execute: sync_relay_state
    turn_off_action:
      - script.execute: sync_relay_state

  - platform: template
    id: led_ring_enabled
    name: "LED Ring Motion Display"
    icon: mdi:led-strip-variant
    entity_category: config
    optimistic: true
    restore_mode: RESTORE_DEFAULT_ON
    turn_on_action:
      - script.execute: sync_led_ring_state
    turn_off_action:
      - script.execute: sync_led_ring_state

number:
  - platform: template
    id: led_ring_brightness
    name: "LED Ring Brightness Percent"
    icon: mdi:brightness-6
    entity_category: config
    optimistic: true
    restore_value: true
    initial_value: 30
    min_value: 1
    max_value: 100
    step: 1
    mode: slider
    set_action:
      - script.execute: sync_led_ring_state

  - platform: template
    id: led_ring_red_level
    name: "LED Ring Color Red"
    entity_category: config
    optimistic: true
    restore_value: true
    initial_value: 255
    min_value: 0
    max_value: 255
    step: 1
    mode: slider
    set_action:
      - lambda: |-
          id(led_ring_red) = x / 255.0f;
      - script.execute: sync_led_ring_state

  - platform: template
    id: led_ring_green_level
    name: "LED Ring Color Green"
    entity_category: config
    optimistic: true
    restore_value: true
    initial_value: 0
    min_value: 0
    max_value: 255
    step: 1
    mode: slider
    set_action:
      - lambda: |-
          id(led_ring_green) = x / 255.0f;
      - script.execute: sync_led_ring_state

  - platform: template
    id: led_ring_blue_level
    name: "LED Ring Color Blue"
    entity_category: config
    optimistic: true
    restore_value: true
    initial_value: 0
    min_value: 0
    max_value: 255
    step: 1
    mode: slider
    set_action:
      - lambda: |-
          id(led_ring_blue) = x / 255.0f;
      - script.execute: sync_led_ring_state

  - platform: template
    id: led_ring_display_value
    name: "LED Ring Source Value"
    icon: mdi:gauge
    entity_category: config
    optimistic: true
    restore_value: true
    initial_value: 25
    min_value: -50
    max_value: 150
    step: 0.5
    mode: box
    set_action:
      - script.execute: sync_led_ring_state

  - platform: template
    id: led_ring_scale_min
    name: "LED Ring Scale Minimum"
    entity_category: config
    optimistic: true
    restore_value: true
    initial_value: 0
    min_value: -50
    max_value: 150
    step: 0.5
    mode: box
    set_action:
      - script.execute: sync_led_ring_state

  - platform: template
    id: led_ring_scale_max
    name: "LED Ring Scale Maximum"
    entity_category: config
    optimistic: true
    restore_value: true
    initial_value: 42.5
    min_value: -50
    max_value: 200
    step: 0.5
    mode: box
    set_action:
      - script.execute: sync_led_ring_state
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

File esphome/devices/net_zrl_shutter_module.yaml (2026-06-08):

substitutions:
  node_name: net-zrl-020
  device_name: NET-ZRL Shutter
  setup_ap_password: net-zrl-setup
  relay_up_pin: GPIO10
  relay_down_pin: GPIO5
  button_up_pin: GPIO20
  button_down_pin: GPIO4
  button_stop_pin: GPIO3
  led_up_pin: GPIO7
  led_down_pin: GPIO6
  default_cover_travel_ms: "60000"

esphome:
  name: ${node_name}
  friendly_name: ${device_name}
  comment: Standard ESPHome shutter with native Home Assistant API
  on_boot:
    priority: -10
    then:
      - lambda: |-
          id(cover_state_text) = "stopped";
          id(cover_calibrated) =
            id(cover_travel_up_ms) >= 1000 && id(cover_travel_down_ms) >= 1000;
          if (!id(cover_calibrated)) {
            id(cover_position_percent) = 255;
          }
      - script.execute: publish_cover_state

esp32:
  board: esp32-c3-devkitm-1
  toolchain: platformio
  framework:
    type: arduino

logger:
  level: DEBUG

api:

ota:
  - platform: esphome
    password: !secret ota_password

wifi:
  ssid: !secret wifi_ssid
  password: !secret wifi_password
  ap:
    ssid: ${node_name}-setup
    password: ${setup_ap_password}

captive_portal:

web_server:

globals:
  - id: stop_button_pressed_at_ms
    type: uint32_t
    restore_value: no
    initial_value: "0"
  - id: stop_button_hold_consumed
    type: bool
    restore_value: no
    initial_value: "false"
  - id: down_button_pressed_at_ms
    type: uint32_t
    restore_value: no
    initial_value: "0"
  - id: down_button_hold_consumed
    type: bool
    restore_value: no
    initial_value: "false"
  - id: led_blink_phase
    type: bool
    restore_value: no
    initial_value: "false"
  - id: cover_state_text
    type: std::string
    restore_value: no
    initial_value: '"stopped"'
  - id: cover_position_percent
    type: int
    restore_value: no
    initial_value: "255"
  - id: cover_target_position_percent
    type: int
    restore_value: no
    initial_value: "0"
  - id: cover_calibrated
    type: bool
    restore_value: yes
    initial_value: "false"
  - id: cover_travel_up_ms
    type: uint32_t
    restore_value: yes
    initial_value: "0"
  - id: cover_travel_down_ms
    type: uint32_t
    restore_value: yes
    initial_value: "0"
  - id: cover_calib_phase
    type: int
    restore_value: no
    initial_value: "0"
  - id: cover_calib_start_ms
    type: uint32_t
    restore_value: no
    initial_value: "0"
  - id: cover_calib_temp_up_ms
    type: uint32_t
    restore_value: no
    initial_value: "0"
  - id: cover_calib_temp_down_ms
    type: uint32_t
    restore_value: no
    initial_value: "0"
  - id: cover_runtime_direction
    type: int
    restore_value: no
    initial_value: "0"
  - id: cover_movement_started_ms
    type: uint32_t
    restore_value: no
    initial_value: "0"
  - id: cover_movement_auto_stop_ms
    type: uint32_t
    restore_value: no
    initial_value: "0"
  - id: cover_movement_start_position
    type: int
    restore_value: no
    initial_value: "255"
  - id: cover_movement_target_position
    type: int
    restore_value: no
    initial_value: "255"
  - id: cover_movement_targets_end
    type: bool
    restore_value: no
    initial_value: "false"
  - id: cover_movement_targets_intermediate
    type: bool
    restore_value: no
    initial_value: "false"
  - id: cover_last_relay_change_ms
    type: uint32_t
    restore_value: no
    initial_value: "0"
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

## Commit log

2026-06-07 chore: prepare public English release of ESP32 smart home project
    [Abdeckung.3mf, Abdeckung_oben_V2.3mf, Abdeckung_unten_V2.3mf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]
2026-06-08 refactor: separate esphome track from firmware story
2026-06-08 fix: remove private KiCad plot paths
2026-06-22 docs: add GitHub Pages landing page
    Interactive single-page site in docs/index.html for GitHub Pages.
    - Bilingual DE/EN toggle (body class lang-de / lang-en)
    - Decision wizard: 4 questions, scoring, Custom / ESPHome / Both result
    - Step-by-step guides: Custom Firmware track and ESPHome track
    - Device catalog with GPIO pin tables from source
    - Base-to-device firmware adaptation guide (6 steps)
    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

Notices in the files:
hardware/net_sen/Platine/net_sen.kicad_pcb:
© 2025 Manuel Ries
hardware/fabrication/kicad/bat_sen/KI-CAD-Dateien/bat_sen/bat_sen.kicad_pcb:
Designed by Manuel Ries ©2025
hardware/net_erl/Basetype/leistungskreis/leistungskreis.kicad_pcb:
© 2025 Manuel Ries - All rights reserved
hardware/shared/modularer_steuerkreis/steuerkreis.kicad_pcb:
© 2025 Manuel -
